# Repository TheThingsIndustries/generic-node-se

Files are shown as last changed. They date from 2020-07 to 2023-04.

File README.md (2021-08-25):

# Generic Node Sensor Edition (GNSE)

## About

LoRaWAN promised you roaming, secure and low-cost sensors that last on a battery for years. _Generic Node_ platform delivers this promise with additional strong end to end encryption and firmware over the air update in a device with multiple sensors that can be configured and programmed to support many use cases.

This repository contains all the necessary hardware and software files for the GNSE LoRaWAN node. The core of the system is based off the STM32WL55xx dual-core LoRaWAN SOC.

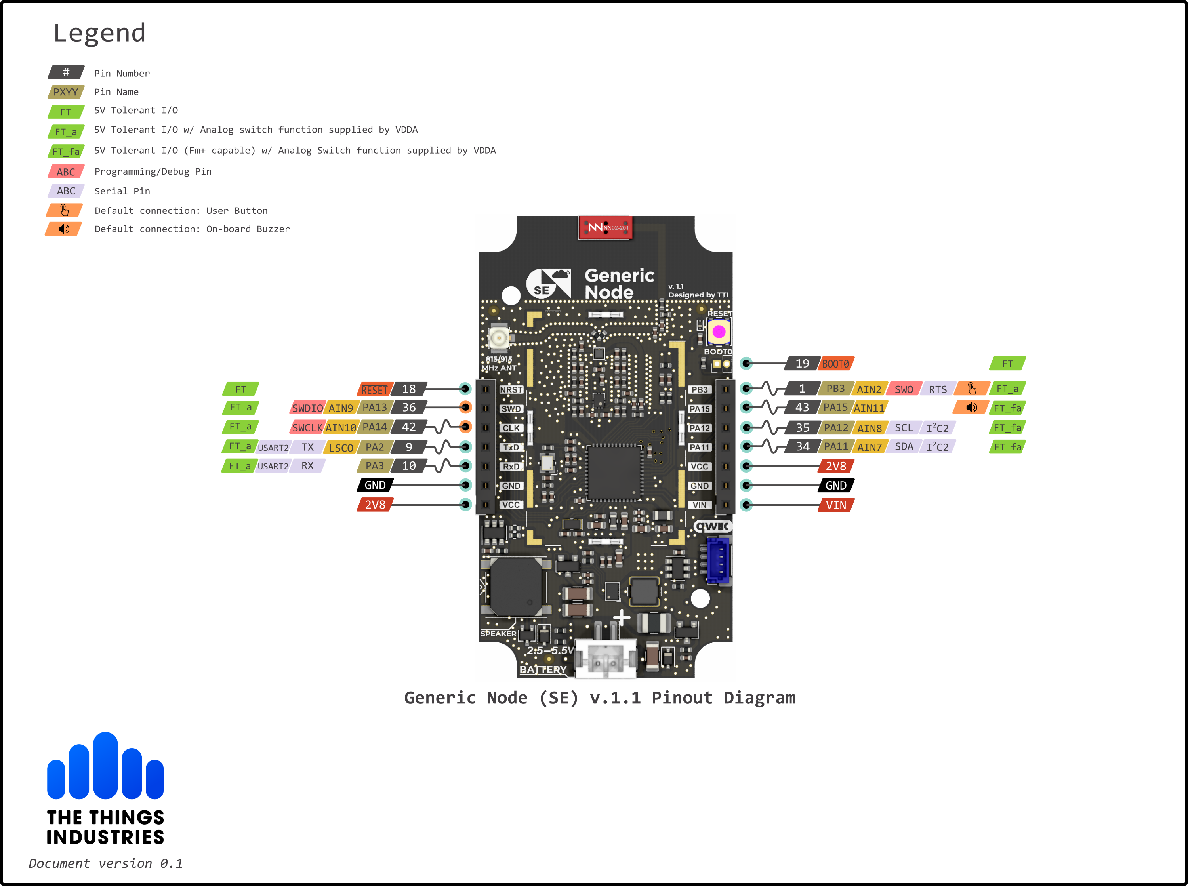
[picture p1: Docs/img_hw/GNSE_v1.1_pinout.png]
Generic Node Main PCB (front)


## Specification
- [STM32WL55CCU6](https://www.st.com/en/microcontrollers-microprocessors/stm32wl-series.html) dual-core Arm Cortex®-M4/M0+ @48 MHz
- 256 Kbytes of Flash & 64 Kbytes of SRAM
- SX126x sub-GHz radio
- Power output up to +22.00 dBm
- LoRa, (G)FSK, (G)MSK, BPSK modulations
- 868 MHz & 915 MHz dual-band operation
- 2xAA battery powered node with wide input voltage range: 2.2V - 5.5V
- [ATECC608A-TNGLORA](https://www.microchip.com/wwwproducts/en/ATECC608A-TNGLORA) pre-provisioned LoRaWAN secure element
- [LIS2DH12](https://www.st.com/en/mems-and-sensors/lis2dh12.html) - ULP 3-axis accelerometer
- [SHTC3](https://www.sensirion.com/en/environmental-sensors/humidity-sensors/digital-humidity-sensor-shtc3-our-new-standard-for-consumer-electronics/) humidity and temperature sensor
- [MX25R1635](https://www.macronix.com/en-us/products/NOR-Flash/Serial-NOR-Flash/Pages/default.aspx) 16Mb SPI NOR Flash for FUOTA and data-logging
- A user button, an RGB LED, a buzzer and a user-friendly expansion and programming options.

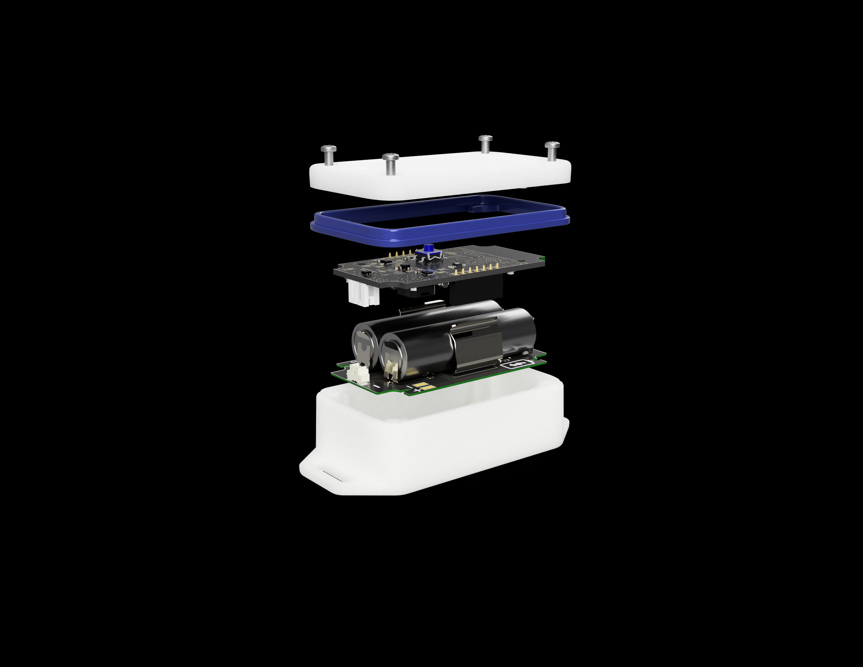
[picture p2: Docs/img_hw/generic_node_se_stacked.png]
Generic Node


## Development

The necessary schematics and the PCB files can be found in [Hardware](./Hardware).

Software libraries and sample applications can be found in [Software](./Software).

## Documentation

The [Generic Node documentation website](https://www.genericnode.com/docs/) provides information about the node hardware and software features.

## Contribution

Our [contribution guideline](./CONTRIBUTING.md) provides more information on how to assist us with the development of GNSE.

## Legal

[Generic Node license terms and conditions](./LICENSE.md) apply.

[Contact The Things Industries](https://thethingsindustries.com/contact/) for licensing.

Copyright © 2021 The Things Industries B.V.

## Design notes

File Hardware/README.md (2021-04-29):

# GNSE Hardware
The reference design hardware provides the needed resources for device production, and the design can be tailored to serve a specific use case.

## Structure

- [sch](./sch/) folder contains the schematics files
- [lib](./lib/) folder contains [KiCad](https://kicad.org/) design libraries
- [pcb-stm32wl](./pcb-stm32wl/) folder contains the layout of the core STM32WL PCB
- [pcb-bolink-batteryHolder](./pcb-bolink-batteryHolder/) folder contains the layout of the bolink enclosure battery holder PCB
- [fab](./fab/) contains fabrication related files such as bill of materials(bom) and gerber files

> Please [contact The Things Industries](https://thethingsindustries.com/contact/) for the latest HW fabrication files

## Documentation

The [Generic Node documentation website](https://www.genericnode.com/docs/) provides information about the hardware features and how to [get started with the hardware development](https://www.genericnode.com/docs/getting-started/se-hw/).

## Legal
Copyright © 2021 The Things Industries B.V.

[Contact The Things Industries](https://thethingsindustries.com/contact/) for licensing.

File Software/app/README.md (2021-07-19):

# Applications

This folder contains various sample applications.

## Applications description

[basic](./basic) contains the simplest application of on-board peripherals activation to ensure responsiveness and basic functionality of the various components.

[basic_lorawan](./basic_lorawan) contains a simple application of LoRaWAN where a class A device joins via OTAA and sends dummy payloads triggered by a time interval or a push button.
The device enters stop mode in between transmissions to reduce power consumption.

[basic_bootloader](./basic_bootloader) contains a bootloader that allows for application/internal bootloader jumps.

[basic_freertos](./basic_freertos) contains a basic FreeRTOS low power application that creates two threads that pass a message via a queue triggering a blinking LED with each passed message.

[freefall_lorawan](./freefall_lorawan) contains a simple application to join via OTAA and waits to send a message until the device is free-falling. A downlink on port 1 will cause the buzzer to beep, which can be turned off with a button press.

[freertos_lorawan](./basic_freertos) contains a multi-thread FreeRTOS LoRaWAN Class A demo app that joins over OTAA and sends uplink data.

[secure_element_lorawan](./secure_element_lorawan) contains a LoRaWAN application where a class A device joins via OTAA (LoRaWAN v1.0.2) using a HW secure element (ATECC608A-TNGLORA) and sends dummy payloads triggered by a time interval.
This app does not require LoRaWAN keys/EUI configurations. Follow this [tutorial](https://www.thethingsindustries.com/docs/devices/claim-atecc608a/) to claim your device, and your device will join via OTAA automatically.

[basic_azurertos](./basic_azurertos) contains a simple AzureRTOS (ThreadX) application. It includes examples of two threads that pass a message via a queue triggering a blinking LED with each passed message.

[sensors_lorawan](./sensors_lorawan) contains an application that sends sensors data such as battery voltage, temperature and humidity over LoRaWAN.

[basic_fuota](./basic_fuota) contains an application that attempts to do an interoperability test of firmware updates over the air.
The app synchronizes the clock with the application server via `AppTimeReq & Ans` commands and then creates a multicast group and a fragmentation session to receive firmware packets over LoRaWAN.

## Applications configuration

Each application contains a configuration folder that facilitates minor adjustments to the application behavior.

LoRaWAN credentials must be configured to ensure successful uplinks/ OTAA joins.
LoRaWAN applications using the onboard secure element require minimum configurations as the keys and EUIs are stored internally within the hardware secure element.

To quickly get started, navigate to your application `app_conf.h`, and adjust the parameters.

[basic app configurations](./basic/conf/app_conf.h)

[basic_lorawan app configurations](./basic_lorawan/conf/app_conf.h)

[basic_bootloader app configurations](./basic_bootloader/conf/app_conf.h)

[basic_freertos app configurations](./basic_freertos/conf/app_conf.h)

[freefall_lorawan app configurations](./freefall_lorawan/conf/app_conf.h)

[freertos_lorawan app configurations](./basic_freertos/conf/app_conf.h)

[secure_element_lorawan app configurations](./secure_element_lorawan/conf/app_conf.h)

[basic_azurertos app configurations](./basic_azurertos/conf/app_conf.h)

[sensors_lorawan app configurations](./sensors_lorawan/conf/app_conf.h)

[basic_fuota app configurations](./basic_fuota/conf/app_conf.h)

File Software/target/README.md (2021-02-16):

# Target
STM32WL low level target files.

[CMSIS](./CMSIS) is arm Cortex Microcontroller Software Interface Standard hardware/vendor abstraction layer.

[stm32wlxx_hal_driver](./stm32wlxx_hal_driver) is maintained as subtree based on [STM32WL HAL](https://github.com/STMicroelectronics/stm32wlxx_hal_driver) and it includes the hardware abstraction layer drivers of the STM32WL SOC.

[FreeRTOS_CMSIS](./FreeRTOS_CMSIS) is FreeRTOS abstraction layer for ST SOC.

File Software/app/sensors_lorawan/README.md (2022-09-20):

# sensosrs_lorawan

## Description

This application samples the on-board device sensors information and transmits the sensor data over LoRaWAN.

## Configuration

The application behavior can be adjusted by modifying [`conf/app_conf.h`](./conf/app_conf.h).

- `GNSE_ADVANCED_TRACER_ENABLE` enables UART (115200/8-N-1) logging of application activity

```c
#define GNSE_ADVANCED_TRACER_ENABLE 1
```

- `DEBUGGER_ON` enables the use of a debugger in low power mode

```c
#define DEBUGGER_ON       1
```

> **Note:** Please keep in mind that it is best to disable the tracer and debugger functionalities to reduce power consumption.

- `APPEUI`, `DEVEUI` and `APPKEY` allow the device to join the LoRaWAN network via OTAA.

```c
#define APPEUI                 0x00, 0x00, 0x00, 0x00, 0x00, 0x00, 0x00, 0x00

#define DEVEUI                 0x00, 0x00, 0x00, 0x00, 0x00, 0x00, 0x00, 0x00

#define APPKEY                 0x00, 0x00, 0x00, 0x00, 0x00, 0x00, 0x00, 0x00, 0x00, 0x00, 0x00, 0x00, 0x00, 0x00, 0x00, 0x00
```

> **Note:** The default `0x00` is a place holder and you are required to change these values in order to achieve a successful activation. For testing purposes, these values can be random.

- `SENSORS_PAYLOAD_APP_PORT` defines LoRaWAN application port where sensors information can be retrieved by the application server.

```c
#define SENSORS_PAYLOAD_APP_PORT        2
```

- `SENSORS_TX_DUTYCYCLE` in millisecond defines the application data transmission interval.

```c
#define SENSORS_TX_DUTYCYCLE                            10000
```

## Setup

The application can be used with the following Javascript payload formatter:

```javascript
function decodeUplink(input) {
  var data = {};
  data.batt_volt = (input.bytes[0]/10);
  data.temperature = (((input.bytes[1] << 8) + input.bytes[2]) - 500)/10;
  data.humidity = ((input.bytes[3] << 8) + input.bytes[4])/10;
  data.button = input.bytes[5];

  return {
    data: data,
  };
}
```
Please see [The Things Stack Javascript payload formatter documentation](https://www.thethingsindustries.com/docs/integrations/payload-formatters/javascript/) for more information.

## Observation

The device joins via OTAA, and transmits the temperature, humidity and battery voltage information every `SENSORS_TX_DUTYCYCLE`.

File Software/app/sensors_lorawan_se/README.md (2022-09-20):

# sensors_lorawan_se

## Description

This application samples the on-board device sensors information and transmits the sensor data over LoRaWAN and showcases a HW secure element (ATECC608A-TNGLORA).
You can learn more about LoRaWAN and HW secure elements from [here](https://www.thethingsindustries.com/secure-elements/) and [here](https://www.thethingsindustries.com/docs/devices/atecc608a/).

## Configuration

The application behavior can be adjusted by modifying [`conf/app_conf.h`](./conf/app_conf.h).

- `GNSE_ADVANCED_TRACER_ENABLE` enables UART (115200/8-N-1) logging of application activity

```c
#define GNSE_ADVANCED_TRACER_ENABLE 1
```

- `DEBUGGER_ON` enables the use of a debugger in low power mode

```c
#define DEBUGGER_ON       1
```

> **Note:** Please keep in mind that it is best to disable the tracer and debugger functionalities to reduce power consumption.

- `APPEUI`, `DEVEUI` and `APPKEY` allow the device to join the LoRaWAN network via OTAA.

```c
#define APPEUI                 0x00, 0x00, 0x00, 0x00, 0x00, 0x00, 0x00, 0x00

#define DEVEUI                 0x00, 0x00, 0x00, 0x00, 0x00, 0x00, 0x00, 0x00

#define APPKEY                 0x00, 0x00, 0x00, 0x00, 0x00, 0x00, 0x00, 0x00, 0x00, 0x00, 0x00, 0x00, 0x00, 0x00, 0x00, 0x00
```

> **Note:** The default `0x00` is a place holder and you are required to change these values in order to achieve a successful activation. For testing purposes, these values can be random.

- `SENSORS_PAYLOAD_APP_PORT` defines LoRaWAN application port where sensors information can be retrieved by the application server.

```c
#define SENSORS_PAYLOAD_APP_PORT        2
```

- `SENSORS_TX_DUTYCYCLE` in minutes defines the application data transmission interval.

```c
#define SENSORS_TX_DUTYCYCLE                            10
```

## Setup

Follow this [tutorial](https://www.thethingsindustries.com/docs/devices/claim-atecc608a/) to claim your device, and your device will join via OTAA automatically.

The application can be used with the following Javascript payload formatter:

```javascript
function decodeUplink(input) {
  var data = {};
  data.batt_volt = (input.bytes[0]/10);
  data.temperature = (((input.bytes[1] << 8) + input.bytes[2]) - 500)/10;
  data.humidity = ((input.bytes[3] << 8) + input.bytes[4])/10;
  data.button = input.bytes[5];

  return {
    data: data,
  };
}
```
Please see [The Things Stack Javascript payload formatter documentation](https://www.thethingsindustries.com/docs/integrations/payload-formatters/javascript/) for more information.

## Observation

The device joins via OTAA using the on-board secure element and transmits the temperature, humidity and battery voltage information every `SENSORS_TX_DUTYCYCLE`.

## Secure element usage

To compile the app with secure element support, use the `-DWITH_SECURE_ELEMENT=ON` flag
when generating cmake configuration.

To compile without the secure element and with hardcoded keys instead, 
use the `-DWITH_SECURE_ELEMENT=OFF` flag and define the keys in `conf/app_conf.h`

For example:
```bash
cmake ../.. -DWITH_SECURE_ELEMENT=OFF -DCMAKE_BUILD_TYPE=Debug -DCMAKE_TOOLCHAIN_FILE=../../cross.cmake -DTARGET_APP=sensors_lorawan
```

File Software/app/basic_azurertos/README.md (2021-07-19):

# basic_azurertos

## Description

This application provides a basic example of [Microsoft Azure RTOS](https://azure.microsoft.com/en-us/services/rtos/) functionality.

The application creates two threads and a message queue. Thread 1 attempts to pass a message to thread 2 via the queue and then sleeps for `TX_DELAY`. Thread 2 blinks the LED when the sent message is successfully received.

## Configuration

The application behavior can be adjusted by modifying [`conf/app_conf.h`](./conf/app_conf.h).

Key configurations are stated below:

### Azure RTOS

- `MEM_BYTE_POOL_SIZE`,`THREAD_STACK_SIZE`,`QUEUE_SIZE` in bytes defines Azure RTOS memory pool, threads and queue sizes

```c
#define MEM_BYTE_POOL_SIZE 9120

#define THREAD_STACK_SIZE 1024

#define QUEUE_SIZE 100
```

### App activity

- `GNSE_TINY_TRACER_ENABLE` enables UART (115200/8-N-1) logging of application activity

```c
#define GNSE_TINY_TRACER_ENABLE 1
```

- `TX_DELAY` in milliseconds defines the message passing rate from thread 1 to thread 2.

```c
#define TX_DELAY                 (5000)
```

## Observation

The device blinks the blue LED every `TX_DELAY` on each successful message passing between thread 1 and thread 2.

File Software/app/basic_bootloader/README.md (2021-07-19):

# basic_bootloader

## Description

The application provides a basic bootloader that can be combined with other applications to perform a specific functionality at boot time.

> If you want to learn more about the purpose of a bootloader, we recommend reading this great [blog post](https://interrupt.memfault.com/blog/how-to-write-a-bootloader-from-scratch).

`basic_bootloader` performs one of two functionalities based on the GNSE button:

1. If the button is not pressed -> boots the user flashed application
2. If the button is pressed long enough -> boots the ST internal bootloader

## Configuration

`basic_bootloader` key configurations:

### Memory Map

The internal flash (ROM) memory map can be configured to accommodate a bootloader and an application by adjusting the parameters defined in [`memory_map.ld`](./../../target/memory_map.ld).

```
BOOTROM  (rx)  : ORIGIN = 0x08000000, LENGTH = 0x00000B000   /* Flash memory dedicated to bootloader */
APPROM   (rx)  : ORIGIN = 0x0800B000, LENGTH = 0x000035000   /* Flash memory dedicated to application */
```

### App activity

The application behavior can be adjusted by modifying [`conf/app_conf.h`](./conf/app_conf.h).

- `GNSE_TINY_TRACER_ENABLE` enables UART (115200/8-N-1) logging of application activity

```c
#define GNSE_TINY_TRACER_ENABLE 1
```

> Please note that it is considered as a best practice to disable logging when building bootloaders to reduce the binary size.

## Setup

To build a `basic_bootloader` that can be combined with another application in the same memory, you need to use a linker script that supports the new memory map.

### Building with CMake

If you are building using CMake, then update [`CMakeLists.txt`](./../../CMakeLists.txt) `LINKER_SCRIPT` flag to `bootloader.ld` when compiling a `basic_bootloader` binary.

```
set(LINKER_SCRIPT ${MCU_DIR}/bootloader.ld)
```

Also, make sure to update `LINKER_SCRIPT` flag to `app.ld` when compiling an application binary that will be combined with the bootloader binary.

```
set(LINKER_SCRIPT ${MCU_DIR}/app.ld)
```

### Building with STM32CubeIDE

If you are building using STM32CubeIDE, then there is no need to change the linker script when building a `basic_bootloader` binary as can be seen below.

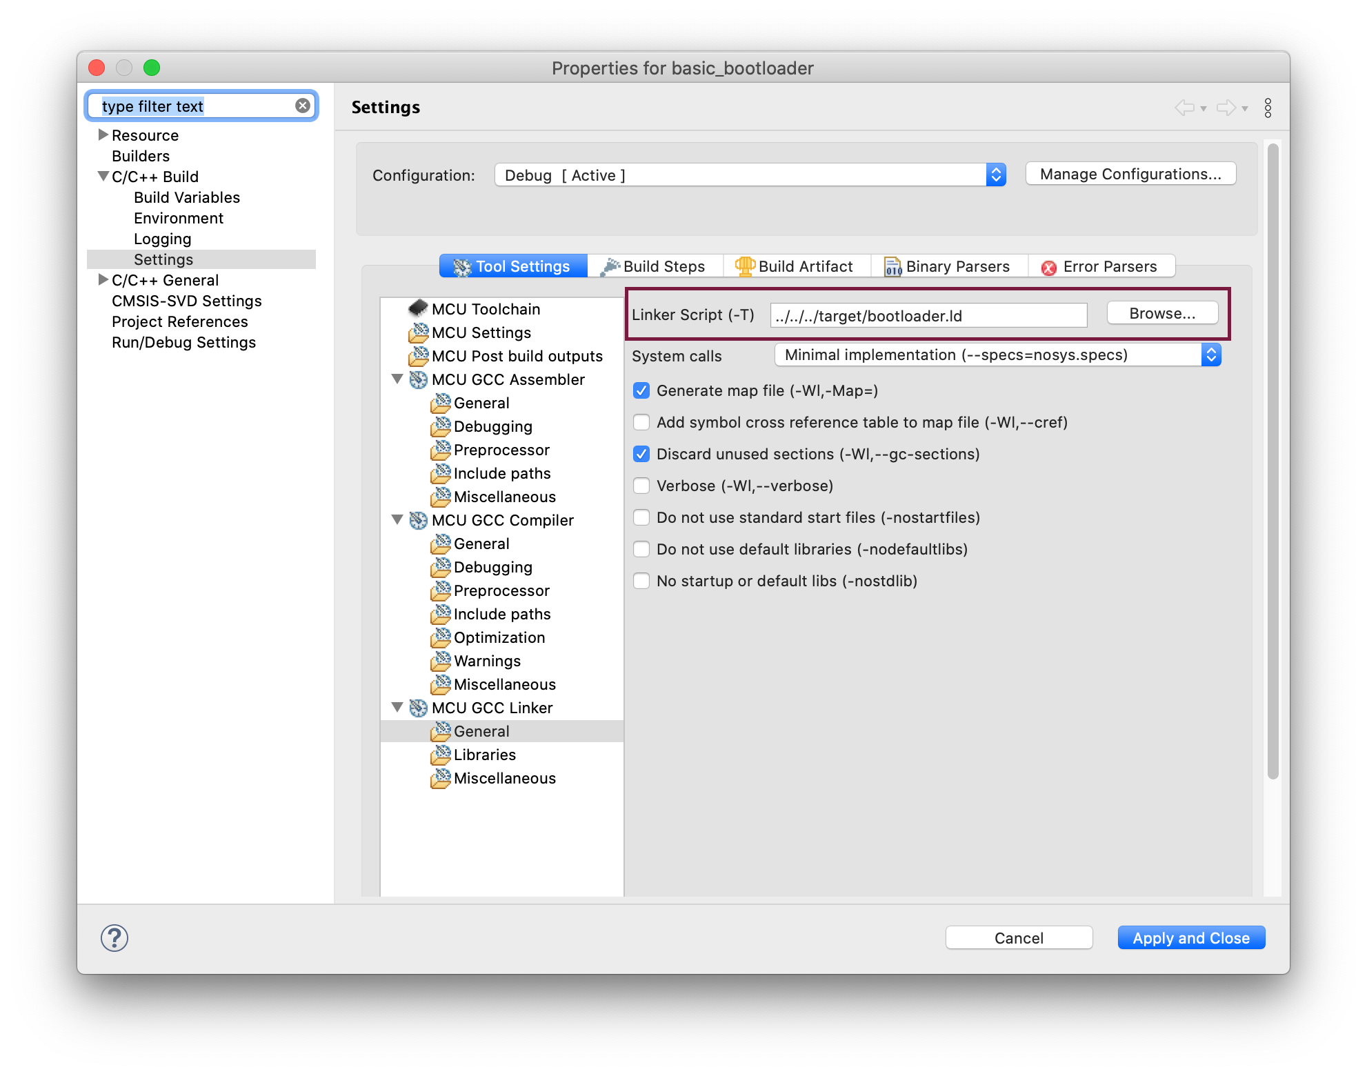
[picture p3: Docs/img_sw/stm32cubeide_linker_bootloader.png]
basic_booloader STM32CubeIDE linker config


But, make sure to change the application linker script from `../../../target/stm32wl55xx_flash.ld` to `../../../target/app.ld`.

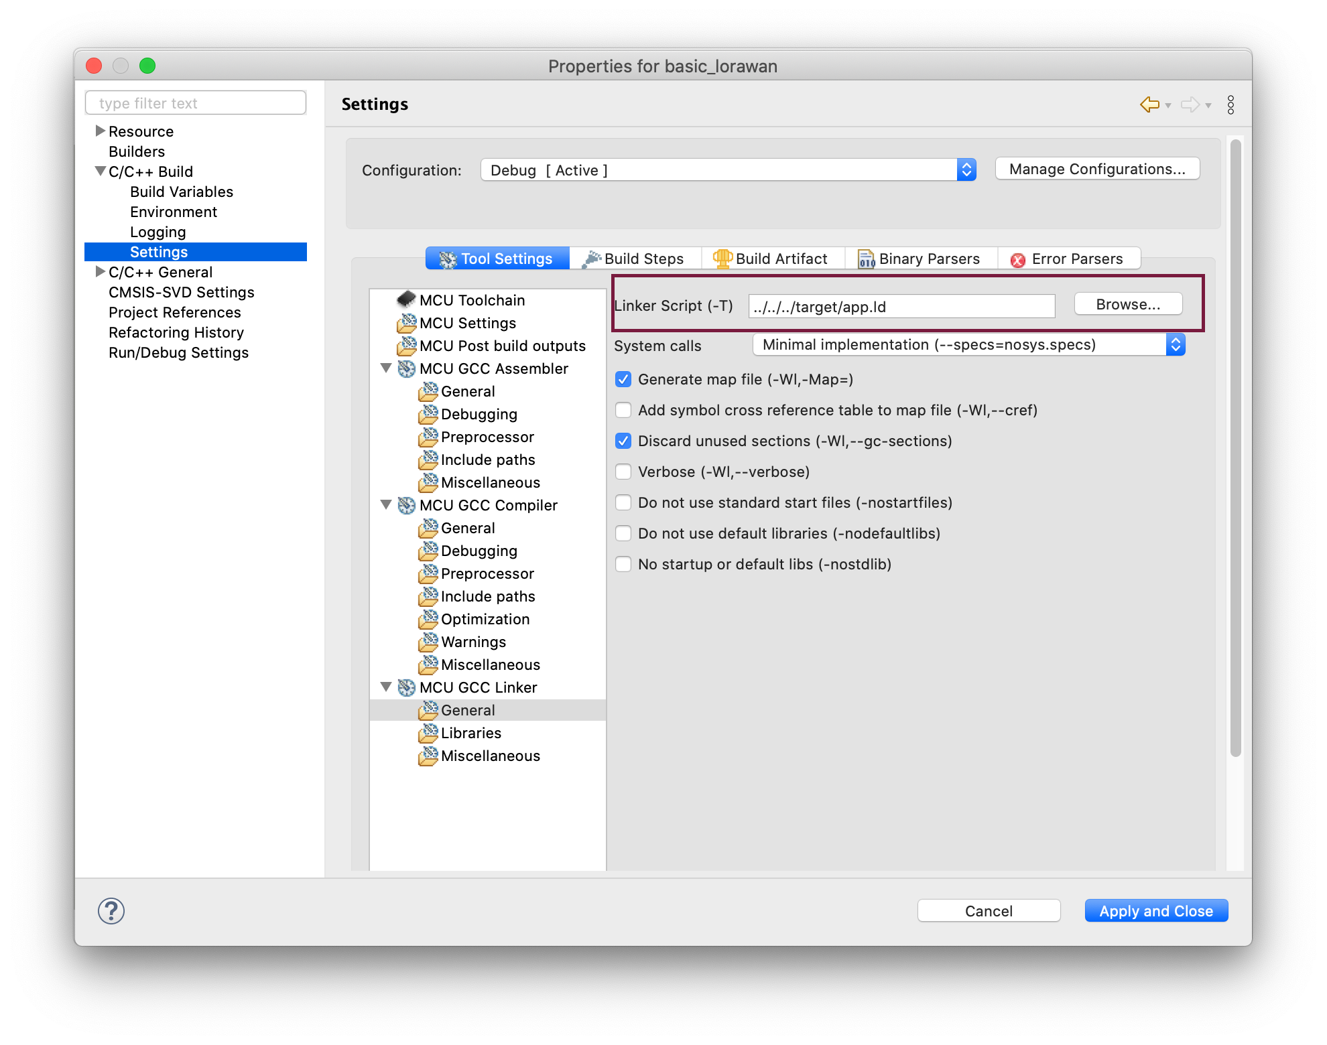
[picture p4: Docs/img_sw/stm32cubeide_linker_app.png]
basic_lorawan STM32CubeIDE linker config


### Combining applications

You can combine two binaries such as the `basic_bootloader` and `basic_lorawan` by using the [`bootloader_app_merge` python script](./../../bootloader_app_merge.py).

For example:

```sh
python bootloader_app_merge.py \
-b ./build/debug/app/basic_bootloader/main.bin \
-a ./build/debug/app/basic_lorawan/main.bin \
-s 1 \
-d 0xB000 \
-c 0xB008 \
-o ./build/debug/app/basic_lorawan/boot_basic_lorawan.bin
```

## Observation

The device boots and turns on the red LED.

If the button is not pressed, the red LED will stay on for a small period and the device will boot the user-flashed application.

If the button is pressed for long enough, it will turn on the blue LED and turn off the red LED, indicating a successful input and it will continue to boot the ST internal bootloader.

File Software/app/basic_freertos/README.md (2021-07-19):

# basic_freertos

## Description

This application provides a basic example of [Amazon FreeRTOS](https://docs.aws.amazon.com/freertos/index.html) functionality.

The application creates two threads and a message queue. Thread 1 attempts to pass a message to thread 2 via the queue and then sleeps for `TX_DELAY`. Thread 2 blinks the LED when the sent message is successfully received.

## Configuration

Key configurations are stated below:

### FreeRTOS

FreeRTOS configurations can be adjusted by modifying [`conf/FreeRTOSConfig.h`](./conf/FreeRTOSConfig.h).

```c
#define configMINIMAL_STACK_SIZE                 ((uint16_t)128)

#define configTOTAL_HEAP_SIZE                    ((size_t)8120)
```

### App activity

The application behavior can be adjusted by modifying [`conf/app_conf.h`](./conf/app_conf.h).

- `GNSE_TINY_TRACER_ENABLE` enables UART (115200/8-N-1) logging of application activity

```c
#define GNSE_TINY_TRACER_ENABLE 1
```

- `TX_DELAY` in milliseconds defines the message passing rate from thread 1 to thread 2.

```c
#define TX_DELAY                 (5000)
```

## Observation

The device blinks the blue LED every `TX_DELAY` on each successful message passing between thread 1 and thread 2.

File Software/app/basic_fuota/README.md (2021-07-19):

# basic_fuota

## Description

This application provides a basic example of LoRaWAN FUOTA (Firmware Update Over The Air) functionality based on:

- [LoRaWAN Remote Multicast Setup Specification v1.0.0.](https://lora-alliance.org/resource_hub/lorawan-remote-multicast-setup-specification-v1-0-0/)
- [LoRaWAN Fragmented Data Block Transport Specification v1.0.0.](https://lora-alliance.org/resource_hub/lorawan-fragmented-data-block-transport-specification-v1-0-0/)
- [LoRaWAN Application Layer Clock Synchronization Specification v1.0.0.](https://lora-alliance.org/resource_hub/lorawan-application-layer-clock-synchronization-specification-v1-0-0/)

`basic_fuota` provides an example on how to:

- Synchronize the device clock via `AppTimeReq & Ans`
- Setup a multicast group via `McGroupSetupReq & Ans`
- Setup a class C session via `McClassCsessionReq & Ans`
- Setup a fragmentation session via `FragSessionSetupReq & Ans`
- Transfer fragmented data and do CRC32 check to confirm data correctness

## Configuration

Below are key configurations:

### Fragmentation

This application performs the FUOTA interoperability test, and the number of fragmented bytes can be modified from the default values of 995 bytes in [`FragDecoder.h`](./../../lib/STM32WLxx_LoRaWAN/LoRaWAN/LmHandler/Packages/FragDecoder.h)

```c
#define FRAG_MAX_NB                                 21

#define FRAG_MAX_SIZE                               50
```

### App activity

The application behavior can be adjusted by modifying [`conf/app_conf.h`](./conf/app_conf.h).

- `GNSE_ADVANCED_TRACER_ENABLE` enables UART (115200/8-N-1) logging of application activity

```c
#define GNSE_ADVANCED_TRACER_ENABLE 1
```

- `DEBUGGER_ON` enables the use of a debugger in low power mode

```c
#define DEBUGGER_ON       1
```

> **Note:** Please keep in mind that it is best to disable the tracer and debugger functionalities to reduce power consumption.

- `APPEUI`, `DEVEUI` and `APPKEY` allow the device to join the LoRaWAN network via OTAA.

```c
#define APPEUI                 0x00, 0x00, 0x00, 0x00, 0x00, 0x00, 0x00, 0x00

#define DEVEUI                 0x00, 0x00, 0x00, 0x00, 0x00, 0x00, 0x00, 0x00

#define APPKEY                 0x00, 0x00, 0x00, 0x00, 0x00, 0x00, 0x00, 0x00, 0x00, 0x00, 0x00, 0x00, 0x00, 0x00, 0x00, 0x00
```

> **Note:** The default `0x00` is a place holder and you are required to change these values in order to achieve a successful activation. For testing purposes, these values can be random.

## Setup

### Device setup

- Follow [this](https://www.thethingsindustries.com/docs/devices/adding-devices/) guide to add your device to The Things Stack.

### Server setup

- You can use this example to [test FUOTA server](https://github.com/elsalahy/test-fuota-server) as starting point and you can follow the [`README.md`](https://github.com/elsalahy/test-fuota-server/blob/master/README.md) in order to set it up with a minimal effort.

## Observation

This [video](https://drive.google.com/file/d/1RnhQjbfYMriDybziEVhzww6uxYF-QaNV/view?usp=sharing) provides a recorded example of the communication between the device and the application server.

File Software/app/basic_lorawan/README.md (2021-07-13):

# basic\_lorawan

## Description

`basic_lorawan` serves as a basic template for LoRaWAN applications.

## Configuration

### Default

1. Follow [this](https://www.thethingsindustries.com/docs/devices/adding-devices/) guide to add your device to The Things Stack.
2. Change the `APPEUI`, `DEVEUI` and `APPKEY` in [`conf/app_conf.h`](./conf/app_conf.h) to the values specific to your device, which are used on The Things Stack.
3. Uncomment the `REGION` parameters in [`conf/lorawan_conf.h`](./conf/lorawan_conf.h) and set `ACTIVE_REGION` in [`lora_app.h`](./lora_app.h). These should correspond to the location that you use these devices at.

### Low power

1. Set `GNSE_ADVANCED_TRACER_ENALBE` to `0` in [`conf/app_conf.h`](./conf/app_conf.h). This will make the device consume less power, but also disables UART.
2. Set `DEBUGGER_ON` to `0` in [`conf/app_conf.h`](./conf/app_conf.h).

Additionally, try to remember that:

- Setting `DEBUGGER_ON` to `1` will consume more power. The debugger is ON by default using the macro `DEBUGGER_ON` in [`conf/app_conf.h`](./conf/app_conf.h).
- Keeping peripherals (such as the sensors) off by controlling the load switches will significantly reduce the power consumption.
- The less transmissions over time, the lower the power consumption will be. This is set by `APP_TX_DUTYCYCLE` in [`lora_app.h`](./lora_app.h).

### LoRa extra's

Some extra setup configurations can be done to change the behaviour of the LoRaWAN features. These include:

1. Setting the activation method (OTAA or ABP) in `LORAWAN_DEFAULT_ACTIVATION_TYPE` in [`lora_app.h`](./lora_app.h). OTAA [is recommended](https://www.thethingsindustries.com/docs/devices/abp-vs-otaa/).
2. The data rate can be set in [`lora_app.h`](./lora_app.h). The default configuration uses the ADR. Should you want to set your preferred data rate, set `LORAWAN_ADR_STATE` to `LORAMAC_HANDLER_ADR_OFF` and set `LORAWAN_DEFAULT_DATA_RATE` to your preference. A list of the options per region are shown in [`Region.h`](../../lib/STM32WLxx_LoRaWAN/LoRaWAN/Mac/region/Region.h) in the [`STM32WLxx_LoRaWAN`](../../lib/STM32WLxx_LoRaWAN) library.
3. `ACC_FF_LORA_PORT` can be changed in [`conf/app_conf.h`](./conf/app_conf.h), which is used to configure the transmission port. The LoRaWAN keys mentioned in the default section can be altered here as well.

### Debugger

For debugging, the firmware has to support it first. The debugger is set in the macro `DEBUGGER_ON` in [`conf/app_conf.h`](./conf/app_conf.h).

## Observation

The standard payload is "**AA BB CC**", which will repeat periodically, with intervals set in `APP_TX_DUTYCYCLE` in [`lora_app.h`](./lora_app.h). The UART output can be read through the TX/RX lines, which can be used for debugging. The default UART configuration is set to 115200/8-N-1. If nothing can be seen on The Things Stack Console, then you could check from this debug output if:

1. The correct keys are used, i.e. they match the ones printed at the start of the application.
2. The device is connecting properly, as it will indicate if connections have failed or not. It should display something like this:

```
###### = JOINED = OTAA =====================
```

3. The device is transmitting anything, since each event is also logged via the UART lines. It should display something similar to:

```
###### ========== MCPS-Confirm =============
###### U/L FRAME:0005 | PORT:2 | DR:5 | PWR:0 | MSG TYPE:UNCONFIRMED
60s069:TX on freq 868500000 Hz at DR 5
60s080:SEND REQUEST
```

4. Downlinks are detected only if used. These only occur after being explicitly set on The Things Stack Console or another application, and will only be transmitted after the transmission of an uplink by the device. The GNSE should, after receiving the downlink, display something similar to:

```
 ###### ========== MCPS-Indication ==========

 ###### D/L FRAME:0002 | SLOT:1 | PORT:1 | DR:5 | RSSI:-44 | SNR:15

 Received 3 bytes on undefined port: 2
```

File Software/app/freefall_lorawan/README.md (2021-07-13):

# freefall\_lorawan

## Description

This application is used to detect free fall events and also serves as a template for acceleration detection handling. Each time a free fall event is detected by the accelerometer, a message containing a counter in the payload is sent. The transmitted value is incremented each time the event occurs. Additionally, if a downlink is received over the correct port, which can be configured by the user, the buzzer will beep periodically to notify locally that the GNSE should be picked up. The buzzer can be turned off by pressing the user button.

## Configuration

### Default
1. Follow [this](https://www.thethingsindustries.com/docs/devices/adding-devices/) guide to add your device to The Things Stack.
2. Change the `APPEUI`, `DEVEUI` and `APPKEY` in [`conf/app_conf.h`](./conf/app_conf.h) to the values specific to your device, which are used on The Things Stack.
3. Uncomment the `REGION` parameters in [`conf/lorawan_conf.h`](./conf/lorawan_conf.h) and set `ACTIVE_REGION` in [`lora_app.h`](./lora_app.h). These should correspond to the location that you use these devices at.

### Free fall detection
1. Change `ACC_FF_THRESHOLD` in [`app/conf.h`](./conf/app_conf.h) to a value you prefer. This will determine the threshold where all axis can be from 0g (which would indicate that it is free falling) to be considered a free fall event.
2. Change `ACC_FF_DURATION` in [`app/conf.h`](./conf/app_conf.h) to a value you prefer. This will determine how many times the axis have to meet the threshold values. Note that `ACC_FF_ODR` in the same file also affects this.
3. `ACC_FF_SCALE` in [`app/conf.h`](./conf/app_conf.h) could also be changed for situations where more than 2g has to be detected. [`LIS2DH12.h`](../../lib/LIS2DH12/LIS2DH12.h) in the [`LIS2DH12`](../../lib/LIS2DH12/) library lists all the options for this in the full scale section.
4. `ACC_FF_ODR` in [`app/conf.h`](./conf/app_conf.h) could be lowered to save power, or increased to improve performance. [`LIS2DH12.h`](../../lib/LIS2DH12/LIS2DH12.h) in the [`LIS2DH12`](../../lib/LIS2DH12/) library lists all the options for this in the `ODR` section.

### Low power

1. Set `GNSE_ADVANCED_TRACER_ENALBE` to `0` in [`conf/app_conf.h`](./conf/app_conf.h). This will make the device consume less power, but also disables UART.
2. Set `DEBUGGER_ON` to `0` in [`conf/app_conf.h`](./conf/app_conf.h).
3. Set `ACC_FF_ODR` in [`app/conf.h`](./conf/app_conf.h) to a lower value if the decreased performance of the free fall detection does not matter for your setup. [`LIS2DH12.h`](../../lib/LIS2DH12/LIS2DH12.h) in the [`LIS2DH12`](../../lib/LIS2DH12/) library lists all the options for this.

Additionally, try to remember that:

- Setting `DEBUGGER_ON` to `1` will consume more power. The debugger is ON by default using the macro `DEBUGGER_ON` in [`conf/app_conf.h`](./conf/app_conf.h).
- Keeping peripherals (such as the sensors) off by controlling the load switches will significantly reduce the power consumption. But, of course, you can not turn the load switch connected to the accelerometer off without disabling the free fall detection as well.

### LoRa extra's

Some extra setup configurations can be done to change the behaviour of the LoRaWAN features. These include:

1. Setting the activation method (OTAA or ABP) in `LORAWAN_DEFAULT_ACTIVATION_TYPE` in [`lora_app.h`](./lora_app.h). OTAA [is recommended](https://www.thethingsindustries.com/docs/devices/abp-vs-otaa/).
2. The data rate can be set in [`lora_app.h`](./lora_app.h). The default configuration uses the ADR. If you want to set your preferred data rate, set `LORAWAN_ADR_STATE` to `LORAMAC_HANDLER_ADR_OFF` and set `LORAWAN_DEFAULT_DATA_RATE` to your preference. A list of the options per region are shown in [`Region.h`](../../lib/STM32WLxx_LoRaWAN/LoRaWAN/Mac/region/Region.h) in the [`STM32WLxx_LoRaWAN`](../../lib/STM32WLxx_LoRaWAN) library.
3. `ACC_FF_LORA_PORT` can be changed in [`conf/app_conf.h`](./conf/app_conf.h), which is used to configure the transmission port. The LoRaWAN keys mentioned in the default section can be altered here as well.
4. Also in [`conf/app_conf.h`](./conf/app_conf.h), the downlink port can be set by altering `ACC_FF_DOWNLINK_PORT`.

### Debugger

For debugging, the firmware has to support it first. The debugger is set in the macro `DEBUGGER_ON` in [`conf/app_conf.h`](./conf/app_conf.h).

## Setup

1. See if your device can detect free fall events. The default values should be enough to trigger on minor drops (try to not break the device) or even sudden movements with your arm whilst holding the GNSE. A message containing the counter should be transmitted, as was mentioned in [`Description`](#description). If none can be seen, try to debug the device as described in the [`Observation`](#observation) section.
2. Test you setup for free fall events and change it to a value you prefer (with the steps in [`Configuration`](#configuration)). Be aware that `ACC_FF_THRESHOLD` would have to be increased to have the accelerometer determine a free fall event has occurred at a lower limit whilst `ACC_FF_DURATION` would have to be decreased for a similar effect.

## Observation

On The Things Stack, the payload should be a single byte starting at one. When a downlink is received on the port set in `ACC_FF_DOWNLINK_PORT` in [`app/conf.h`](./conf/app_conf.h), then the buzzer should start making noises.

The UART on the TX/RX lines can also be used, which are configured to 115200/8-N-1 by default. If you are having troubles with the device, check if the UART output matches these things:

1. The accelerometer is initialized to detect free fall events, which is notified with this message:

```
Accelerometer initialized
```

2. The correct keys are used, i.e. they match the ones printed at the start of the application.
3. The device is connecting properly, as it will indicate if connections have failed or not. It should display something like this:

```
###### = JOINED = OTAA =====================
```

4. The device is transmitting anything, since each event is also logged via the UART lines. It should display something similar to:

```
###### ========== MCPS-Confirm =============
###### U/L FRAME:0005 | PORT:2 | DR:5 | PWR:0 | MSG TYPE:UNCONFIRMED
60s069:TX on freq 868500000 Hz at DR 5
60s080:SEND REQUEST
```

5. Downlinks are detected only if used. These only occur after being explicitly set in The Things Stack Console or another application, and will only be transmitted after the transmission of an uplink by the device. When any data are sent to the port set in `ACC_FF_DOWNLINK_PORT` in [`app/conf.h`](./conf/app_conf.h) then the buzzer can also be heard. Additionally, after receiving the downlink, the GNSE should display something similar to:

```
 ###### ========== MCPS-Indication ==========

 ###### D/L FRAME:0002 | SLOT:1 | PORT:1 | DR:5 | RSSI:-44 | SNR:15

 Received 3 bytes on undefined port: 2
```

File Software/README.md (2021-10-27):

# GNSE Software
The software provides a boilerplate of applications and libraries that can be used as it is or customized to serve a specific use case.

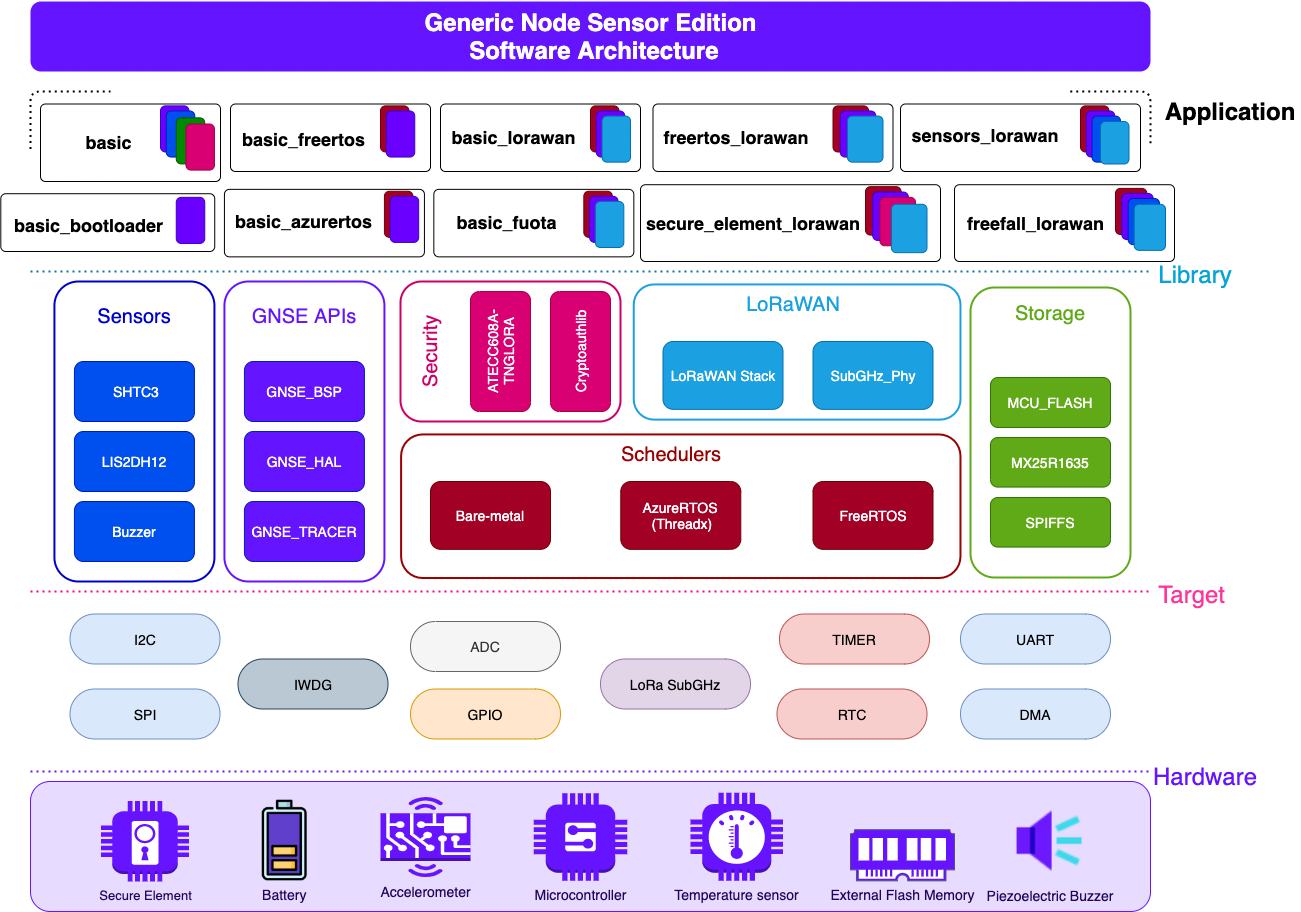
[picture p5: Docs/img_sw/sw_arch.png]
GNSE Software Architecture


## Structure

- [target](./target/README.md) folder contains STM32WL low level target files
- [lib](./lib/README.md) folder contains SW libraries used by the various applications
- [app](./app/README.md) folder contains SW applications

## Documentation

The [Generic Node documentation website](https://www.genericnode.com/docs/) provides information about the software features and how to [get started with the software development](https://www.genericnode.com/docs/getting-started/se-sw/).

Users can also generate a readable [Doxygen](https://www.doxygen.nl/index.html) html file by invoking the following shell command:

```
$ doxygen Docs/doxygen/Doxyfile
```

The generated html file located at `Docs/doxygen/doxygen_out/html/index.html` will contain comprehensive documentation of the source code and the system APIs.

## Legal

Copyright © 2021 The Things Industries B.V.

[Contact The Things Industries](https://thethingsindustries.com/contact/) for licensing.

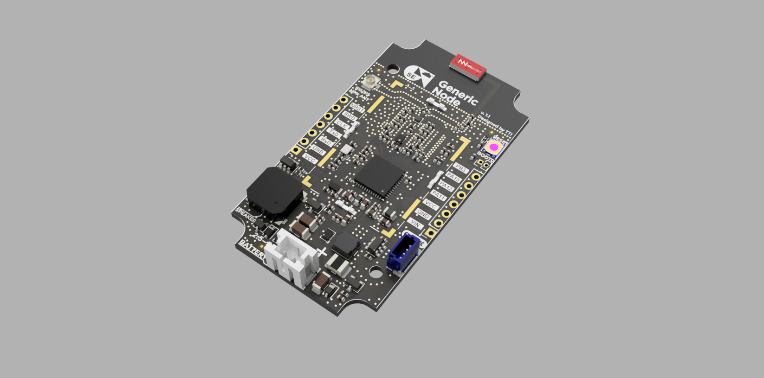
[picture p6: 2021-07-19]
Docs/img_hw/generic_node_se.png

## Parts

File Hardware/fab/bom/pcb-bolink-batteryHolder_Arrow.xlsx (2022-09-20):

Item | Reference | Quantity | Value | MPN | ALT_MPN/Notes | Footprint | URL
 | BT1, BT2 | 4 | PN57 | 36-57-ND |  | node-lib-v1:keystone-PN57 | 57TR by Keystone Electronics | | Arrow.com (https://www.arrow.com/en/products/57tr/keystone-electronics?q=57TR)
 | BTclip1 | 1 | PN69 | 36-69-ND | Requires THT rework | node-lib-v1:Keystone_69_clip | 3096TR by Keystone Electronics | | Arrow.com (https://www.arrow.com/en/products/3096tr/keystone-electronics)
 | J3 | 1 | MOLEX PicoBlade 1.25mm | 533980271 |  | Connector_Molex:Molex_PicoBlade_53398-0271_1x02-1MP_P1.25mm_Vertical | 0533980271 by Molex | Connector Headers and PCB Receptacles | Arrow.com (https://www.arrow.com/en/products/0533980271/molex)
 | J1 |  | DNM | ~ | Solder 60mm JST-PH Cable | TestPoint:TestPoint_Keystone_5019_Minature | ~
 | J2 |  | DNM | ~ | Solder 60mm JST-PH Cable | TestPoint:TestPoint_Keystone_5019_Minature | ~
Part: | Generic Node Battery Holder PCB
Date: | 10/27/2020
Tool: | KiCAD v5.1.8
Total Components: | 6
Unique Components: | 3

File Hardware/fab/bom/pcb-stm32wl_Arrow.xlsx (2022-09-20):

Item | Reference | Quantity | Value | MPN | ALT_MPN/Note | Footprint | URL | Notes
1 | AE1 | 1 | NN02-201 | NN02-201 |  | node-lib-v1:Antenna_Fractus_NN02-201 | https://www.verical.com/pd/ignion-antenna-nn02-201-8417659 | ~ | https://www.richardsonrfpd.com/Products/Product/NN02-201
2 | C12 | 1 | 22uF | CC0603MRX5R5BB226 | JMK107BBJ226MA | Capacitor_SMD:C_0603_1608Metric | CC0603MRX5R5BB226 by Yageo | Capacitor Ceramic Multilayer | Arrow.com (https://www.arrow.com/en/products/cc0603mrx5r5bb226/yageo?q=CC0603MRX5R5BB226) | ~
3 | C13 C15 C27 | 3 | 4.7uF | CL10A475KO8NNNC | C1608X5R1C475K080AC | Capacitor_SMD:C_0603_1608Metric | CL10A475KO8NNNC by Samsung Electro-Mechanics | Capacitor Ceramic Multilayer | Arrow.com (https://www.arrow.com/en/products/cl10a475ko8nnnc/samsung-electro-mechanics?q=CL10A475KO8NNNC) | ~
4 | C34 | 1 | 10nF | CC0402KRX7R7BB103 |  | Capacitor_SMD:C_0402_1005Metric | CC0402KRX7R7BB103 by Yageo | Capacitor Ceramic Multilayer | Arrow.com (https://www.arrow.com/en/products/cc0402krx7r7bb103/yageo?q=CC0402KRX7R7BB103) | ~
5 | C23 | 1 | 47pF | CC0402JRNPO9BN470 |  | Capacitor_SMD:C_0402_1005Metric | CC0402JRNPO9BN470 by Yageo | Capacitor Ceramic Multilayer | Arrow.com (https://www.arrow.com/en/products/cc0402jrnpo9bn470/yageo?q=CC0402JRNPO9BN470) | ~
6 | C25 | 1 | 47nF | CC0402KRX7R8BB473 |  | Capacitor_SMD:C_0402_1005Metric | CC0402KRX7R8BB473 by Yageo | Capacitor Ceramic Multilayer | Arrow.com (https://www.arrow.com/en/products/cc0402krx7r8bb473/yageo?q=CC0402KRX7R8BB473) | ~
7 | C26 | 1 | 68pF | CC0402JRNPO9BN680 |  | Capacitor_SMD:C_0402_1005Metric | CC0402JRNPO9BN680 by Yageo | Capacitor Ceramic Multilayer | Arrow.com (https://www.arrow.com/en/products/cc0402jrnpo9bn680/yageo?q=CC0402JRNPO9BN680) | ~
8 | C28 | 1 | 470nF | CC0603KRX7R7BB474 |  | Capacitor_SMD:C_0603_1608Metric | CC0603KRX7R7BB474 by Yageo | Capacitor Ceramic Multilayer | Arrow.com (https://www.arrow.com/en/products/cc0603krx7r7bb474/yageo?q=CC0603KRX7R7BB474) | ~
9 | C30 C37 C44 | 3 | 2.7pF | CC0402BRNPO9BN2R7 |  | Capacitor_SMD:C_0402_1005Metric | CC0402BRNPO9BN2R7 by Yageo | Capacitor Ceramic Multilayer | Arrow.com (https://www.arrow.com/en/products/cc0402brnpo9bn2r7/yageo?q=CC0402BRNPO9BN2R7) | ~
10 | C31 | 1 | 3.6pF | 0402N3R6B500 | CC0402BRNPO9BN3R6 | Capacitor_SMD:C_0402_1005Metric | 0402N3R6B500CT by Walsin Technology | Capacitor Ceramic Multilayer | Arrow.com (https://www.arrow.com/en/products/0402n3r6b500ct/walsin-technology) | ~
11 | C19 C21 C22 C32 C33 C41 C42 | 7 | 33pF | CC0402GRNPO9BN330 |  | Capacitor_SMD:C_0402_1005Metric | CC0402GRNPO9BN330 by Yageo | Capacitor Ceramic Multilayer | Arrow.com (https://www.arrow.com/en/products/cc0402grnpo9bn330/yageo?q=CC0402GRNPO9BN330) | ~
12 | C35 C46 C49 | 3 | 5.6pF | CC0402BRNPO9BN5R6 |  | Capacitor_SMD:C_0402_1005Metric | CC0402BRNPO9BN5R6 by Yageo | Capacitor Ceramic Multilayer | Arrow.com (https://www.arrow.com/en/products/cc0402brnpo9bn5r6/yageo?q=CC0402BRNPO9BN5R6) | ~
13 | C36 | 1 | 6.8pF | CC0402BRNPO9BN6R8 |  | Capacitor_SMD:C_0402_1005Metric | CC0402BRNPO9BN6R8 by Yageo | Capacitor Ceramic Multilayer | Arrow.com (https://www.arrow.com/en/products/cc0402brnpo9bn6r8/yageo?q=CC0402BRNPO9BN6R8) | ~
14 | C38 | 1 | 2.4pF | CC0402BRNPO9BN2R4 |  | Capacitor_SMD:C_0402_1005Metric | CC0402BRNPO9BN2R4 by Yageo | Capacitor Ceramic Multilayer | Arrow.com (https://www.arrow.com/en/products/cc0402brnpo9bn2r4/yageo?q=CC0402BRNPO9BN2R4) | ~
15 | C39 | 1 | 3.3pF | CC0402BRNPO9BN3R3 | GJM1555C1H3R3WB01 | Capacitor_SMD:C_0402_1005Metric | CC0402BRNPO9BN3R3 by Yageo | Capacitor Ceramic Multilayer | Arrow.com (https://www.arrow.com/en/products/cc0402brnpo9bn3r3/yageo?q=CC0402BRNPO9BN3R3) | ~
16 | C1 C4 C5 | 3 | 100uF | JMK316ABJ107ML-T |  | Capacitor_SMD:C_1206_3216Metric | JMK316ABJ107ML-T by Taiyo Yuden | Capacitor Ceramic Multilayer | Arrow.com (https://www.arrow.com/en/products/jmk316abj107ml-t/taiyo-yuden?q=JMK316ABJ107ML-T) | ~
17 | C40 | 1 | 3.9pF | CC0402BRNPO9BN3R9 |  | Capacitor_SMD:C_0402_1005Metric | CC0402BRNPO9BN3R9 by Yageo | Capacitor Ceramic Multilayer | Arrow.com (https://www.arrow.com/en/products/cc0402brnpo9bn3r9/yageo?q=CC0402BRNPO9BN3R9) | ~
18 | C45 | 1 | 1.3pF | CC0402BRNPO9BN1R3 |  | Capacitor_SMD:C_0402_1005Metric | CC0402BRNPO9BN1R3 by Yageo | Capacitor Ceramic Multilayer | Arrow.com (https://www.arrow.com/en/products/cc0402brnpo9bn1r3/yageo?q=CC0402BRNPO9BN1R3) | ~
19 | C43 C47 C48 C50 | 4 | 1nF | CC0402KRX7R7BB102 |  | Capacitor_SMD:C_0402_1005Metric | CC0402KRX7R7BB102 by Yageo | Capacitor Ceramic Multilayer | Arrow.com (https://www.arrow.com/en/products/cc0402krx7r7bb102/yageo?q=CC0402KRX7R7BB102) | ~
20 | C2 C55 |  | DNM | DNM | CC0402BRNPO9BN3R3 | Capacitor_SMD:C_0402_1005Metric | CC0402BRNPO9BN3R3 by Yageo | Capacitor Ceramic Multilayer | Arrow.com (https://www.arrow.com/en/products/cc0402brnpo9bn3r3/yageo?q=CC0402BRNPO9BN3R3) | ~
21 | C58 | 1 | 10uF | JMK107ABJ106KA-T | C1608X5R0J106K080AB | Capacitor_SMD:C_0603_1608Metric | JMK107ABJ106KA-T by Taiyo Yuden | Capacitor Ceramic Multilayer | Arrow.com (https://www.arrow.com/en/products/jmk107abj106ka-t/taiyo-yuden?q=JMK107ABJ106KA-T) | ~
22 | C3 C6 C8 C11 | 4 | 1uF | CL05A105KQ5NNNC |  | Capacitor_SMD:C_0402_1005Metric | CL05A105KQ5NNNC by Samsung Electro-Mechanics | Capacitor Ceramic Multilayer | Arrow.com (https://www.arrow.com/en/products/cl05a105kq5nnnc/samsung-electro-mechanics?q=CL05A105KQ5NNNC) | ~
23 | C7 C9 C10 C14 C16 C17 C18 C20 C24 C29 C57 C59 C60 C61 C62 C63 C64 C65 | 18 | 100nF | CC0402KRX7R7BB104 |  | Capacitor_SMD:C_0402_1005Metric | CC0402KRX7R7BB104 by Yageo | Capacitor Ceramic Multilayer | Arrow.com (https://www.arrow.com/en/products/cc0402krx7r7bb104/yageo?q=CC0402KRX7R7BB104) | ~
24 | D1 | 1 | PESD5V0S1BA | PESD5V0S1BA,115 | PESD5V0S1BA-N | Diode_SMD:D_SOD-323 | PESD5V0S1BA,115 by Nexperia | ESD Suppressors | Arrow.com (https://www.arrow.com/en/products/pesd5v0s1ba115/nexperia?q=PESD5V0S1BA,115) | ~
25 | D2 | 1 | 1N4148WSF-7 | 1N4148WSF-7 |  | Diode_SMD:D_SOD-323F | 1N4148WSF-7 by Diodes Incorporated | Rectifiers | Arrow.com (https://www.arrow.com/en/products/1n4148wsf-7/diodes-incorporated?q=1N4148WSF-7) | ~
26 | D3 | 1 | FM-B2020RGBA | FM-B2020RGBA-HG |  | LED_SMD:LED_Cree-PLCC4_2x2mm_CW | https://lcsc.com/product-detail/Light-Emitting-Diodes-LED_Foshan-NationStar-Optoelectronics-FM-B2020RGBA-HG_C108793.html | ~
27 | D4 D5 | 2 | ESD9D5V | ESD9D5V |  | Diode_SMD:D_SOD-923 | https://lcsc.com/product-detail/TVS_Leiditech-ESD9D5V_C384848.html | ~
28 | F1 | 1 | 16V 3A 110mΩ PTC | 1210L150/16WR |  | Fuse:Fuse_1210_3225Metric_Castellated | 1210L150/16WR by Littelfuse | PTC Resettable Fuses | Arrow.com (https://www.arrow.com/en/products/1210l15016wr/littelfuse?q=1210L150%2F16WR) | ~
29 | FB1 | 1 | 600R @100MHz | BLM18AG601SN1D |  | Inductor_SMD:L_0603_1608Metric | BLM18AG601SN1D by Murata Manufacturing | Ferrite Beads | Arrow.com (https://www.arrow.com/en/products/blm18ag601sn1d/murata-manufacturing?q=BLM18AG601SN1D) | ~
30 | J1 J3 J5 J6 | 4 | S1001-46R | S1001-46R |  | node-lib-v1:RF_Shield_Clip_S1001-46R | S1001-46R | Arrow.com (https://www.arrow.com/en/products/search?datasheets=true&selectedType=product&q=S1001-46R) | ~
31 | J10 | 1 | Qwiic | BM04B-SRSS-TB(LF)(SN) |  | Connector_JST:JST_SH_BM04B-SRSS-TB_1x04-1MP_P1.00mm_Vertical | BM04B-SRSS-TB(LFSN) by J.S.T.MFG.CO.,LTD | Connector Headers and PCB Receptacles | Arrow.com (https://www.arrow.com/en/products/bm04b-srss-tb-lf-sn/jst-manufacturing) | ~
32 | J2 | 1 | JST-PH | B2B-PH-SM4-TB(LF)(SN) |  | Connector_JST:JST_PH_B2B-PH-SM4-TB_1x02-1MP_P2.00mm_Vertical | B2B-PH-SM4-TB (LF)(SN) by J.S.T.MFG.CO.,LTD | Connector Headers and PCB Receptacles | Arrow.com (https://www.arrow.com/en/products/b2b-ph-sm4-tb-lf-sn/jst-manufacturing) | ~
33 | J4 | 1 | RF_Shield_One_Piece | DMN – Custom | S02-30200250 | node-lib-v1:Harwin_S02-30200250_30x20mm_GND_Pads | S02-30200250 | Arrow.com (https://www.arrow.com/en/products/search?datasheets=true&selectedType=product&q=S02-30200250) | ~
34 | J7 | 1 | U.FL/iPEX | U.FL-R-SMT-1(10) |  | Connector_Coaxial:U.FL_Hirose_U.FL-R-SMT-1_Vertical | U.FL-R-SMT-1(10) HIROSE ELECTRIC - RF Connector | Verical (https://www.verical.com/pd/hirose-electric-rf-connector-u.fl-r-smt-1%2810%29-457314) | ~
35 | J8 J9 | 2 | DEBUG / UART/I2C | 2.54mm PH3.5 7P header | THT | Connector_PinSocket_2.54mm:PinSocket_1x07_P2.54mm_Vertical | https://www.aliexpress.com/item/622209657.html?spm=a2g0o.cart.0.0.5c1d3c00KRaXyV&mp=1 | ~
36 | JP5 | 1 | BOOT0 | C703015 | THT | Connector_PinHeader_1.27mm:PinHeader_1x02_P1.27mm_Vertical | https://lcsc.com/product-detail/Pin-Header-Female-Header_BOOMELE-Boom-Precision-Elec-1-27mm-1-2P_C703015.html | ~
37 | L1 | 1 | 2.2uH | HPC4012TF-2R2M |  | node-lib-v1:L_HPC4012TF-2R2M | https://lcsc.com/product-detail/Power-Inductors_TAI-TECH-HPC4012TF-2R2M_C357047.html | ~
38 | L10 | 1 | 1400R @1GHz | BLM15HG102SN1D |  | Inductor_SMD:L_0402_1005Metric | BLM15HG102SN1D by Murata Manufacturing | Ferrite Beads | Arrow.com (https://www.arrow.com/en/products/blm15hg102sn1d/murata-manufacturing?q=BLM15HG102SN1D) | ~
39 | L11 | 1 | 6.8nH | LQW15AN6N8H00D |  | Inductor_SMD:L_0402_1005Metric | LQW15AN6N8H00D by Murata Manufacturing | Inductor Surface Mount | Arrow.com (https://www.arrow.com/en/products/lqw15an6n8h00d/murata-manufacturing?q=LQW15AN6N8H00D) | ~
40 | L12 | 1 | 8.7nH | LQW15AN8N7H00D |  | Inductor_SMD:L_0402_1005Metric | LQW15AN8N7H00D by Murata Manufacturing | Inductor Surface Mount | Arrow.com (https://www.arrow.com/en/products/lqw15an8n7h00d/murata-manufacturing?q=LQW15AN8N7H00D) | ~
41 | L13 | 1 | 27nH | LQW15AN27NG00 |  | Inductor_SMD:L_0402_1005Metric | LQW15AN27NG00D by Murata Manufacturing | Inductor Surface Mount | Arrow.com (https://www.arrow.com/en/products/lqw15an27ng00d/murata-manufacturing) | ~
42 | L14 | 1 | 6.5nH | LQW15AN6N5G80 |  | Inductor_SMD:L_0402_1005Metric | LQW15AN6N5G80D by Murata Manufacturing | Inductor Surface Mount | Arrow.com (https://www.arrow.com/en/products/lqw15an6n5g80d/murata-manufacturing) | ~
43 | L15 | 1 | 8nH | LQW15AN8N0G80 |  | Inductor_SMD:L_0402_1005Metric | LQW15AN8N0G80D by Murata Manufacturing | Inductor Surface Mount | Arrow.com (https://www.arrow.com/en/products/lqw15an8n0g80d/murata-manufacturing)
44 | L3 | 1 | 3.6nH | LQW15AN3N6C10D |  | Inductor_SMD:L_0402_1005Metric | LQW15AN3N6C10D by Murata Manufacturing | Inductor Surface Mount | Arrow.com (https://www.arrow.com/en/products/lqw15an3n6c10d/murata-manufacturing?q=LQW15AN3N6C10D) | ~
45 | L4 | 1 | 15uH | MLZ2012M150WT000 |  | Inductor_SMD:L_0805_2012Metric | MLZ2012M150WT000 by TDK | Inductor Surface Mount | Arrow.com (https://www.arrow.com/en/products/mlz2012m150wt000/tdk?q=MLZ2012M150WT000) | ~
46 | L5 | 1 | 11nH | LQW15AN11NG00D |  | Inductor_SMD:L_0402_1005Metric | LQW15AN11NG00D by Murata Manufacturing | Inductor Surface Mount | Arrow.com (https://www.arrow.com/en/products/lqw15an11ng00d/murata-manufacturing?q=LQW15AN11NG00D) | ~
47 | L6 L7 | 2 | 47nH | LQW15AN47NJ00D |  | Inductor_SMD:L_0402_1005Metric | LQW15AN47NJ00D by Murata Manufacturing | Inductor Surface Mount | Arrow.com (https://www.arrow.com/en/products/lqw15an47nj00d/murata-manufacturing?q=LQW15AN47NJ00D) | ~
48 | L8 | 1 | 3nH | LQW15AN3N0B00 |  | Inductor_SMD:L_0402_1005Metric | LQW15AN3N0B00D by Murata Manufacturing | Inductor Surface Mount | Arrow.com (https://www.arrow.com/en/products/lqw15an3n0b00d/murata-manufacturing) | ~
49 | L2 L9 | 2 | 3.3nH | LQW15AN3N3C80D |  | Inductor_SMD:L_0402_1005Metric | LQW15AN3N3C80D by Murata Manufacturing | Inductor Surface Mount | Arrow.com (https://www.arrow.com/en/products/lqw15an3n3c80d/murata-manufacturing?q=LQW15AN3N3C80D) | ~
50 | PZ1 | 1 | MLT-7525 | MLT-7525 |  | node-lib-v1:Buzzer_MLT-7525 | https://lcsc.com/product-detail/Buzzers_Jiangsu-Huaneng-Elec-MLT-7525_C95299.html | ~
51 | Q1 | 1 | PMV32UP,215 | PMV32UP,215 |  | Package_TO_SOT_SMD:SOT-23 | PMV32UP,215 by Nexperia | MOSFETs | Arrow.com (https://www.arrow.com/en/products/pmv32up215/nexperia?q=PMV32UP,215) | ~
52 | Q2 | 1 | PMST4401,115 | PMST4401,115 |  | Package_TO_SOT_SMD:SOT-323_SC-70 | PMST4401,115 by Nexperia | GP BJT | Arrow.com (https://www.arrow.com/en/products/pmst4401115/nexperia?q=PMST4401,115) | ~
53 | R13 R20 | 2 | 10K | AC0402JR-0710KL |  | Resistor_SMD:R_0402_1005Metric | AC0402JR-0710KL by Yageo | Resistor Fixed Single-Surface Mount | Arrow.com (https://www.arrow.com/en/products/ac0402jr-0710kl/yageo?q=AC0402JR-0710KL) | ~
54 | R10 R11 R12 |  | DNM | DNM |  | Resistor_SMD:R_0402_1005Metric |  | ~
55 | R16 R21 | 2 | 1K | RC0402FR-071KL |  | Resistor_SMD:R_0402_1005Metric | RC0402FR-071KL by Yageo | Resistor Fixed Single-Surface Mount | Arrow.com (https://www.arrow.com/en/products/rc0402fr-071kl/yageo) | ~
56 | R14 R15 R17 R18 | 4 | 4K7 | AC0402FR-074K7L |  | Resistor_SMD:R_0402_1005Metric | AC0402FR-074K7L Yageo | Resistor Fixed Single-Surface Mount | Arrow.com (https://www.arrow.com/en/products/ac0402fr-074k7l/yageo?q=AC0402FR-074K7L) | ~
57 | R19 | 1 | 33R | AC0402JR-0733RL |  | Resistor_SMD:R_0402_1005Metric | AC0402JR-0733RL by Yageo | Resistor Fixed Single-Surface Mount | Arrow.com (https://www.arrow.com/en/products/ac0402jr-0733rl/yageo?q=AC0402JR-0733RL) | ~
58 | R2 R3 R4 | 3 | 100K | RC0402FR-07100KL |  | Resistor_SMD:R_0402_1005Metric | RC0402FR-07 100KL Yageo | Resistor Fixed Single-Surface Mount | Arrow.com (https://www.arrow.com/en/products/rc0402fr-07100kl/yageo) | ~
59 | R22 R23 | 2 | 330R | AC0402FR-07330RL |  | Resistor_SMD:R_0402_1005Metric | AC0402FR-07330RL by Yageo | Resistor Fixed Single-Surface Mount | Arrow.com (https://www.arrow.com/en/products/ac0402fr-07330rl/yageo?q=AC0402FR-07330RL) | ~
60 | R5 | 1 | 220R | RC0402FR-07220RL |  | Inductor_SMD:L_0402_1005Metric | RC0402FR-07220RL Yageo | Resistor Fixed Single-Surface Mount | Arrow.com (https://www.arrow.com/en/products/rc0402fr-07220rl/yageo) | ~
61 | R6 R7 R8 R24 | 4 | 100R | RC0402FR-07100RL |  | Resistor_SMD:R_0402_1005Metric | RC0402FR-07100RL by Yageo | Resistor Fixed Single-Surface Mount | Arrow.com (https://www.arrow.com/en/products/rc0402fr-07100rl/yageo) | ~
62 | R1 R9 | 2 | 0R | RC0402FR-070RL |  | Resistor_SMD:R_0402_1005Metric | RC0402FR-070RL by Yageo | Resistor Fixed Single-Surface Mount | Arrow.com (https://www.arrow.com/en/products/rc0402fr-070rl/yageo?q=RC0402FR-070RL) | ~
63 | SW1 | 1 | USR_BTN | KSC721GLFS |  | node-lib-v1:PushButton_KSC721GLFS | KSC721GLFSB by C&K | Switch Tactile | Arrow.com (https://www.arrow.com/en/products/ksc721glfsb/ck) | ~
64 | SW2 | 1 | RESET | SKSHABE010 |  | node-lib-v1:SW_SPST_SKSHABE010 | SKSHABE010 by ALPS ALPINE CO., LTD | Switch Tactile | Arrow.com (https://www.arrow.com/en/products/skshabe010/alps-electric?q=SKSHABE010) | ~
65 | U1 U3 | 2 | TPS22917DBV | TPS22917DBVR |  | Package_TO_SOT_SMD:SOT-23-6 | TPS22917DBVR by Texas Instruments | Power Switches | Arrow.com (https://www.arrow.com/en/products/tps22917dbvr/texas-instruments?q=TPS22917DBVR) | ~
66 | U10 | 1 | SHTC3 | SHTC3 |  | node-lib-v1:Sensirion_DFN-4-1EP_2x2mm_P1mm_EP0.7x1.6mm | SHTC3-TR-10KS by Sensirion AG | Unclassified | Arrow.com (https://www.arrow.com/en/products/shtc3-tr-10ks/sensirion-ag) | ~
67 | U11 | 1 | ATECC608B-TNGLORAU | ATECC608B-TNGLORAU-C |  | Package_DFN_QFN:DFN-8-1EP_3x2mm_P0.5mm_EP1.3x1.5mm | ATECC608B-TNGLORAU-G by Microchip Technology | Unclassified | Arrow.com (https://www.arrow.com/en/products/atecc608b-tnglorau-g/microchip-technology) | ~
68 | U2 | 1 | TPS3839G18DBZT‎ | TPS3839G18DBZT‎ |  | Package_TO_SOT_SMD:SOT-23 | TPS3839G18DBZT by Texas Instruments | Supervisory Circuits | Arrow.com (https://www.arrow.com/en/products/tps3839g18dbzt/texas-instruments) | ~
69 | U4 | 1 | RP605Z283B | RP605Z283B-E2-F |  | node-lib-v1:WLCSP-20-P3_1.994x1.609mm_Layout5x4_P0.4mm | RP605Z283B-E2-F by Nisshinbo Micro Devices Inc | Unclassified | Arrow.com (https://www.arrow.com/en/products/rp605z283b-e2-f/nisshinbo-micro-devices-inc) | ~
70 | U5 | 1 | STM32WL55CCU6 | STM32WL55CCU6 |  | Package_DFN_QFN:QFN-48-1EP_7x7mm_P0.5mm_EP5.45x5.45mm | STM32WL55CCU6 by STMicroelectronics | | Arrow.com (https://www.arrow.com/en/products/stm32wl55ccu6/stmicroelectronics?q=STM32WL55CCU6) | ~
71 | U6 | 1 | TS3A5223RSWR | TS3A5223RSWR | Backordered – not arrived yet | Package_DFN_QFN:UQFN-10_1.4x1.8mm_P0.4mm | TS3A5223RSWR by Texas Instruments | Analog Switch Multiplexers | Arrow.com (https://www.arrow.com/en/products/ts3a5223rswr/texas-instruments?q=TS3A5223RSWR) | ~
72 | U7 | 1 | BGS13S4N9 | BGS13S4N9E6327XTSA1 |  | node-lib-v1:RFSW_BGS13S4N9E6327XTSA1 | BGS13S4N9E6327XTSA1 by Infineon Technologies AG | RF Switches | Arrow.com (https://www.arrow.com/en/products/bgs13s4n9e6327xtsa1/infineon-technologies-ag?q=BGS13S4N9E6327XTSA1) | ~
73 | U8 | 1 | MX25R1635 | MX25R1635FZUIL0 |  | node-lib-v1:FLASH_UFDFN-8-MX25R1635F | MX25R1635FZUIL0 TR by Macronix International | Flash | Arrow.com (https://www.arrow.com/en/products/mx25r1635fzuil0tr/macronix-international) | ~
74 | U9 | 1 | LIS2DH12 | LIS2DH12TR |  | Package_LGA:LGA-12_2x2mm_P0.5mm | LIS2DH12TR | Accelerometer by STMicroelectronics | Accelerometers | Arrow.com (https://www.arrow.com/en/products/lis2dh12tr/stmicroelectronics) | ~
75 | X1 | 1 | 32MHz | ‎TG2520SMN 32.0000M-MCGNNM3‎ |  | Crystal:Crystal_SMD_Abracon_ABM10-4Pin_2.5x2.0mm | TG2520SMN 32.0000M-MCGNNM3 by Epson America, Inc | Controlled Oscillators | Arrow.com (https://www.arrow.com/en/products/tg2520smn-32.0000m-mcgnnm3/epson-electronics-america) | ~
76 | Y1 | 1 | 32.768KHz | X1A000061002100 |  | node-lib-v1:Crystal_SMD_NX2012SA_32.768KHz | https://www.arrow.com/en/products/fc-12m32.7680ka-a5/epson-electronics-america | ~
Design version: | 1.1b
Date: | 24/05/2021
Tool: | KiCAD v5.1.10
Total Component Count: | 131
Unique Component Count | 74
Legend

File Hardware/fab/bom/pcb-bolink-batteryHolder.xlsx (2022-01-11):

Item | Reference | Quantity | Value | MPN | ALT_MPN/Notes | Footprint | URL
 | BT1, BT2 | 4 | PN57 | 36-57-ND |  | node-lib-v1:keystone-PN57 | https://www.digikey.nl/short/zn47d8
 | BTclip1 | 1 | PN69 | 36-69-ND | Requires THT rework | node-lib-v1:Keystone_69_clip | https://www.digikey.nl/short/zn47d7
 | J3 | 1 | MOLEX PicoBlade 1.25mm | 533980271 |  | Connector_Molex:Molex_PicoBlade_53398-0271_1x02-1MP_P1.25mm_Vertical | https://lcsc.com/product-detail/Wire-To-Board-Wire-To-Wire-Connector_MOLEX_0533980271_MOLEX-0533980271_C122410.html
 | J1 |  | DNM | ~ | Solder 60mm JST-PH Cable | TestPoint:TestPoint_Keystone_5019_Minature | ~
 | J2 |  | DNM | ~ | Solder 60mm JST-PH Cable | TestPoint:TestPoint_Keystone_5019_Minature | ~
Part: | Generic Node Battery Holder PCB
Date: | 10/27/2020
Tool: | KiCAD v5.1.8
Total Components: | 6
Unique Components: | 3

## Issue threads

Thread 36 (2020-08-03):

Advanced v1.1 HW testing

elsalahy, 2020-08-03:
**Summary:**
<!-- Summarize the feature in a few sentences: -->

With the testing of the initial prototypes taking place in #28

We need to move forward and do more advanced testing.
This issue is an umbrella for the planned activities and also separate issues can be opened and linked here.
We can close this issue after the activities are done and we attach a conclusion report.

**Why do we need this?**
<!-- Please explain the motivation, how it will be used, etc -->

To ensure a stable product before moving forward with the production prototypes.

**What is already there? What do you see now?**
<!-- Please attach (or link to) screenshots and logs if applicable -->

Acceptance testing of the prototypes.

**What is missing? What do you want to see?**
<!-- Please add some examples or mock-ups if applicable -->

- Plan advanced testing activities.
- FW libraries that support the advanced tests.
- Conclusion Report.

**How do you propose to implement this?**
<!--
If unsure, add the discussion label and (temporarily) assign the expert
If you cannot assign people, please @mention the experts
-->

- Plan
- Test
- Write-up conclusion

**Environment:**
<!-- Your environment: OS/Browser/Gateway/Device/...? Versions? IDs/EUIs? -->

Bare-metal

**Acceptance Criteria:**
<!--
Please explain the necessary conditions to be satisfied for this feature to be considered implemented.
These may include important test cases that need to pass, expected resource consumption improvements etc.
-->
Cover all essential product requirements.

**What can you do yourself and what do you need help with?**

Workload will be split between me and @azerimaker.

azerimaker, 2021-02-18:
**Problem:** Currently testing the rest of the **v1.1** PCBs. There seem to be quite high number of boards (so far 8/60) with poor solder quality on Buck-Boost converter IC. Since it's a BGA package, pin connections are not visible.

**Solution:** Reflowing (heating with hot air gun) and resoldering them seems to solve the problem. I'll also investigate the gerber and stencil files for potential improvements.

FYI: @wienke @elsalahy

wienke, 2021-02-18:
So this is due to poor manufacturing by Seeed?

azerimaker, 2021-02-18:
> So this is due to poor manufacturing by Seeed?

I don't want to blatantly blame them, without doing any X-ray on every faulty boards, or properly analyzing the solder-paste stencils, but if I see that reflowing solves the problem in every faulty board, it's highly probable.

azerimaker, 2021-03-13:
I've thoroughly investigated two faulty boards (№ 97, 98 on the list), which were not starting up at all. I could hear the buzzer clicking, which indicated that the buck-boost converter is trying to start-up then goes into protection mode. I've first desoldered the IC on board97 and observed that one solder ball was missing. After reballing the pad and resoldering it back the board worked flawlessly.

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

Board98 was also showing the same behavior, so I followed the same procedure and as suspected this board also had missing or smaller than usual solder balls.

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

This IC (RP605) is extremely small (ball-pen for reference) and integrates lots of function in it, but it seems to be the main reason for the lower yield figure in our first beta run (#95).

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

**Possible solution:**
To address this issue in the future we might consider using the bigger QFN package of this IC, but unfortunately it's only available with 3.3V and 2.0V outputs, but we're using 2.8V as our operating voltage.
I'll contact RICOH with regards to this. Maybe we can get a special manufacturing run of 2.8V version. Otherwise we can also consider increasing the operating voltage to 3.3V.

azerimaker, 2021-07-01:
For now with the version v.1.1b we're going to be using WLCSP package of the buck-boost converter, but we'll be getting custom run of DFN package in 2.8V output voltage for our next large-volume run.

Closed 2021-07-01.

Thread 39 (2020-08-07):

[Future_Improvment] Increase I2C and SPI communication frequency

elsalahy, 2020-08-07:
**Summary:**
<!-- Summarize the feature in a few sentences: -->

In the upcoming changes, we should consider increasing the serial bsuses communication frequency to ensure the node goes to sleep for longer periods and the sensor/flash commands are done faster.

**Why do we need this?**
<!-- Please explain the motivation, how it will be used, etc -->

To have a faster system and increase sleep time.

**What is already there? What do you see now?**
<!-- Please attach (or link to) screenshots and logs if applicable -->

Slow frequency configurations.

**What is missing? What do you want to see?**
<!-- Please add some examples or mock-ups if applicable -->

- Increase the frequency to an acceptable rate.
- Test the change effect on the system to ensure it doesn't break functionality.

**How do you propose to implement this?**
<!--
If unsure, add the discussion label and (temporarily) assign the expert
If you cannot assign people, please @mention the experts
-->

- Adjust `FLASH_SPI_BAUDRATE`
- Adjust `SENSOR_I2C1_TIMING`
- Configure the clocks

**Environment:**
<!-- Your environment: OS/Browser/Gateway/Device/...? Versions? IDs/EUIs? -->

Baremetal.

**Acceptance Criteria:**
<!--
Please explain the necessary conditions to be satisfied for this feature to be considered implemented.
These may include important test cases that need to pass, expected resource consumption improvements etc.
-->
- All apps and tests run with no failure on all boards.

**What can you do yourself and what do you need help with?**

All

elsalahy, 2021-02-15:
Please also allow for the following:
1- Configurable Frequency in the BSP Conf
2- Provide multiple frequency options as a comment (all options must be tested).

marnixcrouzen, 2021-02-24:
@elsalahy I had a question about the I2C speed? How was SENESOR_I2C1_TIMING calculated exactly?
https://github.com/TheThingsIndustries/generic-node-se/blob/e73e632008af8deb37c5635224992ba672222532/Software/lib/GNSE_BSP/GNSE_bsp_serial.h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
My logic analyser reads that the SCL pin has a frequency of 147kHz (7us from rise to rise).

elsalahy, 2021-03-01:
@marnixcrouzen This was part of the STM32WL package, and there is a chance it can be incorrect/inaccurate.

Please analyze the value as part of the issue and explain your finding if you consider this to be incorrect.

marnixcro, 2021-03-12:
Previous version had the following comment, but was deemed too confusing since the I2C speeds are altered by both the I2C setting and the clockspeed.

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

Closed 2021-03-12.

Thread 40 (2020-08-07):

[FLASH_SPI] Add support for HW CS

elsalahy, 2020-08-07:
**Summary:**
<!-- Summarize the feature in a few sentences: -->

Currently, we use SW CS as a normal GPIO to intiate the SPI transfers to the external flash.

**Why do we need this?**
<!-- Please explain the motivation, how it will be used, etc -->

To have faster SPI transfers and fully utilize the SOC features.

**What is already there? What do you see now?**
<!-- Please attach (or link to) screenshots and logs if applicable -->

SW GPIO control of the CS pin.

**What is missing? What do you want to see?**
<!-- Please add some examples or mock-ups if applicable -->

HW control of the SPI core.

**How do you propose to implement this?**
<!--
If unsure, add the discussion label and (temporarily) assign the expert
If you cannot assign people, please @mention the experts
-->

- Configure the SPI core to use a HW CS pin
- Adjust any driver (like the external flash) to use the HW version instead of the SW (just remove the manual SW GPIO control).

**Environment:**
<!-- Your environment: OS/Browser/Gateway/Device/...? Versions? IDs/EUIs? -->

Baremetal.

**Acceptance Criteria:**
<!--
Please explain the necessary conditions to be satisfied for this feature to be considered implemented.
These may include important test cases that need to pass, expected resource consumption improvements etc.
-->

- SPI functionality behaves the same as the SW one.
- Adapt the change if there is an improvement in the speed.

**What can you do yourself and what do you need help with?**

ALL

marnixcrouzen, 2021-03-02:
**Update on findings, should this issue be delayed**
HW CS works a little different than anticipated, but might still work.
This is the diagram for the first command of the basic app (getting the ID), note that the CS pin has to be released, it will otherwise send the ID continuously.
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

I've gathered some images of the CS pin and the SCL pin during this command (MOSI is always correct, no need to display).

SW of course works:
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

HW CS has two modes on the STM32, pulsed enabled or disabled mode.
Pulse disables seems to be just letting CS be low forever to gets this:
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
This gets the proper ID, but fails when doing anything else as the flash IC will from then on respond to anything with the ID number since the CS pin was never released.

Pulse enables doesn't get as far as receiving the ID. It sets CS pin high whenever SPI is free:
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
Since the CS pin is released every time the SPI interface seems to be free, the message gets interrupted and the flash IC thinks its nothing.

How to fix:

- **Pulse enabled**, make sure SPI is not freed in between, see if that's possible when sending multiple bytes. This would be the best solution as it would work similarly to the current SW NSS whilst being faster.
- **Pulse disabled**, find out when the CS pin is released. From this [link](https://stackoverflow.com/questions/35780290/how-to-use-hardware-nss-spi-on-stm32f4) the answer is turning off the whole SPI interface (doesn't really make HW SPI that nice tbh).
- **Dirty fix**, Do not receive the ID and work with pulse disabled mode, other commands (reading/writing) do not care if the CS pin is set high at the end

elsalahy, 2021-03-02:
@marnixcrouzen Thanks for the detailed/great analysis.

I think we should not proceed forward with this issue, and we should close it, as with the current external flash (MX25R1635F) and supported STM32 SPI modes, it is clear that this will not be a viable solution.

This can be re-opened in the future if we change the MCU or the external flash.

To make sure we maximize the gain from your investigation, please document the following in this issue.
1. How to enable pulse enabled (provide source code)
2. How to enable pulse disabled (provide source code)
3. SPI transmission example using HW CS (provide source code).

And afterwords please close the issue.

marnixcrouzen, 2021-03-02:
Diff file shows for enabling pulse, NSSPMode should be kept SPI_NSS_PULSE_DISABLE for disabled pulse. Setting the frequency of the pin high is not required, but seemed useful when trying to optimise speed.
```diff
diff --git a/Software/lib/GNSE_BSP/GNSE_bsp_serial.c b/Software/lib/GNSE_BSP/GNSE_bsp_serial.c
index 1a87a20..4911631 100644
--- a/Software/lib/GNSE_BSP/GNSE_bsp_serial.c
+++ b/Software/lib/GNSE_BSP/GNSE_bsp_serial.c
@@ -175,14 +175,14 @@ int32_t GNSE_BSP_Flash_SPI_Init(void)
   GNSE_BSP_flash_spi.Init.DataSize = SPI_DATASIZE_8BIT;
   GNSE_BSP_flash_spi.Init.CLKPolarity = SPI_POLARITY_LOW;
   GNSE_BSP_flash_spi.Init.CLKPhase = SPI_PHASE_1EDGE;
-  GNSE_BSP_flash_spi.Init.NSS = SPI_NSS_SOFT; //TODO: USE HW NSS, see https://github.com/TheThingsIndustries/generic-node-se/issues/40
+  GNSE_BSP_flash_spi.Init.NSS = SPI_NSS_HARD_OUTPUT;
   GNSE_BSP_flash_spi.Init.BaudRatePrescaler = FLASH_SPI_BAUDRATE;
   GNSE_BSP_flash_spi.Init.FirstBit = SPI_FIRSTBIT_MSB;
   GNSE_BSP_flash_spi.Init.TIMode = SPI_TIMODE_DISABLE;
   GNSE_BSP_flash_spi.Init.CRCCalculation = SPI_CRCCALCULATION_DISABLE;
   GNSE_BSP_flash_spi.Init.CRCPolynomial = 7;
   GNSE_BSP_flash_spi.Init.CRCLength = SPI_CRC_LENGTH_DATASIZE;
-  GNSE_BSP_flash_spi.Init.NSSPMode = SPI_NSS_PULSE_DISABLE;
+  GNSE_BSP_flash_spi.Init.NSSPMode = SPI_NSS_PULSE_ENABLE;
   if (HAL_SPI_Init(&GNSE_BSP_flash_spi) != HAL_OK)
   {
     return GNSE_BSP_ERROR_NO_INIT;
diff --git a/Software/lib/GNSE_BSP/GNSE_msp.c b/Software/lib/GNSE_BSP/GNSE_msp.c
index 81abcb7..a4b96e3 100644
--- a/Software/lib/GNSE_BSP/GNSE_msp.c
+++ b/Software/lib/GNSE_BSP/GNSE_msp.c
@@ -187,14 +187,13 @@ void HAL_SPI_MspInit(SPI_HandleTypeDef *spiHandle)
         FLASH_SPI_GPIO_CLK_ENABLE();

         /*Configure GPIO pin Output Level */
-        HAL_GPIO_WritePin(FLASH_SPI_GPIO_PORT, FLASH_SPI_CS_PIN, GPIO_PIN_RESET);

         gpio_init_structure.Pin = FLASH_SPI_CS_PIN;
-        gpio_init_structure.Mode = GPIO_MODE_OUTPUT_PP;
+        gpio_init_structure.Mode = GPIO_MODE_AF_PP;
         gpio_init_structure.Pull = GPIO_NOPULL;
-        gpio_init_structure.Speed = GPIO_SPEED_FREQ_LOW;
+        gpio_init_structure.Speed = GPIO_SPEED_FREQ_VERY_HIGH;
+        gpio_init_structure.Alternate = GPIO_AF5_SPI1;
         HAL_GPIO_Init(FLASH_SPI_GPIO_PORT, &gpio_init_structure);
-        HAL_GPIO_WritePin(FLASH_SPI_GPIO_PORT, FLASH_SPI_CS_PIN, GPIO_PIN_SET);

         gpio_init_structure.Pin = FLASH_SPI_MISO_PIN | FLASH_SPI_SCK_PIN;
         gpio_init_structure.Mode = GPIO_MODE_AF_PP;
diff --git a/Software/lib/MX25R1635/mxic_hc.c b/Software/lib/MX25R1635/mxic_hc.c
index 70fb103..a252565 100644
--- a/Software/lib/MX25R1635/mxic_hc.c
+++ b/Software/lib/MX25R1635/mxic_hc.c
@@ -53,15 +53,11 @@ int MxPolledTransfer(MxSpi *Spi, u8 *WrBuf, u8 *RdBuf, u32 ByteCount)
     HAL_StatusTypeDef status = HAL_OK;
     if (RdBuf == NULL)
     {
-        HAL_GPIO_WritePin(FLASH_SPI_GPIO_PORT, FLASH_SPI_CS_PIN, GPIO_PIN_RESET);
         status = HAL_SPI_Transmit(&GNSE_BSP_flash_spi, (uint8_t *)WrBuf, ByteCount, Flash_SPI_TIMOUT);
-        HAL_GPIO_WritePin(FLASH_SPI_GPIO_PORT, FLASH_SPI_CS_PIN, GPIO_PIN_SET);
     }
     else
     {
-        HAL_GPIO_WritePin(FLASH_SPI_GPIO_PORT, FLASH_SPI_CS_PIN, GPIO_PIN_RESET);
         status = HAL_SPI_TransmitReceive(&GNSE_BSP_flash_spi, (uint8_t *)WrBuf, (uint8_t *)RdBuf, ByteCount, Flash_SPI_TIMOUT);
-        HAL_GPIO_WritePin(FLASH_SPI_GPIO_PORT, FLASH_SPI_CS_PIN, GPIO_PIN_SET);
     }

     if (status != HAL_OK)

```

Closed 2021-03-02.

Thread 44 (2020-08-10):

[HW] Version 0.2 updates

azerimaker, 2020-08-10:
**Summary:**
<!-- Summarize the feature in a few sentences: -->

In this issue I'd like to discuss what type of changes we should implement on the next revision (0.2) of GN. I'll include some of the feedback from our inner-circle reviews.

**Cont. updated list of improvements:**

**_1. HW improvements to be implemented:_**

- [x] Industrial operating temperature range (−40 ° to 85 °C): verify for each component
- [x] Easy flashing options: over serial bootloader,  SWD, have separate pads for each
- [x] Layout changes for better EMC compliance and power decoupling
- [x] Removing I2C lines from the MIPI14 connector
- [x] Swapping UART lines on MIPI14 connector
- [x] add more expansion interfaces: QWIC port
- [x] BOM optimization, reducing number of Load Switches, cheaper component alternatives
- [x] Fix some of the footprints for PCBA

_**2. RF improvements:**_

- [x] Add RF shield
- [x] Better via stitching
- [ ] RF input reflection coefficient analysis of TX lines by ST. PCB-stackup info is required.
- [x] Use Capacitive coupling ANT.

_**3. Mechanical improvements:**_

- [x] 0.4mm larger screw holes
- [x] Shallower batter connector clips
- [x] Increase spacing between connector clips
- [x] DFM analysis before fabrication

**Why do we need this?**
<!-- Please explain the motivation, how it will be used, etc -->

Based on many discussions with the inner circle.

**What is already there? What do you see now?**
<!-- Please attach (or link to) screenshots and logs if applicable -->

We already have a fully functional prototype although not cost optimized.

**What is missing? What do you want to see?**
<!-- Please add some examples or mock-ups if applicable -->

Some of the improvements are listed above. Implementing many of them would crucial for the success of this design.

**How do you propose to implement this?**
<!--
If unsure, add the discussion label and (temporarily) assign the expert
If you cannot assign people, please @mention the experts
-->

With this revision the plan is to fabricate high-quality PCBs and get assembled around 50-100x boards

**Acceptance Criteria:**
<!--
Please explain the necessary conditions to be satisfied for this feature to be considered implemented.
These may include important test cases that need to pass, expected resource consumption improvements etc.
-->

- Better user experience (plug&play)
- Better RF performance
- Stable system
- Lower cost

**What can you do yourself and what do you need help with?**

Most of the listed steps, some of the RF analysis and modeling need to be done by the ANT supplier/partner.

azerimaker, 2021-02-18:
Closing this to reduce the clutter, since most of the above mentioned improvements are implemented.

Closed 2021-02-18.

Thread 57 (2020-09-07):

System Wide control APIs

elsalahy, 2020-09-07:
**Summary:**
<!-- Summarize the feature in a few sentences: -->

We need to have a system wide control APIs that allow us to
- Initialize the system clock
- Initialize the system debug interfaces
- Initialize relevant sensors
- Handle multiple error levels based on the severity of the error.

**Why do we need this?**
<!-- Please explain the motivation, how it will be used, etc -->

To avoid code replication and follow the DRY principle in the application development.

**What is already there? What do you see now?**
<!-- Please attach (or link to) screenshots and logs if applicable -->

BSP & HAL control of the device components.

**What is missing? What do you want to see?**
<!-- Please add some examples or mock-ups if applicable -->

High level APIs that initialize the system based on a set of configurations passed from application layer.

**How do you propose to implement this?**
<!--
If unsure, add the discussion label and (temporarily) assign the expert
If you cannot assign people, please @mention the experts
-->

Handle each component separately and define and implement the affiliate functions:

- System Initialization
- System Erros
- System Debugging

**Environment:**
<!-- Your environment: OS/Browser/Gateway/Device/...? Versions? IDs/EUIs? -->

Baremetal

**Acceptance Criteria:**
<!--
Please explain the necessary conditions to be satisfied for this feature to be considered implemented.
These may include important test cases that need to pass, expected resource consumption improvements etc.
-->
- All Applications compile and function as intended before the new system wide changes.

**What can you do yourself and what do you need help with?**
ALL

elsalahy, 2021-03-17:
Sensor on board components HAL is covered as part of #73

marnixcro, 2021-07-07:
For the current status of the APIs and new names:

- Clock Function would be something like GNSE_BSP_CLK_Init, with the content being the configuration present currently in all applications.
- Debug interface name would be GNSE_BSP_DBG_Init. Like with the clocks, all applications currently redefine DBG_Init without any changes between them.
- Sensors are already done in #73, as was mentioned previously
- Error levels were sort of updated with #159 with the verbosity being configurable with simple function calls. Low verbosity could still be added to this.

elsalahy, 2021-07-07:
Ok some notes:
- For the clock it should be `GNSE_HAL` and not `GNSE_BSP`
-`DBG_Init()` will be handled by the LPM since it relates to using the debugger in low power.

elsalahy, 2021-08-20:
This issue is implemented in #73, #171 and #207
For further improvements we should open new smaller issues.

Closed 2021-08-20.

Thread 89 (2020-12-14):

Potential ANT performance issue

azerimaker, 2020-12-14:
**Summary:**
<!-- Summarize the feature in a few sentences: -->

In their first layout review Fractus has mentioned to place the antenna on the back side of the mainboard.
As can be seen from the review, we followed all their design recommendations, but one. To simplify the manufacturing and bring more prominence for the component I've placed it on the front side of the board.  Now that the component is slightly closer to battery contacts, which might result in slightly degraded RF performance and Fractus is a bit concerned about this.
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

**Next step:**

Once we have the first prototypes, I'll do in-depth testing to compare the performance penalty.
If the performance is severely degraded, I'll place the antenna on the back side (as shown below).
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

azerimaker, 2021-05-05:
I did a crude antenna return loss (efficiency) and VSWR measurements with my NanoVNA.
Without any matching network tuning antenna works best for **938MHz** with VSWR value of **~1.73** inside the fully assembled enclosure. Without the enclosure frequency shifts to **~960MHz** with VSWR value of **~1.04**. The antenna clearly performs better without the enclosure, but once it goes through matching network retuning with the enclosure we can get good performance out of it.

**Test with the enclosure:**
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

**Test without the enclosure:**
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

elsalahy, 2021-06-29:
This issue is part of Q2,  do we have any progress on this?

azerimaker, 2021-07-01:
As suspected overlapping battery terminals on the ANT clearance area does slightly reduce the efficiency, but after we've gone through the matching network retuning on the actual device it became evident that the real device performs better than the simulated results. Please see #128 for more info.

Closed 2021-07-01.

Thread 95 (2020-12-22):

basic verification and validation of v1.1 HW and FW

elsalahy, 2020-12-22:
**Summary:**
<!-- Summarize the feature in a few sentences: -->
Umbrella issue for testing, verifying and validating the new v0.2 HW and relevant FW.
Tasks:
- [x] Improve basic apps to reflect and test the new HW changes
- [x] Ensure any HW/FW design change is reflected in the documentation
- [x] Flash and run all basic apps and verify functionality
- [x] Validate power consumption of each app
- [x] Ensure MCU RTC and timers are precise
- [ ] Test antenna performance and ensure usable performance (compare to v0.1)
- [ ] Add more relevant issues/tasks here

**Why do we need this?**
<!-- Please explain the motivation, how it will be used, etc -->

To ensure the new board HW and FW is usable.

**What is already there? What do you see now?**
<!-- Please attach (or link to) screenshots and logs if applicable -->

Working and tested FW on the v0.1 HW.

**What is missing? What do you want to see?**
<!-- Please add some examples or mock-ups if applicable -->

Basic testing of the HW/FW functionality.

**How do you propose to implement this?**
<!--
If unsure, add the discussion label and (temporarily) assign the expert
If you cannot assign people, please @mention the experts
-->

Umbrella issue, can open more issues with relevant details

**Environment:**
<!-- Your environment: OS/Browser/Gateway/Device/...? Versions? IDs/EUIs? -->

Bare-metal and FreeRTOS

**Acceptance Criteria:**
<!--
Please explain the necessary conditions to be satisfied for this feature to be considered implemented.
These may include important test cases that need to pass, expected resource consumption improvements etc.
-->
Report on the new HW performance.

**What can you do yourself and what do you need help with?**

All

elsalahy, 2021-02-01:
We received the 2nd iteration of the HW on 18th of Jan.
We validated the device functionality using basic apps and the results are below:
- `basic`  ✅  (some nodes failed to pass, need to investigate the production issue)
- `basic_lorawan` ✅  (The RSSI and the antenna performance need to be validated)

azerimaker, 2021-03-13:
Basic verification of **v1.1** HW is now complete.
Out of 99 beta boards (1x was incomplete from the PCBA) 84 passed the basic test, and only 80 of them have passed the LoRaWAN test at first pass. 4 of them gets stuck at LoRaWAN app.
This results in 81% of overall yield.
Rest of the 15 boards won't start at all (Buck-Boost goes into protection mode). I've investigated the issue and in most of them it comes down to the poor soldering of the buck-boost converter's WLCSP-20 package (BGA). Please see the related issue #36 for more details.

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

elsalahy, 2021-03-17:
Yeah indeed basic verification is done.
Relevant advanced issues  #128 #36

Closed 2021-03-17.

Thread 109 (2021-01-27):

Reduce enclosure size by using AAA and/or flat li-poly batt.

ehogeweg, 2021-01-27:
**Summary:**
The node is spectacular but seems a tad bulky. Changing the batteries would allow for a smaller enclosure. Additional... it would be nice (...) if the battery can be charged with a little solar panel on the cover.

**How do you propose to implement this?**
It seems easy enough to define a different bottom, maybe even include both bottoms in the package. Keeping two different models on stock seems overkill.
...

**Environment:**
<!-- Your environment: OS/Browser/Gateway/Device/...? Versions? IDs/EUIs? -->

...

**Acceptance Criteria:**
<!--
Please explain the necessary conditions to be satisfied for this feature to be considered implemented.
These may include important test cases that need to pass, expected resource consumption improvements etc.
-->
...

Unable to help with the enclose but more than happy to help implementing the solar charging part.

azerimaker, 2021-01-27:
Thanks for your comment, @ehogeweg . That's certainly doable. In fact, that was the reason why we went with JST-PH connector, so you can use flat LiPo batteries.
The reason why we went with 2xAA instead of 2xAAA was mainly due to the provided extra capacity for 2xAA ~9Wh which was almost 60%  more than the 2xAAA based solution.
Energy harvesting can be implemented on a small add-on board which sits between a rechargeable battery and the main PCB.

azerimaker, 2021-01-27:
@ehogeweg please see this discussion for more info: https://github.com/TheThingsIndustries/generic-node-se/issues/8#issuecomment-624648301

ehogeweg, 2021-01-27:
That is an excellent thread, thanks for sharing. Too bad it is close ;-)

Keep up the good work guys. The generic node appears to be an awesome product. Can’t wait to get my hands on it.

Didn’t hear about it until today so I have a bit of catching up to do.

Cheers,

Erwin

On Jan 27, 2021, at 12:05, Orkhan AmirAslan <notifications@github.com<mailto:notifications@github.com>> wrote:

@ehogeweg<https://github.com/ehogeweg> please see this discussion for more info: #8 (comment)<https://github.com/TheThingsIndustries/generic-node-se/issues/8#issuecomment-624648301>

—
You are receiving this because you were mentioned.
Reply to this email directly, view it on GitHub<https://github.com/TheThingsIndustries/generic-node-se/issues/109#issuecomment-768429876>, or unsubscribe<https://github.com/notifications/unsubscribe-auth/ADLFF5GUYSHXRWAS6X4A7CTS4BBT7ANCNFSM4WVRRFKA>.

Erwin Hogeweg
CTO
3690 Airport Road
Boca Raton, FL 33431
P. +1 (954) 556-6565
M. +1 (561) 306-7395
F. +1 (561) 948-2730
[Seecago]<http://www.seecago.com>

ehogeweg, 2021-01-27:
Thanks Orkhan,

BTW… I seems like most of your team is in EUR. We are located in the US (South Florida) so if you need some beta testers here, we are more than happy to help.

Cheers,

Erwin

On Jan 27, 2021, at 12:03, Orkhan AmirAslan <notifications@github.com<mailto:notifications@github.com>> wrote:

Thanks for your comment, @ehogeweg<https://github.com/ehogeweg> . That's certainly doable. In fact, that was the reason why we went with JST-PH connector, so you can use flat LiPo batteries.
The reason why we went with 2xAA instead of 2xAAA was mainly due to the provided extra capacity for 2xAA ~9Wh which was almost 60% more than the 2xAAA based solution.
Energy harvesting can be implemented on a small add-on board which sits between a rechargeable battery and the main PCB.

—
You are receiving this because you were mentioned.
Reply to this email directly, view it on GitHub<https://github.com/TheThingsIndustries/generic-node-se/issues/109#issuecomment-768428759>, or unsubscribe<https://github.com/notifications/unsubscribe-auth/ADLFF5ARFB44HXJAS3DU2W3S4BBNVANCNFSM4WVRRFKA>.

Erwin Hogeweg
CTO
3690 Airport Road
Boca Raton, FL 33431
P. +1 (954) 556-6565
M. +1 (561) 306-7395
F. +1 (561) 948-2730
[Seecago]<http://www.seecago.com>

azerimaker, 2021-01-27:
Thanks Erwin (@ehogeweg ).

Thanks, in that and other threads (mostly closed) you can have a general overview as we progressed in our design decisions.

We'd love to have beta testers in USA. We have designed the device in such a way what it would support dual band **(868/915 MHz, +14 dBm/ +22dBm )** while sticking to one BOM and antenna matching network. This of course results in overall reduced efficiency, but that's a compromise for now. Later we might have EU and US only versions.

Please join our [early access program](https://www.genericnode.com/) and we will send you more details.

Closed 2021-02-10.

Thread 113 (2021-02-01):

lorawan freefall app

elsalahy, 2021-02-01:
**Summary:**
<!-- Summarize the feature in a few sentences: -->

We need an application that configures the accelerometer interrupt pin to report free-fall over LoRaWAN

**Why do we need this?**
<!-- Please explain the motivation, how it will be used, etc -->

To have a sample application demonstrating the GNSE capability of detecting free-fall

**What is already there? What do you see now?**
<!-- Please attach (or link to) screenshots and logs if applicable -->

basic_lorawan application.

**What is missing? What do you want to see?**
<!-- Please add some examples or mock-ups if applicable -->

A freefall demonstration app.

**How do you propose to implement this?**
<!--
If unsure, add the discussion label and (temporarily) assign the expert
If you cannot assign people, please @mention the experts
-->
- The applications connects OTAA over LoRaWAN
- The application sends an uplink when the device detects a freefall.
- If the device can't send a message it accumulates the freefall events and send them in the next transmission.
- Any parameters that can be configured, should be in app_conf

**Environment:**
<!-- Your environment: OS/Browser/Gateway/Device/...? Versions? IDs/EUIs? -->

Baremetal

**Acceptance Criteria:**
<!--
Please explain the necessary conditions to be satisfied for this feature to be considered implemented.
These may include important test cases that need to pass, expected resource consumption improvements etc.
-->
- App compiles with no warnings
- App functions as expected

**What can you do yourself and what do you need help with?**

Marnix will handle this application and ask for direction when needed.

elsalahy, 2021-02-02:
Here is a similar [application](https://lora-developers.semtech.com/resources/lorawan-academy/) we developed using another platform.

elsalahy, 2021-02-02:
@marnixcrouzen please feel free to discuss the requirements before jumping into implementation.

marnixcrouzen, 2021-02-11:
I have a couple of questions about this feature

1. Wat message should appear in the payload?
2. Has there already been an implementation like the third item on the proposal list? I first thought that the button events from basic_lorawan would have this feature but it only notifies the user and never sends the message. It should be doable by setting a timer on failed attempts, but maybe I'm missing a more elegant build-in solution.

elsalahy, 2021-02-12:
@marnixcrouzen

1. You have flexibility with the message structure but it keep in mind it should be as configurable as possible.
2.  Yeah you can use a configurable transmission timer using the sequencer.

Closed 2021-03-04.

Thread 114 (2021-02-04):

Boot mode pins capacitance too high

marnixcro, 2021-02-04:
**Summary:**
<!-- Summarize the problem in a few sentences: -->
The boot pin connection seems to have a capacitance that's too high. My node jumped into boot mode without connecting the boot pins together. The device was power cycled and reset multiple times in between. Discharging power supply by shorting it was also not successful. The issue was fixed after turning the device off, shorting the pins temporarily, and turning it on again.

**Steps to Reproduce:**
<!-- How can we reproduce the problem? -->

1. Shorting the boot pins with a header
2. Turning on the device for some time
3. Disconnecting the header
4. Resetting
4. Try to connect to the device via UART (if connected, the boot mode is running)

<!-- Please attach (or link to) configuration files if applicable -->

**What do you see now?**
<!-- Please attach (or link to) screenshots and logs if applicable -->

...

**What do you want to see instead?**
<!-- Please add some examples or mock-ups if applicable -->

...

**How do you propose to implement this?**
<!--
If unsure, add the discussion label and (temporarily) assign the expert
If you cannot assign people, please @mention the experts
-->

...

**Environment:**
<!-- Your environment: OS/Browser/Gateway/Device/...? Versions? IDs/EUIs? -->

Bare metal

**What can you do yourself and what do you need help with?**

...

elsalahy, 2021-02-05:
This is a good first issue, from the title to the Summary, will done @marnixcrouzen 👏 !

azerimaker, 2021-02-11:
@marnixcrouzen thank you for the issue. Could you please verify if there is a short on BOOT0 pins under the PCB?
I typically measure >50KOhm resistance between the BOOOT0 and VDDRF, and couldn't reproduce it.
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
OT0 pins.

marnixcrouzen, 2021-02-11:
@azerimaker the node is not shorted on the boot0 pins. When I resolved the issue I was actually trying to find short there but that didn't seem to be the case then. After testing it and knowing there was no short, it unexpectedly worked after turning it on. I thought that shorting it during the process of testing with my probes might have discharged it.

I tried reproducing it myself today. I wasn't able to get it into boot mode without shorting the pins. It is either harder to reproduce than I thought or something else caused the issue.

An alternative theory that I have is that the short was caused by some smudge between the pads. Maybe trying to touch the pads with my probes made me accidentally wipe the smudge off, clearing the short before determining that there was any. The pads are extremely close together, but I wouldn't know how it suddenly could be shorted after a full day of it working and even working the morning of the incident.

azerimaker, 2021-03-13:
Since this issue is not present in other nodes I'm closing it for now. We can reopen it we observe anything again.

Closed 2021-03-13.

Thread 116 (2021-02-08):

[HW] Sudden high power consumption (~0.500 A @3V)

marnixcrouzen, 2021-02-08:
**Summary:**
<!-- Summarize the problem in a few sentences: -->

A generic node suddenly increased in power consumption to ~0.500A @3V. The device is fully operational, the basic app tests all pass. Boot mode shows a similar power consumption, as well as erasing the whole chip. The temperature sensor is much higher than usual (40 'C), a component is probably heating up from consuming all this power.

**Steps to Reproduce:**
<!-- How can we reproduce the problem? -->

1. ...
2. ...
3. ...

<!-- Please attach (or link to) configuration files if applicable -->

**What do you see now?**
<!-- Please attach (or link to) screenshots and logs if applicable -->

Here the output from the basic app:
-------------- Starting GNSE basic app --------------

 Testing battery monitoring functionality

 MCU internal reference voltage 2849 mv

 Battery voltage 2679 mv

 Testing LED functionality

 Toggling LED lights

 Testing secure element functionality

 1) Enabling LOAD_SWITCH_SENSORS

 2) Attempting to read secure element serial number

 SE Serial Number:          01 23 bf de 54 c1 b2 75 27

 SE Device EUI:             00 04 a3 10 00 1a ae b7

 SE Application/Join EUI:   70 b3 d5 7e d0 00 00 00

 Testing on board sensors functionality

 Attempting to read sensors data

 Measured Temperature: 41'C & Relative Humidity: 22

 Measured Temperature: 41'C & Relative Humidity: 22

 Measured Temperature: 41'C & Relative Humidity: 22

 Measured Temperature: 41'C & Relative Humidity: 22

 Measured Temperature: 41'C & Relative Humidity: 22

 Accelerometer acceleration [mg]: X: 150.00      Y: -90.00       Z: -1010.00

 Accelerometer Temperature sensor [degC]:  36.75

 Accelerometer acceleration [mg]: X: 75.00       Y: -50.00       Z: -504.00

 Accelerometer Temperature sensor [degC]:  38.75

 Accelerometer acceleration [mg]: X: 150.00      Y: -90.00       Z: -1012.00

 Accelerometer Temperature sensor [degC]:  39.00

 Accelerometer acceleration [mg]: X: 154.00      Y: -88.00       Z: -1014.00

 Accelerometer Temperature sensor [degC]:  39.00

 Accelerometer acceleration [mg]: X: 153.00      Y: -89.00       Z: -1012.00

 Accelerometer Temperature sensor [degC]:  39.50

 Testing on board external flash functionality

 1) Enabling LOAD_SWITCH_FLASH

 2) Attempting to read & write to external flash

        Start initializing the device and controller
        Start matching the device ID
                 SPI, ID: C22815
                Change Mode To [Standard SPI Read]
                Change Mode To [Standard SPI Write]
  ------MxSimpleTest Start!------
  ID: C22815
  Sr: 00
        ERASE START
        ERASE DONE
                 **Start Dump data=> address        0
                            Length=> 20
                 READ address=> 00000000
                         data=> FF
                     expected=> FF
                 READ address=> 00000001
                         data=> FF
                     expected=> FF
                 READ address=> 00000002
                         data=> FF
                     expected=> FF
                 READ address=> 00000003
                         data=> FF
                     expected=> FF
                 READ address=> 00000004
                         data=> FF
                     expected=> FF
                 READ address=> 00000005
                         data=> FF
                     expected=> FF
                 READ address=> 00000006
                         data=> FF
                     expected=> FF
                 READ address=> 00000007
                         data=> FF
                     expected=> FF
                 READ address=> 00000008
                         data=> FF
                     expected=> FF
                 READ address=> 00000009
                         data=> FF
                     expected=> FF
                 READ address=> 0000000a
                         data=> FF
                     expected=> FF
                 READ address=> 0000000b
                         data=> FF
                     expected=> FF
                 READ address=> 0000000c
                         data=> FF
                     expected=> FF
                 READ address=> 0000000d
                         data=> FF
                     expected=> FF
                 READ address=> 0000000e
                         data=> FF
                     expected=> FF
                 READ address=> 0000000f
                         data=> FF
                     expected=> FF
                 READ address=> 00000010
                         data=> FF
                     expected=> FF
                 READ address=> 00000011
                         data=> FF
                     expected=> FF
                 READ address=> 00000012
                         data=> FF
                     expected=> FF
                 READ address=> 00000013
                         data=> FF
                     expected=> FF
                 READ address=> 00000014
                         data=> FF
                     expected=> FF
                 READ address=> 00000015
                         data=> FF
                     expected=> FF
                 READ address=> 00000016
                         data=> FF
                     expected=> FF
                 READ address=> 00000017
                         data=> FF
                     expected=> FF
                 READ address=> 00000018
                         data=> FF
                     expected=> FF
                 READ address=> 00000019
                         data=> FF
                     expected=> FF
                 READ address=> 0000001a
                         data=> FF
                     expected=> FF
                 READ address=> 0000001b
                         data=> FF
                     expected=> FF
                 READ address=> 0000001c
                         data=> FF
                     expected=> FF
                 READ address=> 0000001d
                         data=> FF
                     expected=> FF
                 READ address=> 0000001e
                         data=> FF
                     expected=> FF
                 READ address=> 0000001f
                         data=> FF
                     expected=> FF
        ERASE PASS
        PROGRAM DONE
                 **Start Dump data=> address        0
                            Length=> 20
                 READ address=> 00000000
                         data=> 00
                     expected=> 00
                 READ address=> 00000001
                         data=> 01
                     expected=> 01
                 READ address=> 00000002
                         data=> 02
                     expected=> 02
                 READ address=> 00000003
                         data=> 03
                     expected=> 03
                 READ address=> 00000004
                         data=> 04
                     expected=> 04
                 READ address=> 00000005
                         data=> 05
                     expected=> 05
                 READ address=> 00000006
                         data=> 06
                     expected=> 06
                 READ address=> 00000007
                         data=> 07
                     expected=> 07
                 READ address=> 00000008
                         data=> 08
                     expected=> 08
                 READ address=> 00000009
                         data=> 09
                     expected=> 09
                 READ address=> 0000000A
                         data=> 0A
                     expected=> 0A
                 READ address=> 0000000B
                         data=> 0B
                     expected=> 0B
                 READ address=> 0000000C
                         data=> 0C
                     expected=> 0C
                 READ address=> 0000000D
                         data=> 0D
                     expected=> 0D
                 READ address=> 0000000E
                         data=> 0E
                     expected=> 0E
                 READ address=> 0000000F
                         data=> 0F
                     expected=> 0F
                 READ address=> 00000010
                         data=> 10
                     expected=> 10
                 READ address=> 00000011
                         data=> 11
                     expected=> 11
                 READ address=> 00000012
                         data=> 12
                     expected=> 12
                 READ address=> 00000013
                         data=> 13
                     expected=> 13
                 READ address=> 00000014
                         data=> 14
                     expected=> 14
                 READ address=> 00000015
                         data=> 15
                     expected=> 15
                 READ address=> 00000016
                         data=> 16
                     expected=> 16
                 READ address=> 00000017
                         data=> 17
                     expected=> 17
                 READ address=> 00000018
                         data=> 18
                     expected=> 18
                 READ address=> 00000019
                 READ address=> 0000001B
                         data=> 1B
                     expected=> 1B
                 READ address=> 0000001C
                         data=> 1C
                     expected=> 1C
                 READ address=> 0000001D
                         data=> 1D
                     expected=> 1D
                 READ address=> 0000001E
                         data=> 1E
                     expected=> 1E
                 READ address=> 0000001F
                         data=> 1F
                     expected=> 1F
        MxSelfTest End!

 Simple external SPI flash (MX25R1635F) test passed!

 Testing Buzzer functionality

 Playing Buzzer tones

 -------------- Finished GNSE basic app --------------

**What do you want to see instead?**
<!-- Please add some examples or mock-ups if applicable -->

...

**How do you propose to implement this?**
<!--
If unsure, add the discussion label and (temporarily) assign the expert
If you cannot assign people, please @mention the experts
-->

...

**Environment:**
<!-- Your environment: OS/Browser/Gateway/Device/...? Versions? IDs/EUIs? -->

Bare metal

**What can you do yourself and what do you need help with?**

...

elsalahy, 2021-03-17:
Node left in the office for @azerimaker to inspect the behavior, no other nodes had similar issues after the basic testing done in #95, this can be a minor issue related to #145

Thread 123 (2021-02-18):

Voltage supervisor behavior at low Vin

azerimaker, 2021-02-18:
**Summary:**
<!-- Summarize the feature in a few sentences: -->

After testing with different battery types and the bench supply the voltage supervisor IC sometimes behaves erratically, resulting in disabling the buck-boost converter and going into oscillation mode. This maybe due to the location of its sense (Vin) line, which is right after the decoupling caps.

**Current problem:**
<!-- Please explain the motivation, how it will be used, etc -->

It sometimes causes unwanted latching and oscillations around 2.4V input levels.

**How do you propose to implement this?**
<!--
If unsure, add the discussion label and (temporarily) assign the expert
If you cannot assign people, please @mention the experts
-->

First method I tried was to remove the sense line and tap it directly from the output pin of the fuse. This improved the stability little bit, but the result still was not satisfactory. In the next revision we might consider replacing it with the 1.67V variant ([TPS3839G18](https://www.ti.com/lit/ds/symlink/tps3839.pdf?ts=1613571711240&ref_url=https%253A%252F%252Fwww.google.com%252F)).

**Proposition**
Considering the added cost, introduced instability in certain Vin ranges of a voltage supervisor IC we might offer this functionality as optional with a jumper resistor added across it.
Moreover the main[ buck-boost converter ](https://www.n-redc.co.jp/en/pdf/datasheet/rp605-ea.pdf)already has a built-in Undervoltage Lockout (UVLO) Circuit which disables the device at around 1.5V input.

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

azerimaker, 2021-07-05:
In the next revision (v1.1b) we have replaced the voltage supervisor with the 1.67V variant (TPS3839G18). I'll reopen this issue if this behavior persists.

Closed 2021-07-05.

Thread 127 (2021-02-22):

Incorrect PCB Pin description

elsalahy, 2021-02-22:
**Summary:**
<!-- Summarize the problem in a few sentences: -->

The VCC pin on the front is wrongly described on the back as GND
and The GND pin on the front is wrongly described in the back as VCC

**Steps to Reproduce:**
<!-- How can we reproduce the problem? -->
Check any PCB front and back.
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

<!-- Please attach (or link to) configuration files if applicable -->

**What do you see now?**
<!-- Please attach (or link to) screenshots and logs if applicable -->

Incorrect pin description.

**What do you want to see instead?**
<!-- Please add some examples or mock-ups if applicable -->

Correct pin description.

**How do you propose to implement this?**
<!--
If unsure, add the discussion label and (temporarily) assign the expert
If you cannot assign people, please @mention the experts
-->

Fix in next production phase.

**Environment:**
<!-- Your environment: OS/Browser/Gateway/Device/...? Versions? IDs/EUIs? -->

Hardware

**What can you do yourself and what do you need help with?**

@azerimaker can easily fix this.

azerimaker, 2021-02-24:
Good catch, @elsalahy. Noted down and will fix it in the final rev.

azerimaker, 2021-03-13:
This has to be addressed in documentation. I'll look into that.
Closing the issue for now.

elsalahy, 2021-09-24:
I see from the new HW design that this issue is solved.

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

lnlp, 2021-11-10:
@elsalahy

> I see from the new HW design that this issue is solved.

On above pictures with new HW design the silkscreen on PCB top side still lists "v1.1".

New hardware designs should have new versions of course but above picture does not confirm that.

It appears that either the new PCB has a bug in the silk screen or above picture is not the new HW design.
Which of these assumptions is correct?

elsalahy, 2021-11-24:
@lnlp I think @azerimaker increased the version to v1.1 b?

lnlp, 2021-11-24:
Maybe, but that is not what the version on the PCB silkscreen says.

azerimaker, 2021-12-13:
Hi @lnlp.
Indeed the PCB silkscreen has not been updated to indicate b version, as we did not see a reason to do so, because there was basically no hardware or layout changes. It was simply a logo and silkscreen update.

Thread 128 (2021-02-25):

Improve antenna performance

elsalahy, 2021-02-25:
**Summary:**
<!-- Summarize the problem in a few sentences: -->

The node RSSI is in the range of -80 to -90

**Steps to Reproduce:**
<!-- How can we reproduce the problem? -->

1. Flash the node with `basic_lorawan` app
2. Record gateway, application logs

<!-- Please attach (or link to) configuration files if applicable -->

**What do you see now?**
<!-- Please attach (or link to) screenshots and logs if applicable -->

Bad RSSI

Attached traced of SF12 and SF08.
The node is used without enclosure

[RSSI_SF08.txt](https://github.com/TheThingsIndustries/generic-node-se/files/6044682/RSSI_SF08.txt)
[RSSI_SF12.txt](https://github.com/TheThingsIndustries/generic-node-se/files/6044683/RSSI_SF12.txt)

**What do you want to see instead?**
<!-- Please add some examples or mock-ups if applicable -->

Good RSSI in the range of -40 to -60

**How do you propose to implement this?**
<!--
If unsure, add the discussion label and (temporarily) assign the expert
If you cannot assign people, please @mention the experts
-->

Fix Antenna placement and tune accordingly.

**Environment:**
<!-- Your environment: OS/Browser/Gateway/Device/...? Versions? IDs/EUIs? -->

V1.1 PCB (second iteration, 100 patch)

**What can you do yourself and what do you need help with?**

I can provide assistance with Firmware configurations and testing.
@azerimaker needs to analyze other nodes and confirm if the issue is present and decide on a plan to fix this.

elsalahy, 2021-02-26:
@marnixcrouzen can you please report the RSSI values of your node?

marnixcrouzen, 2021-02-26:
> @marnixcrouzen can you please report the RSSI values of your node?

Did two readings, no casing, indoors
Reading 1:
  "time": "2021-02-26T12:32:45.181342063Z",
  "data_rate": "SF12BW125",
  "gateway 1":
      "rssi": -118,
  "gateway 2":
      "rssi": -109,
      "snr": 4.2,
Reading 2:
  "time": "2021-02-26T12:34:22.413363371Z",
  "data_rate": "SF10BW125",
  "gateway 1":
      "rssi": -114,
      "snr": -0.8,
   "gateway 2":
      "rssi": -113,
      "snr": -0.2,

elsalahy, 2021-02-26:
@marnixcrouzen thanks for confirming the issue.

elsalahy, 2021-04-06:
@azerimaker please comment and update this issue, there seems to be a concern from the community as well observed in #163

We need to update this in order to respond to community questions.

elsalahy, 2021-06-29:
@azerimaker can you please update this issue with latest performance gains communicated by Ignion?

azerimaker, 2021-07-01:
The design went through "Antenna Matching Network Tuning" process and we're happy to announce that it's efficiency have been improved quite significantly. Antenna has been tuned for various use cases and frequency ranges. Respective efficiency gains are shown below.
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

azerimaker, 2021-07-01:
Closing this issue for now, but will repoen it once we have the second batch of nodes.

Closed 2021-07-01.

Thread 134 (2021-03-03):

Device Certification

azerimaker, 2021-03-03:
**Summary:**
<!-- Summarize the feature in a few sentences: -->

Umbrella issue for device certification related issues and discussions.

**Why do we need this?**
<!-- Please explain the motivation, how it will be used, etc -->

Certification is on the critical path before the mass-market release of our product.

**What is already there? What do you see now?**
<!-- Please attach (or link to) screenshots and logs if applicable -->

Currently we've started shipping the first [beta] units to our stealth-community members as a sample units w/o certification, but in upcoming months.

**What is missing? What do you want to see?**
<!-- Please add some examples or mock-ups if applicable -->

FCC, CE and LoRaWAN certifications. We already have an RF shield in place and we followed many of the design guidelines from the chip manufacturers, so passing the certification shouldn't be too much trouble.

**How do you propose to implement this?**
<!--
If unsure, add the discussion label and (temporarily) assign the expert
If you cannot assign people, please @mention the experts
-->

1. Firstly, we need to decide whether we want to proceed to the certification with the current layout (v1.1) or wait for the next rev (v1.2).
2. In any case we can to go through pre-certification to **verify** the current design (v1.1).
3. Once we have some experience about the performance of the v1.1 and after collecting some feedback from the beta testers we should implement the final layout improvements and go through the certification. Depending on our decision on the list item **1** we can either inherit the certification from the (v1.1) to (v1.2) and do an iterative certification based on similarity or just go directly with (v1.2) as a first-time certification.
4. We have to decide which RF consulting company to work with.

**Environment:**
<!-- Your environment: OS/Browser/Gateway/Device/...? Versions? IDs/EUIs? -->

Typically an anechoic chamber is used to carry out the certification so if we can find a contract manufacturer with that capability we can save some cost there.

**Acceptance Criteria:**
<!--
Please explain the necessary conditions to be satisfied for this feature to be considered implemented.
These may include important test cases that need to pass, expected resource consumption improvements etc.
-->
Since the current version it's a multi-band device, we have to make sure it complies with all the regional regulations. Plus CE certification will be updated in summer, so we have to account for that too.

**What can you do yourself and what do you need help with?**

I'll do basic EMI tests with my limited HW setup (scope), especially to verify the DC-DC converter's behavior.

johanstokking, 2021-03-03:
I think it's good to go with LoRaWAN pre-certification with the current revision already. Is the LCTT useful for this? See https://lora-alliance.org/lorawan-certification/

azerimaker, 2021-03-09:
@johanstokking it's a good idea. We'll start with CE (RED) certification route and alongside I will look into the LoRaWAN pre-certification. LCTT will definitely come in handy.

elsalahy, 2021-03-16:
# CE certification Todo:
1. #150
2. #151
and doing V1.2 updates if the pre-certification run requires major HW changes, see V1.2 hardware label

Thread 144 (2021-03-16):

GORE® Waterproof seal testing

azerimaker, 2021-03-16:
**Summary:**
<!-- Summarize the feature in a few sentences: -->

As part of the #36 testing I'll carry out testing different waterproof seals.
Current version (v1.1) of the nodes have openings (⌀ _2mm_) on the front panel to allow pressure compensation and reduce the thermal delay for each measurement. Temperature & Humidity sensor (**SHTC3**) sits right under the opening.
Normally this opening compromise the IP65 rating of the enclosure, however, we've decided to use an air-permeable mesh stickers from GORE® and they were kind enough to supply two circular variants. Part numbers are as follows:

- VE7 (VE70510 - 290 ml/min/cm² - black)
- VE9 (VE90510- 1150 ml/min/cm² - white)

**Why do we need this?**
<!-- Please explain the motivation, how it will be used, etc -->

In order not to compromise the IP rating of the enclosure.

**What is already there? What do you see now?**
<!-- Please attach (or link to) screenshots and logs if applicable -->

BOPLA offers rubber seals for pressure compensation.

**What is missing? What do you want to see?**
<!-- Please add some examples or mock-ups if applicable -->

However, they're not air-permeable and therefore not suitable for temperature & humidity readings.

**How do you propose to implement this?**
<!--
If unsure, add the discussion label and (temporarily) assign the expert
If you cannot assign people, please @mention the experts
-->

I've prepared 2 nodes, one without a seal, other with VE7/VE9 seals. I'll carry out several tests at an ambient temperature and inside a fridge, to observe the delay between nodes.

**Environment:**
<!-- Your environment: OS/Browser/Gateway/Device/...? Versions? IDs/EUIs? -->

`basic_lorawan_th `app and TTNV3 with Datacake integration.

**Acceptance Criteria:**
<!--
Please explain the necessary conditions to be satisfied for this feature to be considered implemented.
These may include important test cases that need to pass, expected resource consumption improvements etc.
-->

Low delay  and low (will be quantified later) offset between inside and outside of the enclosure, with respect to a reference thermometer.

**What can you do yourself and what do you need help with?**

All

azerimaker, 2021-03-16:
First test is conducted with two nodes (_Serial no. 79 (no seal) & 80 (VE7)_).
**Step 1**: Programmed the nodes and placed them side by side for 30 minutes to allow their temperature to balance.

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

**Step 2**: After running them at an ambient temperature the sensor readings were in their acceptable error margin (typ. ±0.2 C, ±2.0%).

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

azerimaker, 2021-03-16:
**Step 3:**  At T+15 minutes, placed the nodes inside the a fridge.

After T+ 30 minutes the readings are pretty close. There's about ~3 minutes delay between each node's temperature difference.
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

azerimaker, 2021-03-16:
After T+55 minutes. Both temperature and humidity readings are relatively close.

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

Reference thermometer shows ~1 °C difference, this is most probably due to the internal heating of the PCB inside the enclosure.
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

azerimaker, 2021-03-17:
**Small correction:** There was a bit of confusion between the membranes. Actually, **VE7** is the **black** one with lover airflow value (290 ml/min/cm²), **VE9** is the **white** one with much larger air-flow of value (1150 ml/min/cm²). Will update the above labels accordingly.

azerimaker, 2021-03-17:
Starting the second round of test with the same nodes.
This time the node no. 80 has VE7 (black) membrane seal, which has lower airflow value.

T+15: Sensor readings are bang-on.
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

Temperature readings can be confirmed with the reference thermometer.
Its humidity values are way off and not reliable, so only using T values.

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

azerimaker, 2021-03-17:
At T+45 minutes we can observe that the sealed sensor follows the unsealed one pretty well. Observed (but not precise) delay between the nodes was around ~3 mins with unsealed one leading ahead.

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

T+55 minutes: blue trace (sealed node) clearly shows the approx. delay.

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

azerimaker, 2021-03-17:
**Verdict:** After extensive tests we can confirm that both seals are working well and depending on the use case and region we can chose either one of them.
For rather harsh environments with a lot of rain, VE7 would be a better option.
For milder climates and faster reaction times VE9 could be preferred.

(more findings will follow)

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

Closed 2021-03-24.

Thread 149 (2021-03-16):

Create Enclosure visuals (front/back labels)

elsalahy, 2021-03-16:
**Summary:**
<!-- Summarize the feature in a few sentences: -->

Generic Node (SE) needs a professional front and back labels. On the front side we have a 2mm opening for the RGB LED and 8mm opening for the user button. Those will be covered with a outdoor resistant embossed sticker.
On the back side we can add some certification, serial number and QR claiming information.

**Why do we need this?**
We need more polished version of the front and back labels.

**What is already there? What do you see now?**
Created a rough version of the front panel (10x scaled) for the early prototypes, but we need more professional version.
[GNSEv1.1_front_panel_scale_10x_label.pdf](https://github.com/TheThingsIndustries/generic-node-se/files/6207186/GNSEv1.1_front_panel_scale_10x_label.pdf)

**What is missing? What do you want to see?**
I've added the dimensions below, having a unique front panel design and more generic back panel would be really beneficial.

wienke, 2021-03-19:
@pierrephz for the Generic Node we need a design for the top and bottom of the device:

* Top - clean visual and there is a button position somewhat at the center.
* Bottom - this should have our company info, CE mark, place for a QR code. And an instruction where people can scan it. Use tti.fyi/qr for now.

azerimaker, 2021-03-25:
@pierrephz I've added dimensions for the front/back panel visuals. Please use this as a reference.

[GNSEv1.1_label_dimensions.pdf](https://github.com/TheThingsIndustries/generic-node-se/files/6207153/GNSEv1.1_label_dimensions.pdf)

pierrephz, 2021-03-30:
@azerimaker please can you send me the final content/info, CE mark, QR code, etc. when you have it?

azerimaker, 2021-04-12:
@pierrephz hopefully next month we'll have a right to use the CE marking, in the meantime you can already start the design using this resources:
https://ec.europa.eu/growth/single-market/ce-marking_en

Please note that the CE marking must be **no smaller than** **5mm.**

azerimaker, 2021-07-05:
We've picked [this ](https://drive.google.com/file/d/1XM6PYIHjcL4YFFjKD1V_C2ZlUPKB8d2l/view?usp=sharing)design and it will be screen printed with UV resistant color and glue.
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

Closed 2021-07-05.

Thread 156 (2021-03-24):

Freefall Downlink LoRaWAN example

marnixcro, 2021-03-24:
**Summary:**
<!-- Summarize the feature in a few sentences: -->

There should be a application utilising downlinks as a feature. The freefall app is a good example for this, as it has a use case for finding the dropped GNSE with small beeps.

**Why do we need this?**
<!-- Please explain the motivation, how it will be used, etc -->

No such app exist yet, but user might still have need of this in their applications (using as remote warnings after data was processed on the server). Providing an example that can already separate the messages based on port and the content could help these users to quickly start their own implementations.

**What is already there? What do you see now?**
<!-- Please attach (or link to) screenshots and logs if applicable -->

No apps with implemented downlinks.

**What is missing? What do you want to see?**
<!-- Please add some examples or mock-ups if applicable -->

Freefall app with downlink.

**How do you propose to implement this?**
<!--
If unsure, add the discussion label and (temporarily) assign the expert
If you cannot assign people, please @mention the experts
-->

Add a basic downlink handler in freefall app for user defined actions.

**Environment:**
<!-- Your environment: OS/Browser/Gateway/Device/...? Versions? IDs/EUIs? -->

Baremetal

**Acceptance Criteria:**
<!--
Please explain the necessary conditions to be satisfied for this feature to be considered implemented.
These may include important test cases that need to pass, expected resource consumption improvements etc.
-->
Downlinks can be utilised in an application, no errors/warnings.

**What can you do yourself and what do you need help with?**

All

elsalahy, 2021-03-24:
@marnixcro
basic LoRaWAN already provides sufficient downlink functionality by switching to call B and C, so please avoid changing this app.

Your suggested feature can be done as part of the example application like the freefall app, for example activating the buzzer and LED via a downlink to identify the object that has free-fallen

Closed 2021-04-20.

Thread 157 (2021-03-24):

Option to bypass buck/boost stage

hallard, 2021-03-24:
**Summary:**
It could be interesting to have the ability to totally bypass the buck/boost stage.

**Why do we need this?**
To be able to power the node with classic Li Socl2 battery and avoid any related quiescent current

**What is already there? What do you see now?**
I don't see any option to bypass Buck/boost stage

**What is missing? What do you want to see?**
An option to bypass Buck/boost stage

**How do you propose to implement this?**
Build this feature with solder pad/jumper switch or switch

**Acceptance Criteria:**
If implemented with jumper pad (disabled by default), should not have any price incidence

elsalahy, 2021-03-25:
@azerimaker care to provide some input here and is this something we should consider for v1.2 hw version?

azerimaker, 2021-03-25:
@hallard thank you for your suggestion.
You're right, unfortunately there's no easy way to bypass the buck-boost converter in this version.
We're planning to remove the voltage supervisor IC and solely rely on the internal UVLO circuitry of the RP605x, therefore in the next rev, we will add a NC-NO jumper pad to be able to disable the IC ([~10nA standby current](https://www.n-redc.co.jp/en/pdf/datasheet/rp605-ea.pdf)) and supply the system directly from the VCC pin, or just add another jumper accross the buck-boost and supply it from the +BATT pin.

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

hallard, 2021-03-25:
Nice shot the CE1 with solder pad of the buck/bust, great idea and 10nA does not hurt me.
Take care powering from VCC may have current draw going to VOUT1 of the buck boost, depending on technology I already had bad surprise with some regulators, so this need to be tested to be sure no current goes to VOUT1, to be sure I would add a solderpad on the output of the regulator (or jumper pin)
On user view (because I can use iron solder without any problem) may be a little 2 position / 2 way switch could be easier to use to select "Use Buck/Bust" or "Straight battery".
I apologize not have been into this project sooner, I can understand it may be late for changes.

azerimaker, 2021-03-25:
We're using a variant of the RP605 with Auto-discharge circuitry (only option available with 2.8V output), so indeed, disabling the IC and feeding power directly from the VCC line might introduce some unwanted leakage paths. I'll verify how much is the leakage with this version and follow up later.
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

But in the next version, we're going to get a variant without this circuitry and looking at the simplified output circuitry we might be able supply the device from VCC without any surprise, since SW1 and SW4 will both be in OFF states. This of course also will need to be verified.
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

hallard, 2021-03-25:
@azerimaker thanks for this awesome and precise answer. That's perfect.

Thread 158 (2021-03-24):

Is Load Switch 2 for Macronix Flash really necessary?

hallard, 2021-03-24:
Load Switch 2 fir powering SPI Flash (when off) quiescent current can be 10 (typical) to 250nA (max)  and the Macronix flash in power down goes from 7nA (typical) to 350 (max). May be an option to gain some component and remove this one.
The con is to be sure to place the flash in power down when finished job, but it's also an interesting option, never used load switch with flash on my boards.

The Load Switch 1 is mandatory, not all I2C components may have descent power down mode.

elsalahy, 2021-03-25:
@hallard We asked ourselves the same question in the design process and it all comes down to the vision of having GNSE as a boilerplate.

From a FW perspective the external flash can be any external SPI flash (any external flash supporting SFDB will do the trick), so Macronix is a good option when it comes to low power consumption.
The load switch provide assurance that any component that is connected on the SPI bus can be power gated, no matter if it is a component that sleeps well or not.

The cost can be reduced according to customer needs and modifications/optimizations are welcomed.

elsalahy, 2021-03-25:
I think that would be a great topic to discuss in the [Forum](https://www.thethingsnetwork.org/forum/c/nodes/generic-node/88)

hallard, 2021-03-25:
Makes sense also, in all case would provide assurance device is disconnected :-)

By the way, may be you could add this VCC_flash (output of the switch) going to expansion port, this mean that we would be able to shutdown external sensors (or other such as GPS) populated on the expansion board without need to reproduce all power off circuit on our expansion board (and use another GPIO)

azerimaker, 2021-03-25:
Dear @hallard, these are really valuable comments. Thanks a lot.

> By the way, may be you could add this VCC_flash (output of the switch) going to expansion port, this mean that we would be able to shutdown external sensors (or other such as GPS) populated on the expansion board without need to reproduce all power off circuit on our expansion board (and use another GPIO)

We also thought about this, in fact on the very first prototype, the I2C expansion was fed by the second load switch (VCC_Flash), but we were afraid that this might cause some confusion if a user wants to add an external sensor and everytime they have to call power-down routine of the flash IC.

Load switches don't add much to the BOM and in the next rev. we will certainly consider adding one only for external use.

hallard, 2021-03-25:
Awesome, thanks, yes that's correct, always need to think on users side :-)

elsalahy, 2021-04-06:
@hallard is it ok to close this issue?

elsalahy, 2021-06-09:
Closing this issue, please re-open if necessary.

Closed 2021-06-09.

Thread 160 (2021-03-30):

Temperature certification

marnixcro, 2021-03-30:
**Summary:**
<!-- Summarize the feature in a few sentences: -->

The GNSE might have a use case for the food industry, as a temperature sensor for storage of food in transport, storage and distribution of food. To make it applicable for such a use case, certain reguluations, the [NEN norm](https://drive.google.com/file/d/1AvDF1tmegurT-abZgaKhWCY7nkcNtUON/view?usp=sharing), has to be passed for it to apply.

**Why do we need this?**
<!-- Please explain the motivation, how it will be used, etc -->

For use cases of the GNSE in the food storage industry.

**What is already there? What do you see now?**
<!-- Please attach (or link to) screenshots and logs if applicable -->

GNSE already has temperature sensors, OTA communication (with future FUOTA support), feedback with LEDs and buzzer, etc.. This can already be a start to test certain certifications.

**What is missing? What do you want to see?**
<!-- Please add some examples or mock-ups if applicable -->

A clear understanding if the GNSE could be used in these use cases, or if it could pass with minor changes to the design.

**How do you propose to implement this?**
<!--
If unsure, add the discussion label and (temporarily) assign the expert
If you cannot assign people, please @mention the experts
-->

Use the NEN-certification and see if the GNSE could pass these, or if it could pass with only minor design changes.

**Environment:**
<!-- Your environment: OS/Browser/Gateway/Device/...? Versions? IDs/EUIs? -->

GNSE

**Acceptance Criteria:**
<!--
Please explain the necessary conditions to be satisfied for this feature to be considered implemented.
These may include important test cases that need to pass, expected resource consumption improvements etc.
-->
The GNSE could pass certification (maybe with minor design changes) or it could certainly not pass the certification.

**What can you do yourself and what do you need help with?**

All

marnixcro, 2021-04-01:
# Checklist for temperature sensor application

This are a brief summary of the things that we need to do before the GNSE is ready to be a capable temperature sensor for industry use. Note that all tests are listed in chapter 6. I'll continue updating this list, and will include a separate checklist for all specific tests as these are a bit more specific (and way longer).

## Cloud (TTN and possible extensions)
- [x] All data is traceable (audit trail), timestamps and origin device should be attached to all data.
- [ ] The traceable data is kept for at least a year (if we want to do frozen food).
- [x] Data easily accessible by (authorized) users.
- [ ] Give indication that the battery is low (could also be locally with buzzer, but this seems easier)

## Hardware (enclosure and PCB)
- [ ] IP rating should be tested. The higher the IP, the more applications we could use the GNSE for (chapter 5.7).
- [ ] Temperature range should be tested (see chapter 5.10). SHTC3 should be within the best class, but you never know how the enclosure will influence this.
- [ ] The response time for the sensors in casing should be less than 20 minutes.
- [ ] Vibration testing (chapter 5.10.3), but only if we think that transportation is a good use case (might not be with LoRa, but who knows).

## Software
- [ ] Adjustable interval/limit settings (optionally, but preferably, with a downlink)
- [ ] Transmit the battery data as well
- [ ] Read Annex D for the periods the sensors have to gather data at least (these all well within reachable limits, but still good to note when designing the software).
- [ ] Software has to apply to a certain compliance based on the system (chapter 5.12)

## Misc
- [ ] Look into a few electrical power certifications: EN 61010-1 EN 61010-2, and EN 61010-3  These are only vaguely mentioned a few times (chapter 5.8 and 5.9). I don't think it is really for us (as we use low DC voltages) but maybe there is another important thing we did not note.
- [ ] Look if timing errors (chapter 5.10.2) are an issue for us (can't image it to be an issue, but still).
- [ ] If we comply, the marketing should note this as well (chapter 8).

marnixcro, 2021-06-29:
@wienke how should we move forward with this? Update the missing parts and continue, wait it out, etc.?

wienke, 2021-07-12:
Let's focus on the basic app right now and put this to the backlog.

elsalahy, 2021-08-20:
@marnixcro could you please provide a small report on the progress done on this issue from your side.

The report should be:
1. In PDF format, and uploaded [here](https://drive.google.com/drive/folders/17DJXbyA3pLFlHnEMJizYBwRDDytM6GVK?usp=sharing).
2. Should be concise detailing the requirements, your analysis and achieved results.

elsalahy, 2021-10-12:
This issue was moved to our discuss.

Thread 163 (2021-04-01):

Antenna Performance w/ and w/o enclosure.

ehogeweg, 2021-04-01:
Hi,

I noticed that the enclosure screws are close to the antenna clearance area. I expect this has some impact on the tuning frequency. Is there any data, that you can share, on how the antenna performs on a bare board vs. enclosed? Does the matching network require different component?

Cheers,

Erwin

azerimaker, 2021-04-12:
Thank you for you interest, @ehogeweg.
I understand your concern. In fact, we've discussed this even before we had the PCBs at hand in issues #89, #128.
The enclosure and the close proximity of the screws has certainly some impact on the ANT performance, however we don't have any comparison data or quantitative info on that at this moment.
We're working on it and once we have it, I'll share our findings here.

azerimaker, 2021-05-05:
@ehogeweg , @lnlp I did a basic efficiency test using my NanoVNA. Please see the results here ➡️  https://github.com/TheThingsIndustries/generic-node-se/issues/89#issuecomment-833003749
You're right, the enclosure and the batteries do affect the antenna performance and removing it results in shifting the tuning frequency upwards. In the coming weeks the device will go through proper matching network retuning. Hopefully, this will provide good performance with the enclosure on.

elsalahy, 2021-07-05:
@azerimaker did Ignion provide any feedback on the effect of the enclosure on the antenna performance?

azerimaker, 2021-07-05:
> @azerimaker did Ignion provide any feedback on the effect of the enclosure on the antenna performance?

unfortunately their "Matching Network Optimization" service doesn't include that, but I will ask them to perform those tests, hopefully they agree to that.

azerimaker, 2021-07-07:
@lnlp Ignion has conducted the above mentioned tests and it's clear that frequency shift is major. One should use the device as a fully assembled unit if they want to achieve good coverage.  I hope this answers your question. If there are no further discussion, please consider closing this issue.

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

azerimaker, 2021-07-07:
> For positioning of the device it will be interesting to know the radiation pattern and how the device can be best positioned for optimal RF coverage/range. _(The battery holder and batteries will block, reflect and deflect RF signals.)_

Unlike anticipated the batteries and the contacts didn't have major impact on the antenna performance and its radiation pattern. Please see the results below for your reference.

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

elsalahy, 2021-07-07:
@ehogeweg  Does the above answer provide sufficient information for GNSE use with an enclosure.
If yes, could you please the issue

ehogeweg, 2021-07-09:
Sorry, I completely missed your comments. Yes, this answers the question. Thanks for providing the graphs.

Cheers,

Erwin

Closed 2021-07-09.

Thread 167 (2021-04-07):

Buzzer only works during HAL_Delay function

marnixcro, 2021-04-07:
**Summary:**
<!-- Summarize the problem in a few sentences: -->

The buzzer seems to only work in certain circumstances. The basic app seems to work fine, with the buzzer playing at the end. However, when integrating it into another application, it seems to be more difficult. It will not produce sounds at all if HAL_Delay is not initiated. The sounds seem to start when HAL_Delay is running and will stop after HAL_Delay is fixed.

**Steps to Reproduce:**
<!-- How can we reproduce the problem? -->

Add this to stm32wlxx_it.c
`void TIM2_IRQHandler(void)`
`{`
  `HAL_TIM_IRQHandler(&GNSE_BSP_buzzer_timer);`
`}`

Then to reproduce the issue:
1. Call BUZZER_Init and BUZZER_SetState at the start of the program
2. Do not call HAL_Delay afterwards
3. See if the buzzer can be heard

To ring the buzzer:
1. Call BUZZER_Init and BUZZER_SetState at the start of the program
2. Call HAL_Delay, can be anywhere in the program and on multiple occasions
3. The buzzer will beep for the duration of the delay, but stops (without calling BUZZER_SetState with BUZZER_STATE_OFF)

<!-- Please attach (or link to) configuration files if applicable -->

**What do you see now?**
<!-- Please attach (or link to) screenshots and logs if applicable -->

This snippet
  `BUZZER_Init();`
  `BUZZER_SetState(BUZZER_STATE_RING);`
  `HAL_Delay(1000);`

Produces this power graph
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
It seems to only work whilst HAL_Delay is initiated, it should still ring but it just stops after HAL_Delay. Also, the power consumption afterwards is noticeably higher while the buzzer is off (15 mA). Without this delay, the buzzer will not do anything at all.

Not handling the interrupt by not setting TIM2_IRQHandler also makes the buzzer work (but this disables most other functionalities). So it seems that not handling the interrupts will make the buzzer work as expected

**What do you want to see instead?**
<!-- Please add some examples or mock-ups if applicable -->

A buzzer that can make sounds whilst the program is running normally.

**How do you propose to implement this?**
<!--
If unsure, add the discussion label and (temporarily) assign the expert
If you cannot assign people, please @mention the experts
-->

Improve the interrupt handling of the buzzer.

**Environment:**
<!-- Your environment: OS/Browser/Gateway/Device/...? Versions? IDs/EUIs? -->

Bare metal

**What can you do yourself and what do you need help with?**

All

elsalahy, 2021-04-07:
I think this can be fixed by doing a minor adjustment of the interrupt priority as it seems the system is starved by the RTC

elsalahy, 2021-04-07:
Adjusting this [config flag ](https://github.com/TheThingsIndustries/generic-node-se/blob/64d5f1dde90e6234c5c346f538453cfb24fce062/Software/lib/GNSE_BSP/GNSE_bsp_conf.h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)might fix this issue

marnixcro, 2021-04-08:
Small update: The interrupt priority does not fix the issue. This bug seems to be related to the LoRa library, the delay only halted LoRa code to be initiated for some time. There was only one instance where I got it working after LoRa was activated, but it required for the interrupt handler for timer 2 to not be defined (causing the code to break and loop in the interrupt handler). Basic app seems to work fine if the buzzer is kept on during its while loop.

marnixcro, 2021-04-09:
Extra update: I did get the buzzer to work when simply toggling the pin with the sequencer, so the issue seems to be related to the PWM timer during a LoRa message.

azerimaker, 2021-04-12:
@marnixcro with the PWM timer, please make sure the GPIO line stays LOW before and after each PWM burst, otherwise the driver transistor (Q2) will stay ON and there will be quite significant leakage through the buzzer.

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

marnixcro, 2021-04-14:
Update: Can't believe I didn't think of this sooner, but the problem lies with the low power mode. This peripheral turns of the timer used in the PWM mode, HAL_Delay only delayed this timer. Apparently the low power mode kicks in just before the transmission but almost immediately wakes up to connect to the LoRAWAN, so that's why it turns off before the sending. It also explains why I could toggle it manually as the mode does allow for the pin state to be kept. I hoped setting LOW_POWER_DISABLE would be enough but sadly it doesn't.

Here an image for reference of the stop mode capabilities (default used is stop mode)
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

TIM2 can't be remapped to LSI, only LSE, which I believe doesn't work for us since we did not connect any external oscillator.
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

Maybe a discussion point is needed as there are quite a few ways to handle this. I could to one of these things:

1. Try different sleep modes and see if the PWM does work in another one.
2. Use a simple manual configuration for the buzzer (setting tasks to turn it on and off), without using the buzzer library.
3. Don't use the buzzer at all.
4. Temporarily turn off sleep mode during the buzzer beeping (it was consuming a lot of power anyways) and turning it on afterwards.
5. Try to create buzzer options where LSI is used (would require an interrupt handler as the PWM generation only specific timers).

elsalahy, 2021-04-14:
@marnixcro what do you mean by
> I hoped setting LOW_POWER_DISABLE would be enough but sadly it doesn't.

Please explain it clearly, does `LOW_POWER_DISABLE` config flag not function as expected?

marnixcro, 2021-04-14:
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

It probably went into another mode, but the PWM didn't work in sleep mode either I believe. It was one test, I'll try again and see if I can make it work.

elsalahy, 2021-04-14:
@marnixcro Please trace what the flag does before coming to a conclusion and raising a discussion.
I assumed you are aware of the fact that freefall app (developed by you) doesn't support low power mode yet.

elsalahy, 2021-04-14:
You can invoke `UTIL_LPM_GetMode` and you will observe active mode.
Check `LOW_POWER_DISABLE` and you will see that the node defaults to a sleep mode if stop and off mode are disabled.

marnixcro, 2021-04-14:
Tested free fall app again with the flag set to one and the buzzer seemed to work (accidentally changed the wrong app_config before). Here is an overview of the different power consumptions.
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

About UTIL_LPM_GetMode, i tested with the normal configurations and got this:
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
Placed it at the very end of SystemApp_Init
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
1 is UTIL_LPM_STOPMODE.
When setting LOW_POWER_DISABLE=1 then this happened:
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
0 is UTIL_LPM_SLEEPMODE

elsalahy, 2021-04-16:
@marnixcro what is the current state on this?

elsalahy, 2021-04-16:
If this issue doesn't describe the main problem, it should be closed to avoid confusing GN users.
We have multiple sleep related issues that are WIP.

elsalahy, 2021-04-16:
@marnixcro this [code](https://github.com/TheThingsIndustries/generic-node-se/blob/80b9796253f6563bcabe5c59ef3e65d8e35fc403/Software/app/basic_lorawan/sys_app.c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) shows how we disable stop mode when wanting to perform a specific functionalit

Closed 2021-04-16.

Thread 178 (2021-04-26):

GNSE sensors sampling app (vanilla version)

elsalahy, 2021-04-26:
**Summary:**
<!-- Summarize the feature in a few sentences: -->

We need to build an application showing sampling board sensors and sending the data over LoRaWAN.

**Why do we need this?**
<!-- Please explain the motivation, how it will be used, etc -->

To show board usage and have foundation firmware for production and certification.

**What is already there? What do you see now?**
<!-- Please attach (or link to) screenshots and logs if applicable -->

Basic apps.

**What is missing? What do you want to see?**
<!-- Please add some examples or mock-ups if applicable -->

An advanced low power application that samples the data and sends information over LoRaWAN.

**How do you propose to implement this?**
<!--
If unsure, add the discussion label and (temporarily) assign the expert
If you cannot assign people, please @mention the experts
-->

Using basic apps, doing power analysis and using HAL APIs

**Environment:**
<!-- Your environment: OS/Browser/Gateway/Device/...? Versions? IDs/EUIs? -->

Baremetal

**Acceptance Criteria:**
<!--
Please explain the necessary conditions to be satisfied for this feature to be considered implemented.
These may include important test cases that need to pass, expected resource consumption improvements etc.
-->
- Low power
- Compiles with no warnings
- Extremely configurable
- Used GNSE HAL

**What can you do yourself and what do you need help with?**

All

descartes, 2021-05-14:
Having just answered a question on the forum about the existence of the payload formatter for what we are assuming to be the pre-loaded firmware, I have to express some considerable surprise that there isn't a simple example reading one of the sensors and sending it - this to me would be the most blindingly obvious hello-world app for a LoRaWAN device and it's whole raison d'être!

elsalahy, 2021-05-18:
@descartes Yes agreed.
We should prioritize this issue.

descartes, 2021-05-20:
Looking at your original text again, I'd recommend having three versions - one that just reads a sensor & sends the data, then an incremental version that adds in low power / sleep, then what ever meets the criteria for 'advanced'.

I'd shy away from "extremely configurable" as that usually infers either lots of #defines or lots of OOP or both and then people have trouble tracing the code and get confused.

elsalahy, 2021-06-29:
This issue is partially addressed in #194
The completion of this issue depends on #171

elsalahy, 2021-08-25:
This is closed by #205

Closed 2021-08-25.

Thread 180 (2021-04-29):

Improve freefall_lorawan power settings

marnixcro, 2021-04-29:
**Summary:**
<!-- Summarize the feature in a few sentences: -->

Currently the free fall app consumes ~100 uA in its sleep mode. This can be lowered by utilising the power modes correctly with the free fall detection. The lowest power consumption should also be tested and documented.

**Why do we need this?**
<!-- Please explain the motivation, how it will be used, etc -->

To lower power consumption and give an for the free fall app's power consumption.

**What is already there? What do you see now?**
<!-- Please attach (or link to) screenshots and logs if applicable -->

Working free fall application with ~100 uA current consumption. Turning off the load switch reduces this to ~2 uA (similar to basic_lorawan). No power optimisations where implemented yet with the design.

**What is missing? What do you want to see?**
<!-- Please add some examples or mock-ups if applicable -->

Improved settings for the LIS2DH12 free fall initialisation and an indication of the possible power consumption of the free fall application.

**How do you propose to implement this?**
<!--
If unsure, add the discussion label and (temporarily) assign the expert
If you cannot assign people, please @mention the experts
-->

- Lower the ODR and test if free fall detection still works.
- Activate the lowest power mode that still support free fall detection.
- Set the other peripherals (SHTC3 and ATECC608A) in the most optimal low power mode if possible (for testing purposes)

**Environment:**
<!-- Your environment: OS/Browser/Gateway/Device/...? Versions? IDs/EUIs? -->

Bare metal

**Acceptance Criteria:**
<!--
Please explain the necessary conditions to be satisfied for this feature to be considered implemented.
These may include important test cases that need to pass, expected resource consumption improvements etc.
-->
Lowered power consumption on the GNSE.

**What can you do yourself and what do you need help with?**

This issue is only for the free fall application power settings and testing how far it can go into low power mode. Issue #171 relates to the actual low power manager for the peripherals (including the LIS2DH12).

elsalahy, 2021-05-31:
Blocked on #171

Closed 2021-07-28.

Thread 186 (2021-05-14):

Out-the-box firmware source code does not appear to be available

descartes, 2021-05-14:
**Summary:**
We don't know what the default firmware is doing or sending

See https://www.thethingsnetwork.org/forum/t/box-opening-no-video/45548/13

**Steps to Reproduce:**

1. Obtain node
2. Register it
3. Turn it on
4. Look at blinkenlights
5. Admire uplink in console
6. Not have clue what uplink means

**What do you see now?**
A payload with no meaning

**What do you want to see instead?**
Preferably the source code, from which I can create a payload formatter

Or documentation on the payload so I can create a payload formatter

Or a payload formatter

**How do you propose to implement this?**
Using my Ninja Payload Formatting skillz - or more likely, my Payload Formatter spreadsheet that I use to create Payload Formatters semi-automatically

**What can you do yourself and what do you need help with?**
Depends on what resources you provide!

I can also add this to the device repository as well.

elsalahy, 2021-05-18:
@descartes
The 100 batch was shipped with basic app as a default FW, and it prints serial information using UART at 115200 8N1.

I will prioritize #178 sensors vanilla app as this will be the application that will be used in the next batch.
And I can provide a simple payload formatter or provide some support to you in case you want to take this on.

For now, this is pending on #178

descartes, 2021-05-20:
> And I can provide a simple payload formatter or provide some support to you in case you want to take this on.

I'm happy to create a simple starter app and payload formatter if that's what you are suggesting. If it's just the payload formatter, I have an app for that.

descartes, 2021-05-20:
PS, I need a simple something running for the mini-conference at the end of next week for my talk on WebHooks, so I will be creating a sensor read & send example anyway.

azerimaker, 2021-05-20:
I've already replied on the [forum](https://www.thethingsnetwork.org/forum/t/box-opening-no-video/45548/26?u=cndrxn), just adding here for redundancy.
@descartes if you want something quick and dirty you can check out this [branch](https://github.com/TheThingsIndustries/generic-node-se/blob/feature/basic_lorawan_TH/Software/app/basic_lorawan_th/lora_app.c), which sends temperature and humidity values.

Simple payload decoder I used:
```
function decodeUplink(input) {
  var data = {};
  data.temperature = ((input.bytes[0] << 8) + input.bytes[1]-400)/10;
  data.humidity = ((input.bytes[2] << 8) + input.bytes[3])/10;
  return {
    data: data,
  };
}
```

elsalahy, 2021-05-20:
@descartes check @azerimaker [comment](https://www.thethingsnetwork.org/forum/t/box-opening-no-video/45548/26?u=elsalahy), maybe this is a good simple example for you.

descartes, 2021-05-20:
All good, rest assured as a moderator I read every single post, all of them - mostly skimming them for guidelines, but still, redundancy for the win!

descartes, 2021-05-20:
The payload formatter you have is a v2 style which still works, but I'll update it / create something to run on v3. I cut my teeth on LiveScript back in Sept 1995 so my biggest problem now a days is typing the right programming language in to the right IDE.

elsalahy, 2021-06-29:
This issue is partially addressed in #194
The new patch of devices will have the `sensors_lorawan` application  communicated in #178.

@descartes is your issue addressed in the new application `sensors_lorawan`?
If yes, is it possible to close this issue?

descartes, 2021-07-01:
Yes, gives something sensible as a starter and pretty much the same as the code I used for my TTS conference demo on WebHooks.

Sleep will need to be added very soon - the most basic of nodes usually reads & sends sensor data & then sleeps for a chunk of time.

Closed 2021-07-01.

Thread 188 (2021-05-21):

Road to circular IoT device

wienke, 2021-05-21:
**Summary:**
Inspired by this great new initiative (https://cep2030.org) this thread is focussed on discussion around how to include circularity by design.

**Why do we need this?**
We need to work towards a more circular product. The big IoT promise can not come at the cost of a huge amount of environmental waste. We are smart and resourceful enough to make products that are both more sustainable and durable.

**What is already there? What do you see now?**
Looking at the current design we already implemented some features that should make the product more sustainable.

- We focussed on a power management design that is able to optimize the use of alkaline batteries. Assuming that most places in the world already have a circular economy for this type of batteries. Also it is the most common battery. The chance of somebody getting rid of the product once batteries need to be replace because it uses some kind of exotic industrial battery is lowered. Also through a hardware switch the device can be switched to using 3v batteries (violates the certification)
- The design is modular. You are able to upgrade or repurpose the device later on by extending it with sensors, changing the casing, upgrading the firmware and changing the radio technology used through firmware.
- We added a piezo speaker. LPWAN devices are typically installed out of sight. To re-purpose the device you first have to find it. By sending it a commend to play a tune you will be able to find it.

**What is missing? What do you want to see?**

So there are many more design patters we should be able to implement.
- Implementing accountability. The device is equipped with a Secure Enclave. So the device will have a uniquely traceable identity. This also allows for the transfer of ownership. And also allows for administrating accountability to that owner for re-cycling and re-purposing. Adding a deposit model to this might bring the right incentives as well.
- Creating a second hand market that is generating demand for re-purposed IoT sensors.
- Creating a license model that discounts usage in proper circular ways.

elsalahy, 2021-07-01:
@azerimaker care to comment on this proposal.

@wienke what should be the outcome of this issue, and should we move this discussion to our Discuss forum?

wienke, 2021-07-07:
This is indeed a place holder for now. We can move it to the backlog.

azerimaker, 2021-07-07:
@wienke (https://cep2030.org) is indeed a great initiative. IMO our GN doesn't really fit into their initial product categories (temperature exchange equipment, screens and monitors, lamps, large equipment, and small IT) we can still consider planning ahead for reducing e-waste. Some big players like Apple have full control over the production and they can control the whole supply chain, push component manufacturers to produce components only from recycled materials.

Using recycled materials in the design, making it more repairable are good design choices, but heavily emphasizing it for marketing gain is not so much.

TheThingsBot, 2021-09-24:
This issue has been mentioned on **Discuss The Things Industries**. There might be relevant details there:

https://discuss.thethingsindustries.com/t/road-to-circular-iot-device/658/1

elsalahy, 2021-09-24:
Any discussion on this topic should take place [here](https://discuss.thethingsindustries.com/t/road-to-circular-iot-device/658)

Closed 2021-09-24.

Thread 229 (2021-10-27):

Better enclosure screws

elsalahy, 2021-10-27:
**Summary:**
<!-- Summarize the feature in a few sentences: -->

Can we investigate if the enclosure screws material can be changed to something that is more durable.
The current enclosure screws can't handle the screw driver pressure and tend to have edge deformity if screwed and unscrewed multiple times.

CC: @wienke and @azerimaker

NicolasMrad, 2022-03-29:
@azerimaker did you test out the durability of the screws?

azerimaker, 2022-04-19:
@NicolasMrad current screws are the default ones supplied by the manufacturer and after various mechanical torture testing they seem to hold OK. I don't see a reason to upgrade them right now.

Closed 2022-04-19.

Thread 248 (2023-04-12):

High current consumption in "stop mode"

ThomasBaumgartner, 2023-04-12:
**Summary:**
<!-- Summarize the problem in a few sentences: -->
I configured the application with lowpower options. I connected power analyser to the device (Generci Noce V1.1)and measured current consumption during stop mode. The power analyser was indicating a minimum current consumption of 33uA, which is rather high.

**Steps to Reproduce:**
<!-- How can we reproduce the problem? -->

1. In app_conf.h set:
GNSE_ADVANCED_TRACER_ENABLE 0
DEBUGGER_ON       0

2. build and flash sensors_lorawan application
3. Measure the current consumption

<!-- Please attach (or link to) configuration files if applicable -->

**What do you see now?**
<!-- Please attach (or link to) screenshots and logs if applicable -->
Minimum current consumption of 33uA, normal current consumption during join / send procedure.

**What do you want to see instead?**
<!-- Please add some examples or mock-ups if applicable -->
A minimum current consumption of <5uA.

Has anybody experienced similar behaviour? Anybody able to have lower current consumption in low power mode?
 @azerimaker

azerimaker, 2023-04-12:
Hi, @ThomasBaumgartner

thank you for raising this issue. The extra ~31uA is usually the result of the battery monitor circuit being left ON. This was a minor bug which was addressed in the `sensors_lorawan_se` app. Please refer to [Software/app/sensors_lorawan_se/sensors.c](https://github.com/TheThingsIndustries/generic-node-se/commit/532066aa9d1b59a6e9d9434ae63ec6c2640ed7a8) to make sure your code follows the same sequence and let us know the results.
I hope it helps.

azerimaker, 2023-04-13:
Happy to help, @ThomasBaumgartner .

Closed 2023-04-12.

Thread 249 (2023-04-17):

Generic Node SE Edition on AU915 band

ingmanuelalfonso, 2023-04-17:
**Summary:**
I am testing for the first time the Generic Node SE and found that using the provided libraries something is wrong when tryed the AU915 band. The device came with EU868 but its possible to enable US915 but not AU915. Someone else had this problem?.

...

**Steps to Reproduce:**

1. ... Using STM32CUBE IDE and using basic_lorawan example
2. ... On lora_app.h edited ACTIVE_REGION to LORAMAC_REGION_AU915
3. ... In lora_info.c the REGION_AU915 is in gray color as other bands.

I noted that is possible to disolder hardware components that goes to Ceramic Antena and solder ones to go to the external antenna connector but sure this is not the problem

ingmanuelalfonso, 2024-05-20:
I came back to the same topic to inform I am able to communicate using AU915.

- I am using sensors_lorawan App example
- I am using Chirpstack 3.0 as a network and application server
- I am using OTAA.
- I am using RAk7271 8 channel gateway connected to a raspberry pi 3b+

azerimaker, 2024-05-21:
Thank you for the update, @ingmanuelalfonso.

Closed 2024-05-20.

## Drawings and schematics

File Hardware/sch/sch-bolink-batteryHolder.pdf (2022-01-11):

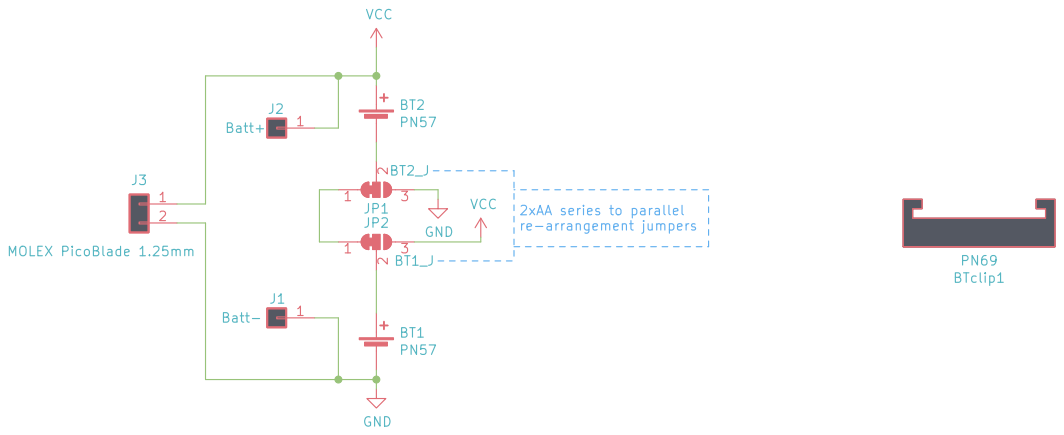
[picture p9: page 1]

drawn by: Orkhan AmirAslan (azerimaker)
File: pcb-bolink-batteryHolder.kicad_sch Sheet: / The Things Industries

Id: 1/1 Title: Generic Node Battery Holder

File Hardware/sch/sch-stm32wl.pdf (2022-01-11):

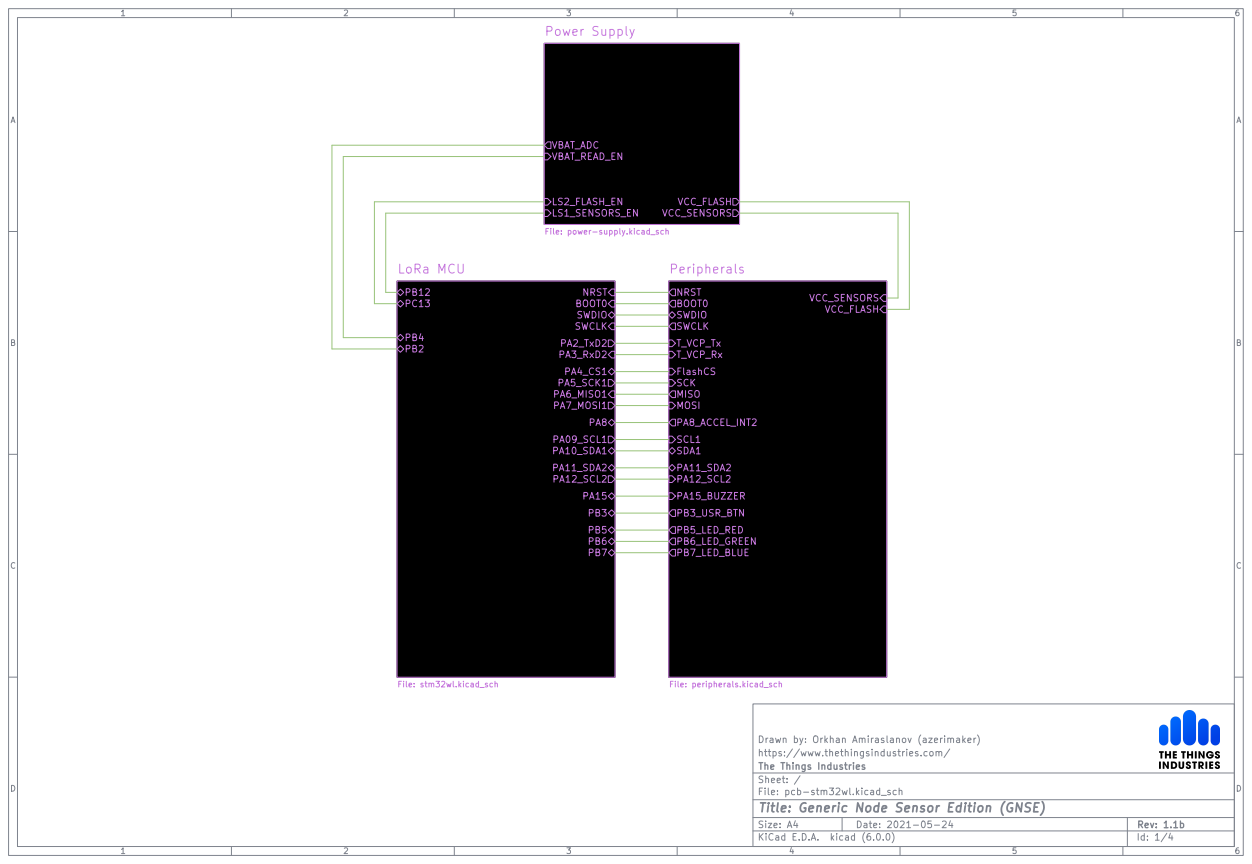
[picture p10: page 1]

File: power-supply.kicad_sch SWDIO

Drawn by: Orkhan Amiraslanov (azerimaker)
https://www.thethingsindustries.com/
File: pcb-stm32wl.kicad_sch Sheet: / The Things Industries

Id: 1/4 Title: Generic Node Sensor Edition (GNSE)

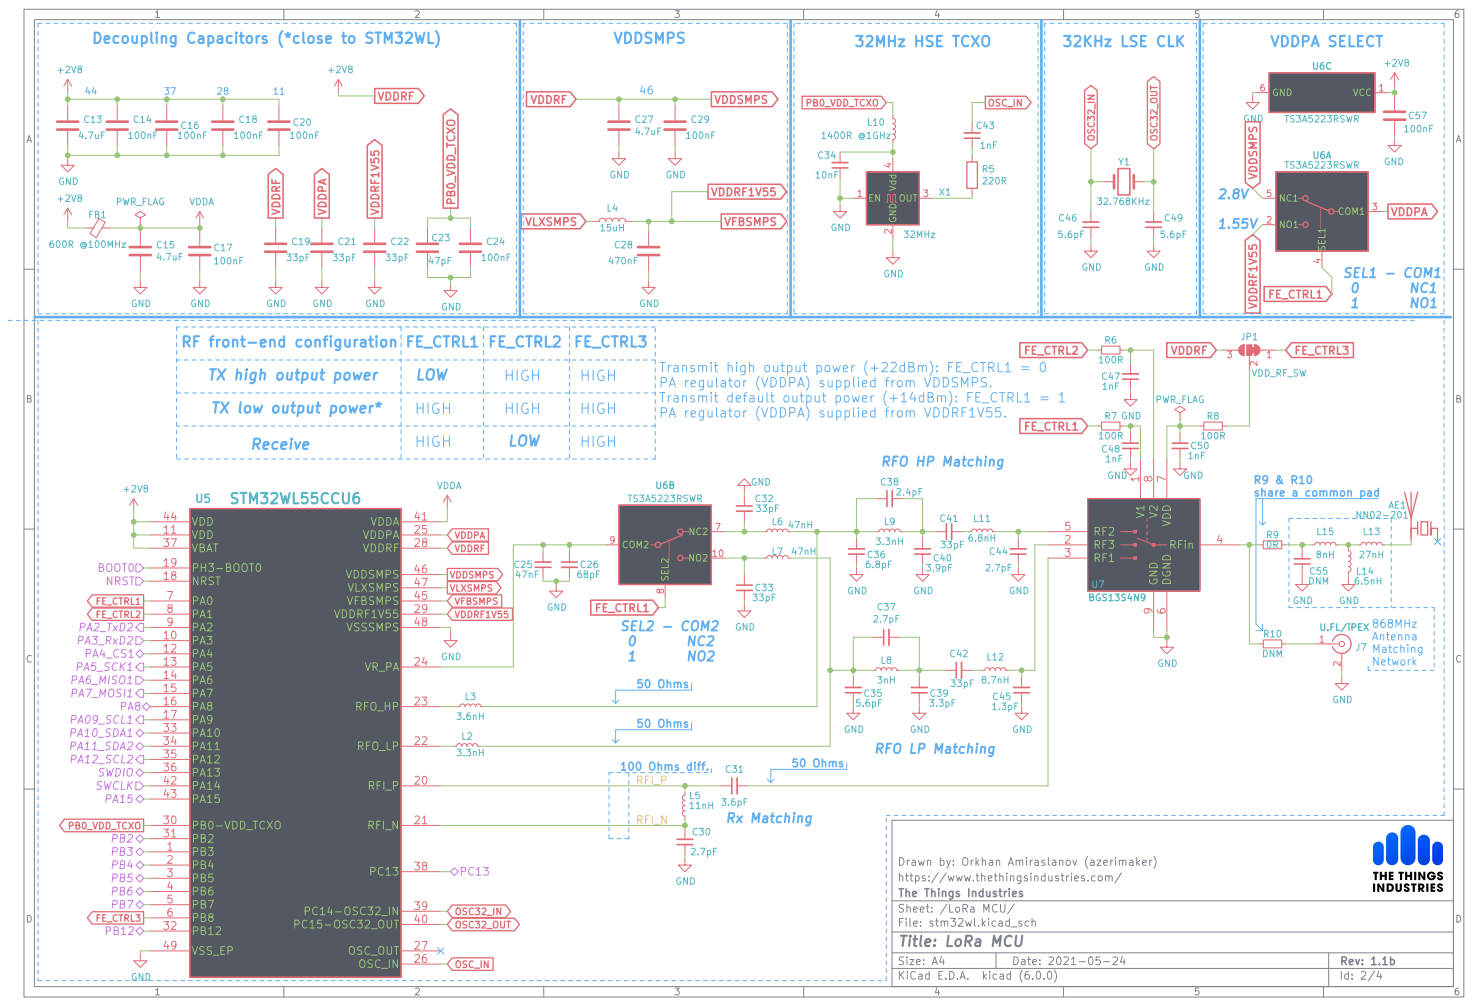
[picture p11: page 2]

Decoupling Capacitors (*close to STM32WL)

RF front-end configuration | | FE_CTRL1 | FE_CTRL2
TX high output power | LOW
TX low output power*

PA regulator (VDDPA) supplied from VDDSMPS.
Transmit default output power (+14dBm): FE_CTRL1 = 1
PA regulator (VDDPA) supplied from VDDRF1V55.

868MHz Antenna Matching Network HIGH
LOW

Drawn by: Orkhan Amiraslanov (azerimaker) GND

https://www.thethingsindustries.com/
File: stm32wl.kicad_sch Sheet: /LoRa MCU/ The Things Industries

Id: 2/4 Title: LoRa MCU

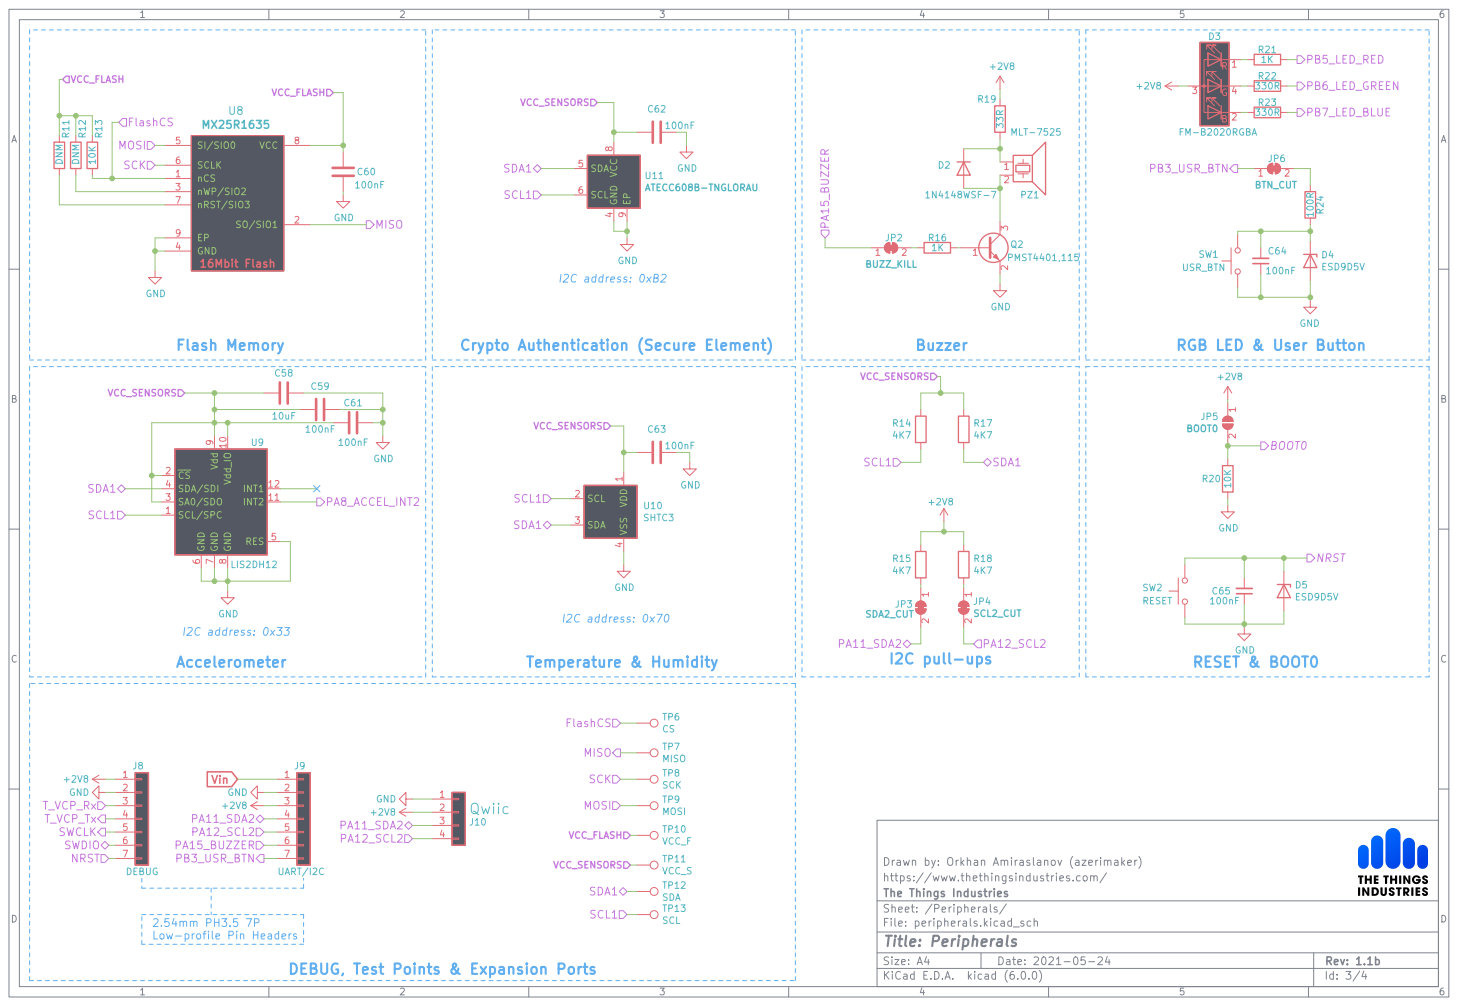
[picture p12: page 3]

Drawn by: Orkhan Amiraslanov (azerimaker) R15

https://www.thethingsindustries.com/
The Things Industries
Sheet: /Peripherals/
File: peripherals.kicad_sch
Id: 3/4 Title: Peripherals

2.54mm PH3.5 7P Low-profile Pin Headers

DEBUG, Test Points & Expansion Ports

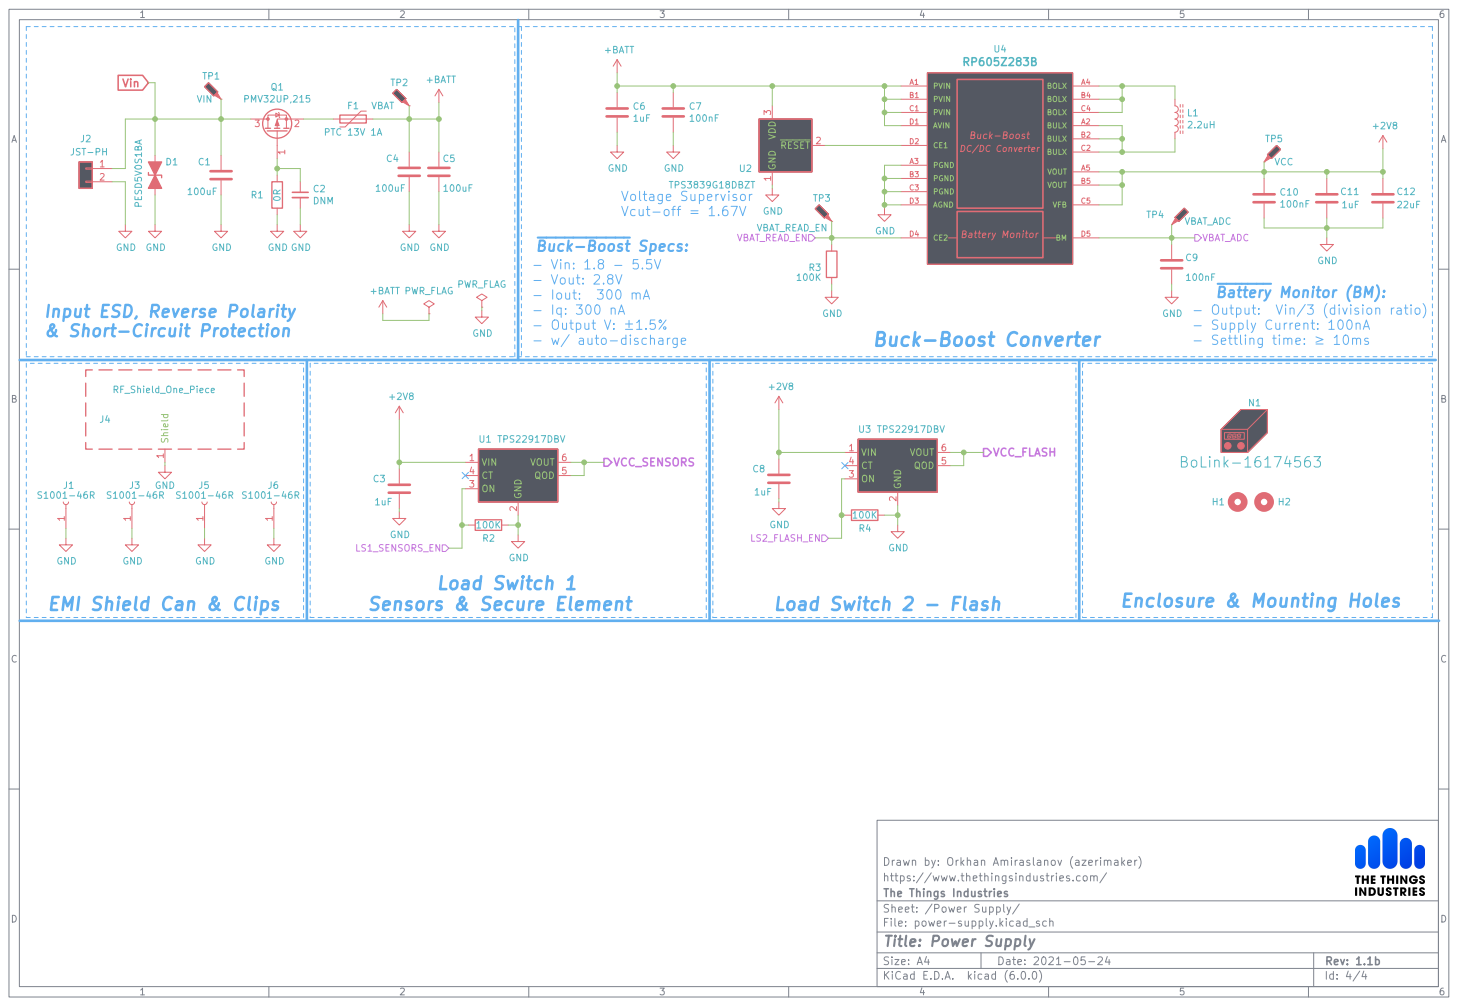
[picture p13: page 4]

~{Battery} Monitor (BM):
- Output: Vin/3 (division ratio)
- Supply Current: 100nA

Input ESD, Reverse Polarity
& Short-Circuit Protection

2 ON 3 CT 4 QOD 5 VOUT 6 U3 TPS22917DBV

2 ON 3 CT 4 QOD 5 VOUT 6 U1 TPS22917DBV R2

Drawn by: Orkhan Amiraslanov (azerimaker) 1 J3 S1001-46R

https://www.thethingsindustries.com/
The Things Industries
Sheet: /Power Supply/
File: power-supply.kicad_sch
Id: 4/4 Title: Power Supply

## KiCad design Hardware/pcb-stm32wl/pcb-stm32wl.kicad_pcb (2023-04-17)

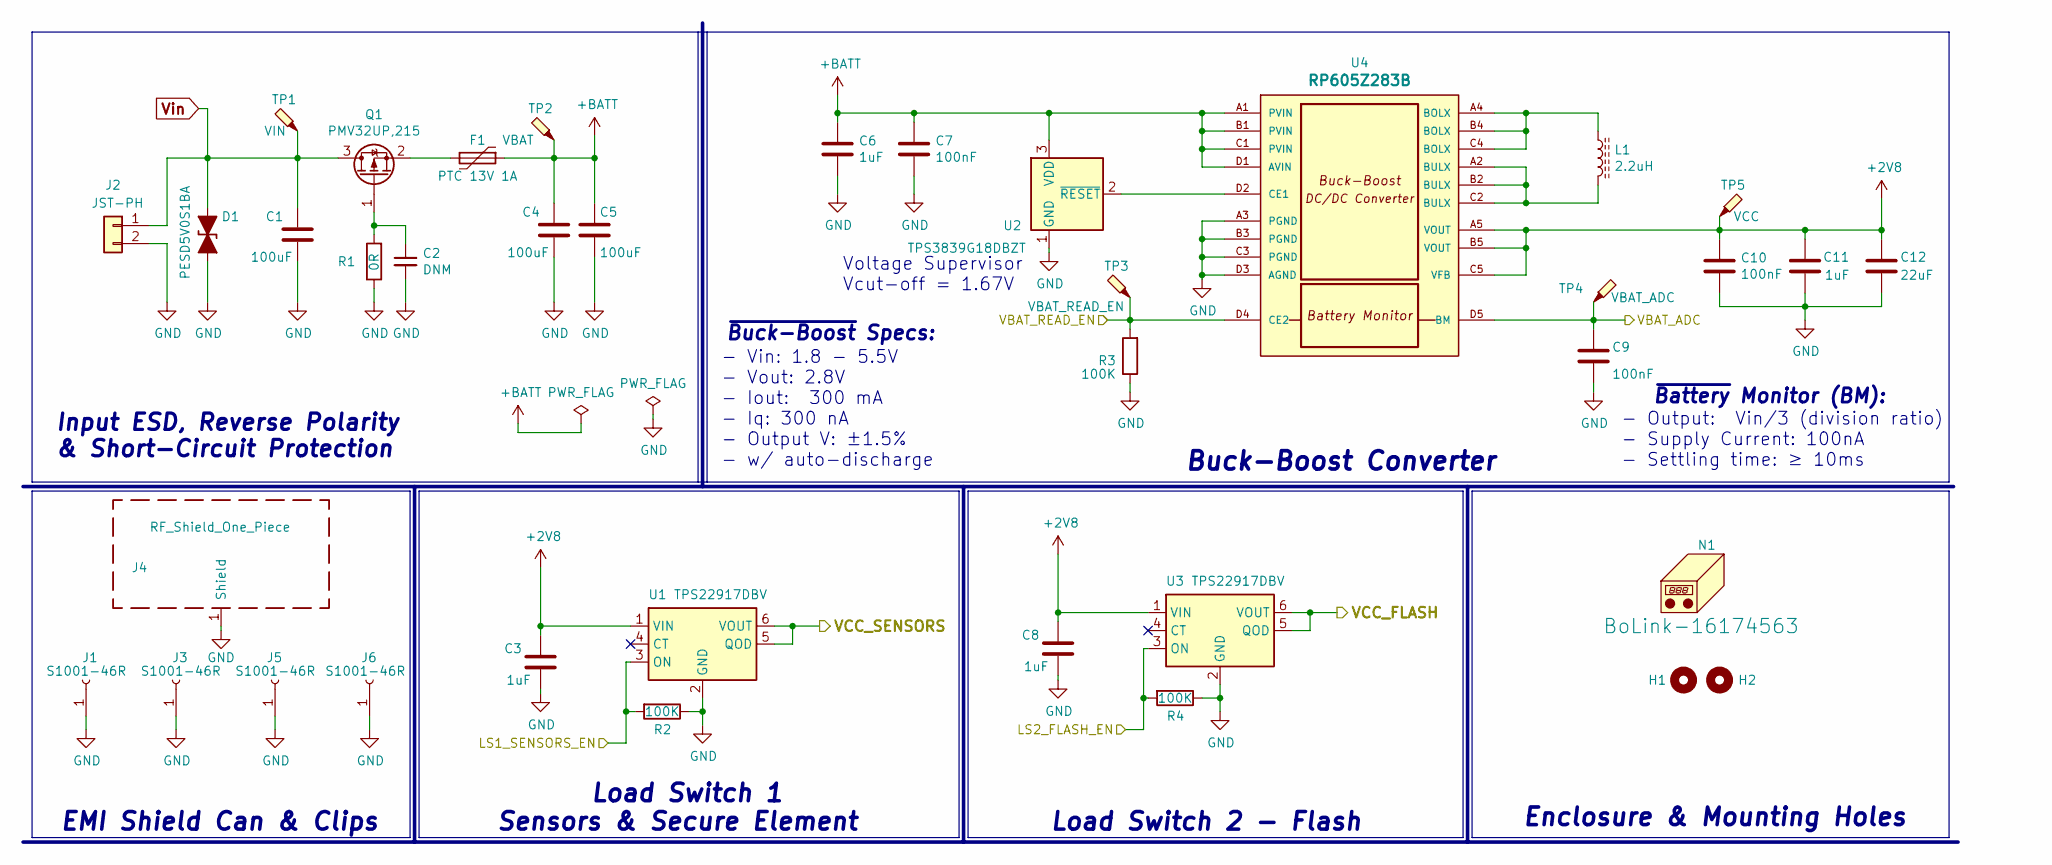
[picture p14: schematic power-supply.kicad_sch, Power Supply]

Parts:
C1, C4, C5: 100uF; C_1206_3216Metric; MPN JMK316ABJ107ML-T
C2: DNM; C_0402_1005Metric; MPN CC0402KRX7R7BB103
C3, C6, C8, C11: 1uF; C_0402_1005Metric; MPN CL05A105KQ5NNNC
C7, C9, C10: 100nF; C_0402_1005Metric; MPN CC0402KRX7R7BB104
C12: 22uF; C_0603_1608Metric; MPN CC0603MRX5R5BB226
D1: PESD5V0S1BA; D_SOD-323; MPN PESD5V0S1BA,115
F1: PTC 13V 1A; Fuse_1210_3225Metric_Castellated; MPN SMD1210-050
H1, H2: MountingHole; MountingHole_2.5mm
J1, J3, J5, J6: S1001-46R; RF_Shield_Clip_S1001-46R; MPN DNM
J2: JST-PH; JST_PH_B2B-PH-SM4-TB_1x02-1MP_P2.00mm_Vertical; MPN B2B-PH-SM4-TB(LF)(SN)
J4: RF_Shield_One_Piece; RF_Shield_SnapOn_30x20mm_w_Cutout_n_GND_Pads; MPN DNM
L1: 2.2uH; L_HPC4012TF-2R2M; MPN HPC4012TF-2R2M
N1: BoLink-16174563; BoLink_704025; MPN DNM
Q1: PMV32UP,215; SOT-23; MPN PMV32UP,215
R1: 0R; R_0402_1005Metric; MPN RC0402FR-070RL
R2, R3, R4: 100K; R_0402_1005Metric; MPN RC0402FR-07100KL
TP1: VIN; TestPoint_Pad_D1.5mm; MPN DNM
TP2: VBAT; TestPoint_Pad_D1.5mm; MPN DNM
TP3: VBAT_READ_EN; TestPoint_Pad_D1.5mm; MPN DNM
TP4: VBAT_ADC; TestPoint_Pad_D1.5mm; MPN DNM
TP5: VCC; TestPoint_Pad_D1.5mm; MPN DNM
U1, U3: TPS22917DBV; SOT-23-6; MPN TPS22917DBVR
U2: TPS3839G18DBZT‎; SOT-23; MPN TPS3839G18DBZT‎
U4: RP605Z283B; WLCSP-20-P3_1.994x1.609mm_Layout5x4_P0.4mm; MPN RP605Z283B-E2-F

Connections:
+BATT: C4.2, C5.2, C6.1, C7.1, F1.1, TP2.1, U2.3 (VDD), U4.A1 (PVIN), U4.B1 (PVIN), U4.C1 (PVIN), U4.D1 (AVIN)
/LoRa MCU/PB2: C9.1, TP4.1, U4.D5 (BM); also elsewhere on the board
/LoRa MCU/PB4: R3.2, TP3.1, U4.D4 (CE2); also elsewhere on the board
/Peripherals/VCC_FLASH: U3.5 (QOD), U3.6 (VOUT); also elsewhere on the board
/Peripherals/VCC_SENSORS: U1.5 (QOD), U1.6 (VOUT); also elsewhere on the board
/Power Supply/LS1_SENSORS_EN: R2.2, U1.3 (ON); also elsewhere on the board
/Power Supply/LS2_FLASH_EN: R4.2, U3.3 (ON); also elsewhere on the board
GND: C1.1, C2.2, C3.2, C4.1, C5.1, C6.2, C7.2, C8.2, C9.2, C10.1, C11.2, C12.1, D1.2 (A2), J1.1, J2.2, J3.1, J4.1, J5.1, J6.1, R1.1, R2.1, R3.1, R4.1, U1.2 (GND), U2.1 (GND), U3.2 (GND), U4.A3 (PGND), U4.B3 (PGND), U4.C3 (PGND), U4.D3 (AGND); also elsewhere on the board
unnamed: C2.1, Q1.1 (G), R1.2
unnamed: F1.2, Q1.2 (S)
unnamed: L1.1, U4.A4 (BOLX), U4.B4 (BOLX), U4.C4 (BOLX)
unnamed: L1.2, U4.A2 (BULX), U4.B2 (BULX), U4.C2 (BULX)
unnamed: U2.2 (~RESET), U4.D2 (CE1)
VDDRF: C3.1, C8.1, C10.2, C11.1, C12.2, TP5.1, U1.1 (VIN), U3.1 (VIN), U4.A5 (VOUT), U4.B5 (VOUT), U4.C5 (VFB); also elsewhere on the board
Vin: C1.2, D1.1 (A1), J2.1, Q1.3 (D), TP1.1; also elsewhere on the board

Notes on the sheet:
- Output: Vin/3 (division ratio) - Supply Current: 100nA - Settling time: ≥ 10ms
Buck-Boost Converter
EMI Shield Can & Clips
~{Buck-Boost} Specs:
- Vin: 1.8 - 5.5V - Vout: 2.8V - Iout: 300 mA - Iq: 300 nA - Output V: ±1.5% - w/ auto-discharge
Load Switch 1 Sensors & Secure Element
Load Switch 2 - Flash
Enclosure & Mounting Holes
Voltage Supervisor Vcut-off = 1.67V
~{Battery} Monitor (BM):
Input ESD, Reverse Polarity & Short-Circuit Protection

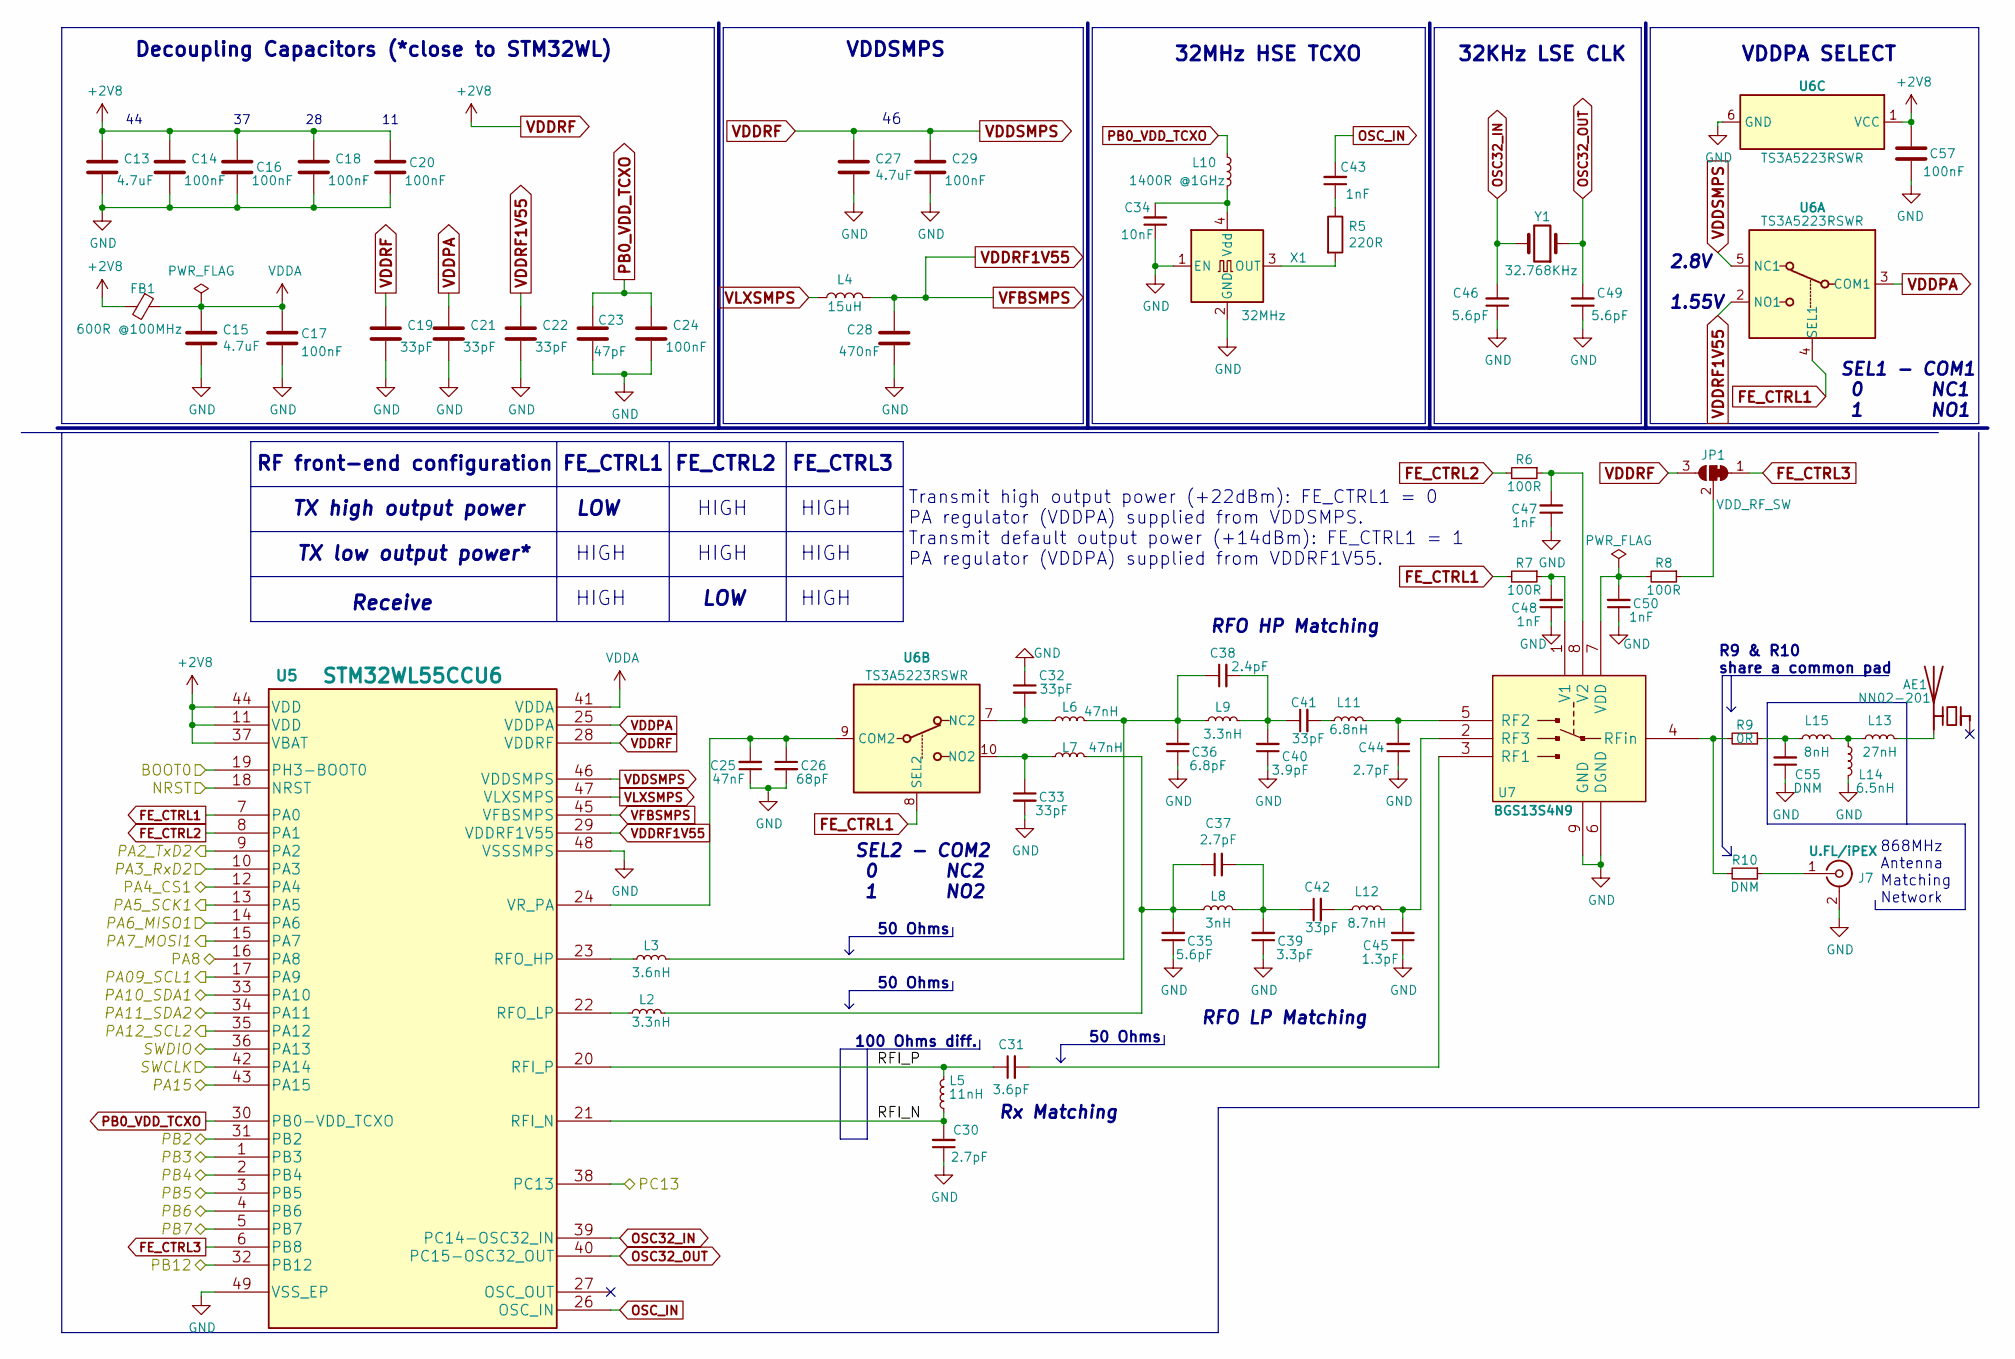
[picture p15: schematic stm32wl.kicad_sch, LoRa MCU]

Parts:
AE1: NN02-201; Antenna_Fractus_NN02-201; MPN NN02-201
C13, C15, C27: 4.7uF; C_0603_1608Metric; MPN CL10A475KO8NNNC
C14, C16, C17, C18, C20, C24, C29, C57: 100nF; C_0402_1005Metric; MPN CC0402KRX7R7BB104
C19, C21, C22: 33pF; C_0402_1005Metric; MPN CC0402FRNPO9BN330
C23: 47pF; C_0402_1005Metric; MPN CC0402JRNPO9BN470
C25: 47nF; C_0402_1005Metric; MPN CC0402KRX7R8BB473
C26: 68pF; C_0402_1005Metric; MPN CC0402JRNPO9BN680
C28: 470nF; C_0603_1608Metric; MPN CC0603KRX7R7BB474
C30, C37, C44: 2.7pF; C_0402_1005Metric; MPN CC0402BRNPO9BN2R7
C31: 3.6pF; C_0402_1005Metric; MPN 0402N3R6B500
C32, C33, C41, C42: 33pF; C_0402_1005Metric; MPN CC0402GRNPO9BN330
C34: 10nF; C_0402_1005Metric; MPN CC0402KRX7R7BB103
C35, C46, C49: 5.6pF; C_0402_1005Metric; MPN CC0402BRNPO9BN5R6
C36: 6.8pF; C_0402_1005Metric; MPN CC0402BRNPO9BN6R8
C38: 2.4pF; C_0402_1005Metric; MPN CC0402BRNPO9BN2R4
C39: 3.3pF; C_0402_1005Metric; MPN CC0402BRNPO9BN3R3
C40: 3.9pF; C_0402_1005Metric; MPN CC0402BRNPO9BN3R9
C43, C47, C48, C50: 1nF; C_0402_1005Metric; MPN CC0402KRX7R7BB102
C45: 1.3pF; C_0402_1005Metric; MPN CC0402BRNPO9BN1R3
C55: DNM; C_0402_1005Metric; MPN DNM
FB1: 600R @100MHz; L_0603_1608Metric; MPN BLM18AG601SN1D
J7: U.FL/iPEX; U.FL_Hirose_U.FL-R-SMT-1_Vertical; MPN U.FL-R-SMT-1(10)
JP1: VDD_RF_SW; SolderJumper-3_P1.3mm_Bridged12_RoundedPad1.0x1.5mm_NumberL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
L2, L9: 3.3nH; L_0402_1005Metric; MPN LQW15AN3N3C80D
L3: 3.6nH; L_0402_1005Metric; MPN LQW15AN3N6C10D
L4: 15uH; L_0805_2012Metric_custom; MPN MLZ2012M150W
L5: 11nH; L_0402_1005Metric; MPN LQW15AN11NG00
L6, L7: 47nH; L_0402_1005Metric; MPN LQW15AN47NJ00#
L8: 3nH; L_0402_1005Metric; MPN LQW15AN3N0B00
L10: 1400R @1GHz; L_0402_1005Metric; MPN BLM15HG102SN1D
L11: 6.8nH; L_0402_1005Metric; MPN LQW15AN6N8H00
L12: 8.7nH; L_0402_1005Metric; MPN LQW15AN8N7H00
L13: 27nH; L_0402_1005Metric; MPN LQW15AN27NG00
L14: 6.5nH; L_0402_1005Metric; MPN LQW15AN6N5G80
L15: 8nH; L_0402_1005Metric; MPN LQW15AN8N0G80
R5: 220R; L_0402_1005Metric; MPN RC0402FR-07220RL
R6, R7, R8: 100R; R_0402_1005Metric; MPN RC0402FR-07100RL
R9: 0R; R_0402_1005Metric; MPN RC0402FR-070RL
R10: DNM; R_0402_1005Metric; MPN DNM
U5: STM32WL55CCU6; QFN-48-1EP_7x7mm_P0.5mm_EP5.45x5.45mm; MPN STM32WL55CCU6
U6: TS3A5223RSWR; UQFN-10_1.4x1.8mm_P0.4mm; MPN TS3A5223RSWR
U7: BGS13S4N9; RFSW_BGS13S4N9E6327XTSA1; MPN BGS13S4N9E6327XTSA1
X1: 32MHz; Crystal_SMD_Abracon_ABM10-4Pin_2.5x2.0mm; MPN ‎TG2520SMN 32.0000M-MCGNNM3‎
Y1: 32.768KHz; Crystal_SMD_NX2012SA_32.768KHz; MPN X1A000061002100

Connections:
/LoRa MCU/BOOT0: U5.19 (PH3-BOOT0); also elsewhere on the board
/LoRa MCU/NRST: U5.18 (NRST); also elsewhere on the board
/LoRa MCU/PA2_TxD2: U5.9 (PA2); also elsewhere on the board
/LoRa MCU/PA3_RxD2: U5.10 (PA3); also elsewhere on the board
/LoRa MCU/PA5_SCK1: U5.13 (PA5); also elsewhere on the board
/LoRa MCU/PA8: U5.16 (PA8); also elsewhere on the board
/LoRa MCU/PA09_SCL1: U5.17 (PA9); also elsewhere on the board
/LoRa MCU/PA10_SDA1: U5.33 (PA10); also elsewhere on the board
/LoRa MCU/PA11_SDA2: U5.34 (PA11); also elsewhere on the board
/LoRa MCU/PA12_SCL2: U5.35 (PA12); also elsewhere on the board
/LoRa MCU/PA15: U5.43 (PA15); also elsewhere on the board
/LoRa MCU/PB2: U5.31 (PB2); also elsewhere on the board
/LoRa MCU/PB3: U5.1 (PB3); also elsewhere on the board
/LoRa MCU/PB4: U5.2 (PB4); also elsewhere on the board
/LoRa MCU/PB5: U5.3 (PB5); also elsewhere on the board
/LoRa MCU/PB6: U5.4 (PB6); also elsewhere on the board
/LoRa MCU/PB7: U5.5 (PB7); also elsewhere on the board
/LoRa MCU/RFI_N: C30.2, L5.1, U5.21 (RFI_N)
/LoRa MCU/RFI_P: C31.1, L5.2, U5.20 (RFI_P)
/LoRa MCU/SWCLK: U5.42 (PA14); also elsewhere on the board
/LoRa MCU/SWDIO: U5.36 (PA13); also elsewhere on the board
/Peripherals/FlashCS: U5.12 (PA4); also elsewhere on the board
/Peripherals/MISO: U5.14 (PA6); also elsewhere on the board
/Peripherals/MOSI: U5.15 (PA7); also elsewhere on the board
/Power Supply/LS1_SENSORS_EN: U5.32 (PB12); also elsewhere on the board
/Power Supply/LS2_FLASH_EN: U5.38 (PC13); also elsewhere on the board
FE_CTRL1: R7.2, U5.7 (PA0), U6.4 (SEL1), U6.8 (SEL2)
FE_CTRL2: R6.2, U5.8 (PA1)
FE_CTRL3: JP1.1 (A), U5.6 (PB8)
GND: C13.2, C14.2, C15.2, C16.2, C17.2, C18.2, C19.2, C20.2, C21.2, C22.2, C23.2, C24.2, C25.1, C26.2, C27.2, C28.2, C29.2, C30.1, C32.1, C33.2, C34.1, C35.1, C36.1, C39.1, C40.1, C44.1, C45.1, C46.1, C47.1, C48.1, C49.1, C50.1, C55.1, C57.2, J7.2 (Ext), L14.1, U5.48 (VSSSMPS), U5.49 (VSS_EP), U6.6 (GND), U7.6 (DGND), U7.9 (GND), X1.1 (EN), X1.2 (GND); also elsewhere on the board
unnamed: AE1.2 (PCB_Trace), L13.2
unnamed: C25.2, C26.1, U5.24 (VR_PA), U6.9 (COM2)
unnamed: C31.2, U7.3 (RF1)
unnamed: C32.2, L6.1, U6.7 (NC2)
unnamed: C33.1, L7.1, U6.10 (NO2)
unnamed: C34.2, L10.2, X1.4 (Vdd)
unnamed: C35.2, C37.1, L2.2, L7.2, L8.1
unnamed: C36.2, C38.1, L3.2, L6.2, L9.1
unnamed: C37.2, C39.2, C42.1, L8.2
unnamed: C38.2, C40.2, C41.1, L9.2
unnamed: C41.2, L11.1
unnamed: C42.2, L12.1
unnamed: C43.1, R5.1
unnamed: C44.2, L11.2, U7.5 (RF2)
unnamed: C45.2, L12.2, U7.2 (RF3)
unnamed: C47.2, R6.1, U7.8 (V2)
unnamed: C48.2, R7.1, U7.1 (V1)
unnamed: C50.2, R8.2, U7.7 (VDD)
unnamed: C55.2, L15.1, R9.1
unnamed: J7.1 (In), R10.1
unnamed: JP1.2 (C), R8.1
unnamed: L2.1, U5.22 (RFO_LP)
unnamed: L3.1, U5.23 (RFO_HP)
unnamed: L13.1, L14.2, L15.2
unnamed: R5.2, X1.3 (OUT)
unnamed: R9.2, R10.2, U7.4 (RFin)
OSC32_IN: C46.2, U5.39 (PC14-OSC32_IN), Y1.2
OSC32_OUT: C49.2, U5.40 (PC15-OSC32_OUT), Y1.1
OSC_IN: C43.2, U5.26 (OSC_IN)
PB0_VDD_TCXO: C23.1, C24.1, L10.1, U5.30 (PB0-VDD_TCXO)
VDDA: C15.1, C17.1, FB1.1, U5.41 (VDDA)
VDDPA: C21.1, U5.25 (VDDPA), U6.3 (COM1)
VDDRF: C13.1, C14.1, C16.1, C18.1, C19.1, C20.1, C27.1, C29.1, C57.1, FB1.2, JP1.3 (B), U5.11 (VDD), U5.28 (VDDRF), U5.37 (VBAT), U5.44 (VDD), U5.46 (VDDSMPS), U6.1 (VCC), U6.5 (NC1); also elsewhere on the board
VDDRF1V55: C22.1, C28.1, L4.2, U5.29 (VDDRF1V55), U5.45 (VFBSMPS), U6.2 (NO1)
VLXSMPS: L4.1, U5.47 (VLXSMPS)

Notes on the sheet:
HIGH
Decoupling Capacitors (*close to STM32WL)
LOW
Receive
TX low output power*
100 Ohms diff.
SEL2 - COM2 0 NC2 1 NO2
FE_CTRL3
50 Ohms
FE_CTRL1
TX high output power
32MHz HSE TCXO
SEL1 - COM1 0 NC1 1 NO1
RFO LP Matching
Rx Matching
VDDSMPS
Transmit high output power (+22dBm): FE_CTRL1 = 0 PA regulator (VDDPA) supplied from VDDSMPS. Transmit default output power (+14dBm): FE_CTRL1 = 1 PA regulator (VDDPA) supplied from VDDRF1V55.
FE_CTRL2
2.8V
32KHz LSE CLK
RF front-end configuration
RFO HP Matching
R9 & R10 share a common pad
868MHz Antenna Matching Network
VDDPA SELECT
1.55V

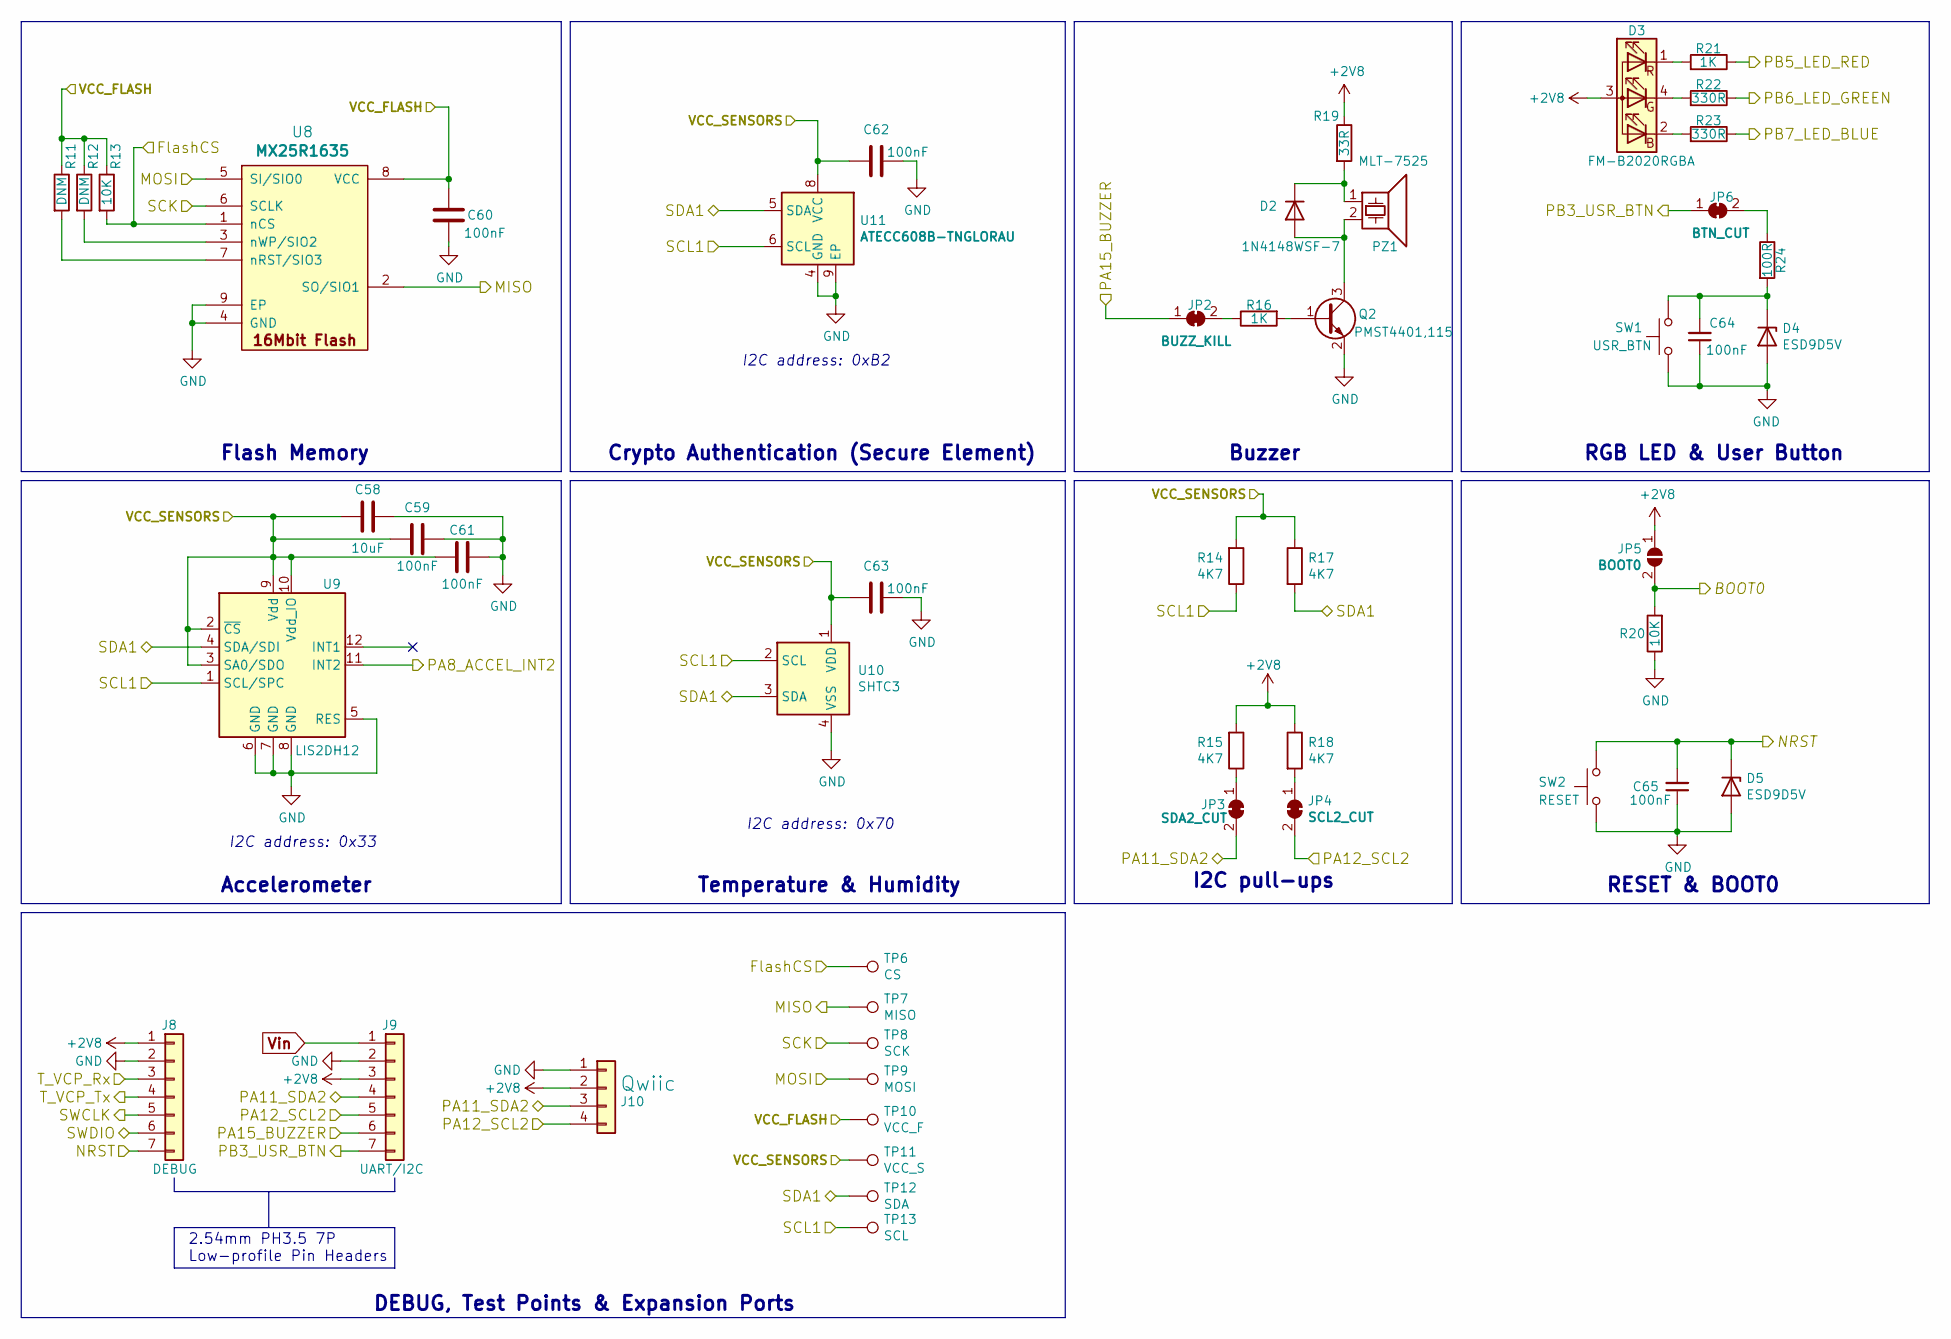
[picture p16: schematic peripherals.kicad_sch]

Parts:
C58: 10uF; C_0603_1608Metric; MPN JMK107ABJ106KA-T
C59, C60, C61, C62, C63, C64, C65: 100nF; C_0402_1005Metric; MPN CC0402KRX7R7BB104
D2: 1N4148WSF-7; D_SOD-323F_custom; MPN 1N4148WSF-7
D3: FM-B2020RGBA; LED_Cree-PLCC4_2x2mm_CW; MPN FM-B2020RGBA-HG
D4, D5: ESD9D5V; D_SOD-923; MPN Diode_SMD:D_SOD-923
J8: DEBUG; PinSocket_1x07_P2.54mm_Vertical
J9: UART/I2C; PinSocket_1x07_P2.54mm_Vertical
J10: Qwiic; JST_SH_BM04B-SRSS-TB_1x04-1MP_P1.00mm_Vertical; MPN BM04B-SRSS-TB(LF)(SN)
JP2: BUZZ_KILL; SolderJumper-2_P1.3mm_Bridged2Bar_RoundedPad1.0x1.5mm
JP3: SDA2_CUT; SolderJumper-2_P1.3mm_Bridged2Bar_RoundedPad1.0x1.5mm
JP4: SCL2_CUT; SolderJumper-2_P1.3mm_Bridged2Bar_RoundedPad1.0x1.5mm
JP5: BOOT0; PinHeader_1x02_P1.27mm_Vertical
JP6: BTN_CUT; SolderJumper-2_P1.3mm_Bridged2Bar_RoundedPad1.0x1.5mm
PZ1: MLT-7525; Buzzer_MLT-7525; MPN MLT-7525
Q2: PMST4401,115; SOT-323_SC-70; MPN PMST4401,115
R11, R12: DNM; R_0402_1005Metric; MPN DNM
R13: 10K; R_0402_1005Metric; MPN AC0402JR-0710KL
R14, R15, R17, R18: 4K7; R_0402_1005Metric; MPN AC0402FR-074K7L
R16, R21: 1K; R_0402_1005Metric; MPN RC0402FR-071KL
R19: 33R; R_0402_1005Metric; MPN AC0402JR-0733RL
R20: 10K; L_0402_1005Metric; MPN AC0402JR-0710KL
R22, R23: 330R; R_0402_1005Metric; MPN AC0402FR-07330RL
R24: 100R; R_0402_1005Metric; MPN RC0402FR-07100RL
SW1: USR_BTN; PushButton_KSC721GLFS; MPN KSC721GLFS
SW2: RESET; SW_SPST_SKSHABE010; MPN SKSHABE010
TP6: CS; TestPoint_Pad_D1.5mm; MPN DNM
TP7: MISO; TestPoint_Pad_D1.5mm; MPN DNM
TP8: SCK; TestPoint_Pad_D1.5mm; MPN DNM
TP9: MOSI; TestPoint_Pad_D1.5mm; MPN DNM
TP10: VCC_F; TestPoint_Pad_D1.5mm; MPN DNM
TP11: VCC_S; TestPoint_Pad_D1.5mm; MPN DNM
TP12: SDA; TestPoint_Pad_D1.5mm; MPN DNM
TP13: SCL; TestPoint_Pad_D1.5mm; MPN DNM
U8: MX25R1635; FLASH_UFDFN-8-MX25R1635F; MPN MX25R1635FZUIL0
U9: LIS2DH12; LGA-12_2x2mm_P0.5mm; MPN LIS2DH12TR
U10: SHTC3; Sensirion_DFN-4-1EP_2x2mm_P1mm_EP0.7x1.6mm; MPN SHTC3
U11: ATECC608B-TNGLORAU; DFN-8-1EP_3x2mm_P0.5mm_EP1.3x1.5mm; MPN ATECC608B-TNGLORAU-C

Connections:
/LoRa MCU/BOOT0: JP5.2 (B), R20.2; also elsewhere on the board
/LoRa MCU/NRST: C65.2, D5.1 (K), J8.7, SW2.2; also elsewhere on the board
/LoRa MCU/PA2_TxD2: J8.4; also elsewhere on the board
/LoRa MCU/PA3_RxD2: J8.3; also elsewhere on the board
/LoRa MCU/PA5_SCK1: TP8.1, U8.6 (SCLK); also elsewhere on the board
/LoRa MCU/PA8: U9.11 (INT2); also elsewhere on the board
/LoRa MCU/PA09_SCL1: R14.1, TP13.1, U9.1 (SCL/SPC), U10.2 (SCL), U11.6 (SCL); also elsewhere on the board
/LoRa MCU/PA10_SDA1: R17.2, TP12.1, U9.4 (SDA/SDI), U10.3 (SDA), U11.5 (SDA); also elsewhere on the board
/LoRa MCU/PA11_SDA2: J9.4, J10.3, JP3.2 (B); also elsewhere on the board
/LoRa MCU/PA12_SCL2: J9.5, J10.4, JP4.2 (B); also elsewhere on the board
/LoRa MCU/PA15: J9.6, JP2.1 (A); also elsewhere on the board
/LoRa MCU/PB3: J9.7, JP6.1 (A); also elsewhere on the board
/LoRa MCU/PB5: R21.1; also elsewhere on the board
/LoRa MCU/PB6: R22.1; also elsewhere on the board
/LoRa MCU/PB7: R23.1; also elsewhere on the board
/LoRa MCU/SWCLK: J8.5; also elsewhere on the board
/LoRa MCU/SWDIO: J8.6; also elsewhere on the board
/Peripherals/FlashCS: R13.2, TP6.1, U8.1 (nCS); also elsewhere on the board
/Peripherals/MISO: TP7.1, U8.2 (SO/SIO1); also elsewhere on the board
/Peripherals/MOSI: TP9.1, U8.5 (SI/SIO0); also elsewhere on the board
/Peripherals/VCC_FLASH: C60.2, R11.1, R12.1, R13.1, TP10.1, U8.8 (VCC); also elsewhere on the board
/Peripherals/VCC_SENSORS: C58.2, C59.2, C61.2, C62.2, C63.2, R14.2, R17.1, TP11.1, U9.2 (~CS), U9.3 (SA0/SDO), U9.9 (Vdd), U9.10 (Vdd_IO), U10.1 (VDD), U11.8 (VCC); also elsewhere on the board
GND: C58.1, C59.1, C60.1, C61.1, C62.1, C63.1, C64.1, C65.1, D4.2 (A), D5.2 (A), J8.2, J9.2, J10.1, Q2.2 (E), R20.1, SW1.2, SW2.1, U8.4 (GND), U8.9 (EP), U9.5 (RES), U9.6 (GND), U9.7 (GND), U9.8 (GND), U10.4 (VSS), U11.4 (GND), U11.9 (EP); also elsewhere on the board
unnamed: C64.2, D4.1 (K), R24.2, SW1.1
unnamed: D2.1 (K), PZ1.1, R19.2
unnamed: D2.2 (A), PZ1.2, Q2.3 (C)
unnamed: D3.1 (RK), R21.2
unnamed: D3.2 (GK), R23.2
unnamed: D3.4 (A), R22.2
unnamed: JP2.2 (B), R16.1
unnamed: JP3.1 (A), R15.1
unnamed: JP4.1 (A), R18.2
unnamed: JP6.2 (B), R24.1
unnamed: Q2.1 (B), R16.2
unnamed: R11.2, U8.7 (nRST/SIO3)
unnamed: R12.2, U8.3 (nWP/SIO2)
VDDRF: D3.3 (BK), J8.1, J9.3, J10.2, JP5.1 (A), R15.2, R18.1, R19.1; also elsewhere on the board
Vin: J9.1; also elsewhere on the board

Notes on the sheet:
I2C pull-ups
Flash Memory
Buzzer
2.54mm PH3.5 7P Low-profile Pin Headers
Temperature & Humidity
Crypto Authentication (Secure Element)
I2C address: 0xB2
I2C address: 0x70
Accelerometer
RESET & BOOT0
DEBUG, Test Points & Expansion Ports
RGB LED & User Button
I2C address: 0x33

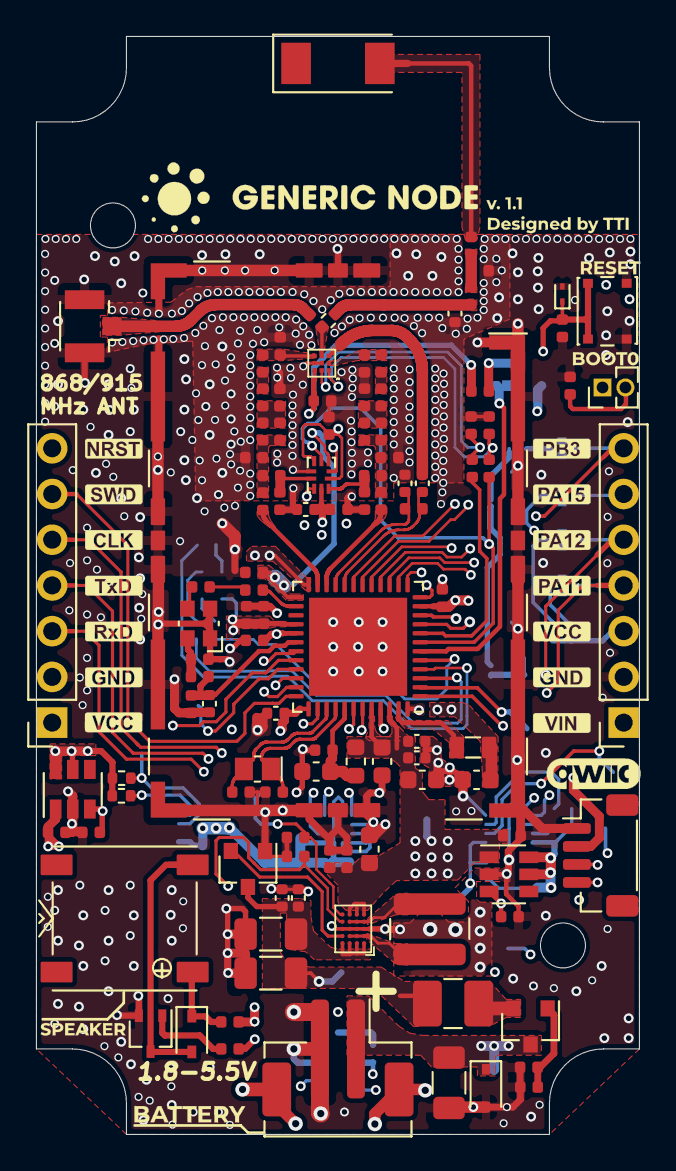
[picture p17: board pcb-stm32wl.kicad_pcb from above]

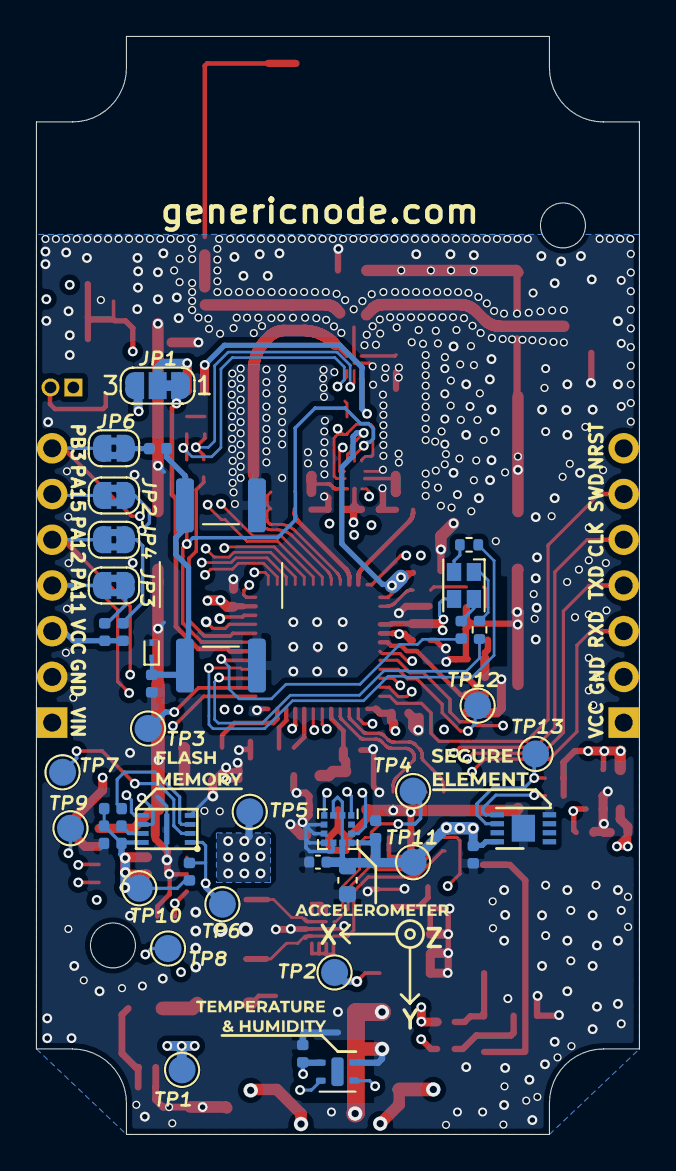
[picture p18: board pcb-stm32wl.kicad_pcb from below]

Board: 4 copper layers, 33.5 x 61.0 mm, 182 parts (45 on the bottom side), 87 nets.

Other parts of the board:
G-ACCELL: LOGO; LAbel_ACCELL_2000px
G-BAT: LOGO; Label_BATTERY_2500px
G-BOOT0: LOGO; Label_BOOT0_4000px
G-CLK: LOGO; PinName_CLK
G-FLASH: LOGO; Label_FLASH_3000px
G-GND, G-GND2: LOGO; PinName_GND
G-GNSE: LOGO; Logo_GN_new_2000px
G-NRST: LOGO; PinName_NRST
G-PA11: LOGO; PinName_PA11
G-PA12: LOGO; PinName_PA12
G-PA15: LOGO; PinName_PA15
G-PB3: LOGO; PinName_PB3
G-QWIIC: LOGO; Logo_qwiic_4000px
G-RST: LOGO; Label_RESET_4000px
G-RXD: LOGO; PinName_RxD
G-SE: LOGO; Label_SE_3000px
G-SPKR: LOGO; Label_Speaker
G-SWD: LOGO; PinName_SWD
G-TH: LOGO; Label_T_H_2000px
G-TXD: LOGO; PinName_TxD
G-VCC, G-VCC2: LOGO; PinName_VCC
G-VIN: LOGO; PinName_VIN
G-version: LOGO; Logo_design_version_2000px

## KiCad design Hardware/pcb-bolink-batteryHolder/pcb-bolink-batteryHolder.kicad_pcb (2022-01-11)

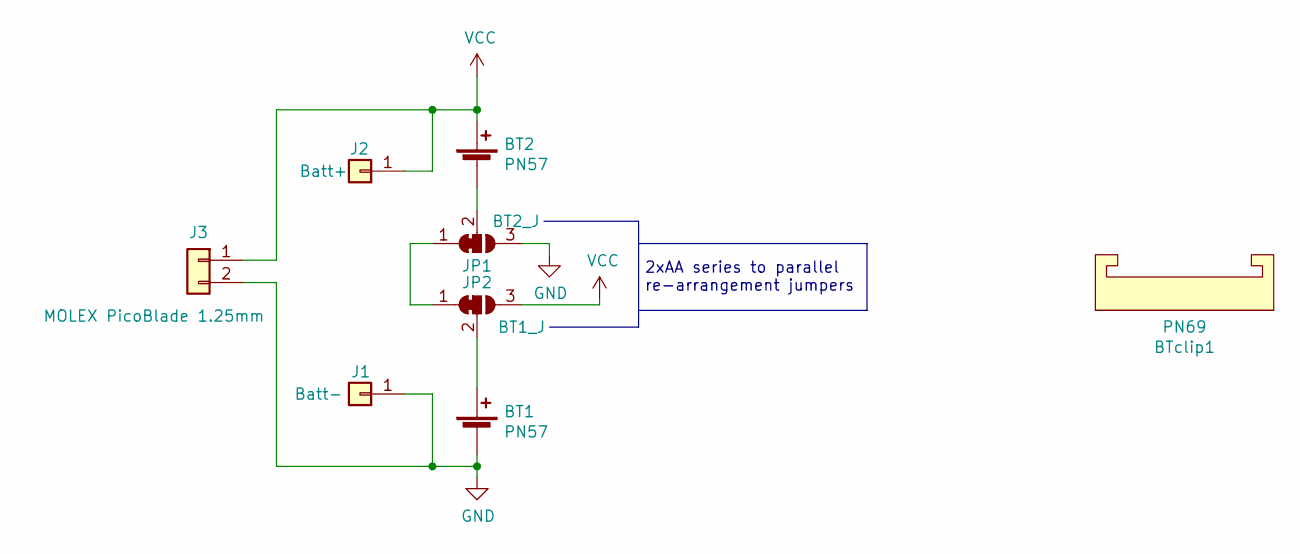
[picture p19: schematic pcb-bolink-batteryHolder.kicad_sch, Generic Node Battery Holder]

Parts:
BT1, BT2: PN57; keystone-PN57; MPN 57
BTclip1: PN69; Keystone_69_clip; MPN 69
J1: Batt-; TestPoint_Keystone_5019_Minature; MPN DNM
J2: Batt+; TestPoint_Keystone_5019_Minature; MPN DNM
J3: MOLEX PicoBlade 1.25mm; Molex_PicoBlade_53398-0271_1x02-1MP_P1.25mm_Vertical; MPN 0533980271
JP1: BT2_J; SolderJumper-3_P1.3mm_Bridged2Bar12_Pad1.0x1.5mm_NumberLabe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
JP2: BT1_J; SolderJumper-3_P1.3mm_Bridged2Bar12_Pad1.0x1.5mm_NumberLabe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

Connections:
GND: BT1.2 (-), J1.1, J3.2, JP1.3 (B)
unnamed: BT1.1 (+), JP2.2 (C)
unnamed: BT2.2 (-), JP1.2 (C)
unnamed: JP1.1 (A), JP2.1 (A)
VCC: BT2.1 (+), J2.1, J3.1, JP2.3 (B)

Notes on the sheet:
2xAA series to parallel re-arrangement jumpers

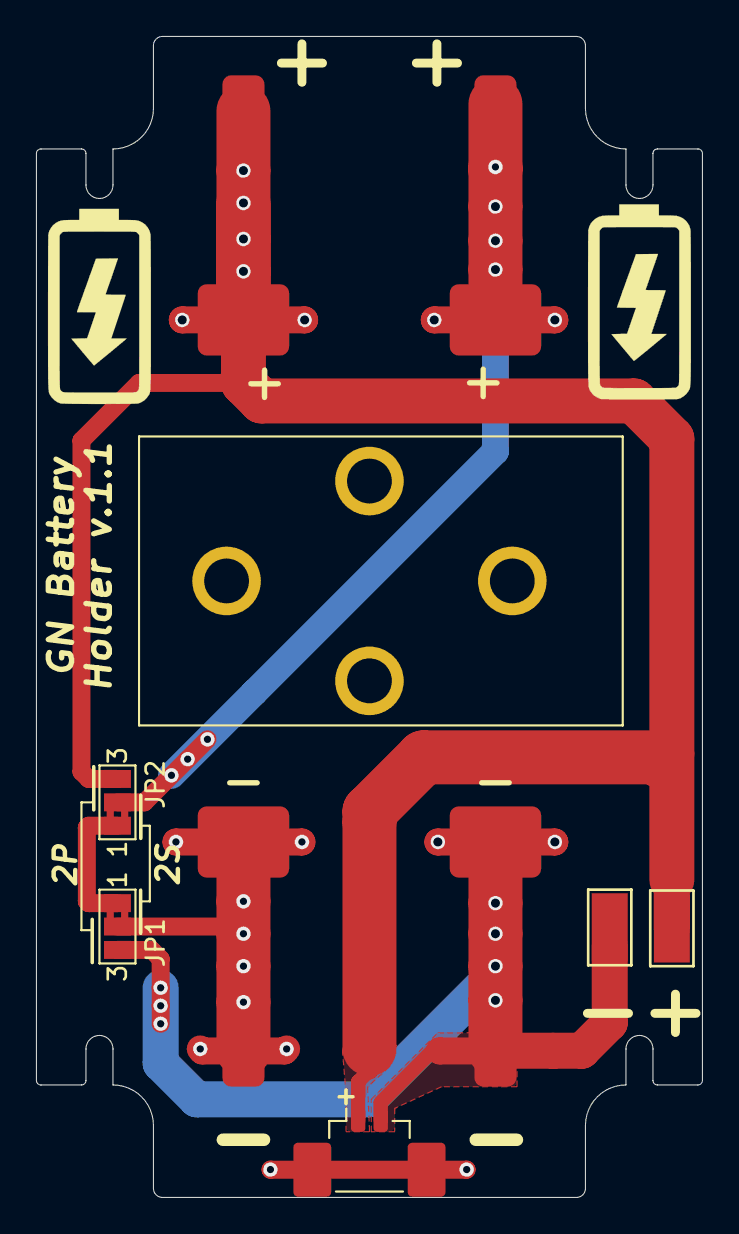
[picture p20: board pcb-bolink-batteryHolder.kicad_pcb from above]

Board: 2 copper layers, 37.0 x 64.5 mm, 10 parts (0 on the bottom side), 5 nets.

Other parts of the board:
G-BT1, G-BT1#2: LOGO; Icon_Battery_1200px

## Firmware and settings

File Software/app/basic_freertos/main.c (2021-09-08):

/** Copyright © 2021 The Things Industries B.V.
 *
 * Licensed under the Apache License, Version 2.0 (the "License");
 * you may not use this file except in compliance with the License.
 * You may obtain a copy of the License at
 *
 *     http://www.apache.org/licenses/LICENSE-2.0
 *
 * Unless required by applicable law or agreed to in writing, software
 * distributed under the License is distributed on an "AS IS" BASIS,
 * WITHOUT WARRANTIES OR CONDITIONS OF ANY KIND, either express or implied.
 * See the License for the specific language governing permissions and
 * limitations under the License.
 */

/**
 * @file main.c
 *
 * @copyright Copyright (c) 2021 The Things Industries B.V.
 *
 */

#include "app.h"
#include "cmsis_os.h"
#include "FreeRTOS_iot_log_task.h"

uint32_t osQueueMsg;
uint32_t Queue_value = 100;

/* Definitions for TxThread */
osThreadId_t TxThreadHandle;
const osThreadAttr_t TxThread_attributes = {
    .name = "TxThread",
    .priority = (osPriority_t)osPriorityBelowNormal,
    .stack_size = 512 * 4};

/* Definitions for RxThread */
osThreadId_t RxThreadHandle;
const osThreadAttr_t RxThread_attributes = {
    .name = "RxThread",
    .priority = (osPriority_t)osPriorityNormal,
    .stack_size = 512 * 4};

/* Definitions for osqueue */
osMessageQueueId_t osqueueHandle;
const osMessageQueueAttr_t osqueue_attributes = {
    .name = "osqueue"};

static void SystemClock_Config(void);
static void Error_Handler(void);

void QueueSendThread(void *argument);
void QueueReceiveThread(void *argument);

static void MX_GPIO_Init(void);

/**
  * @brief  Function implementing the TxThread thread.
  * @param  argument: Not used
  * @retval None
  */
void QueueSendThread(void *argument)
{
  for (;;)
  {
#if (GNSE_TINY_TRACER_ENABLE)
    configPRINTF(("\r\n Send a Tx msg \r\n"));
#endif
    /* Place this thread into the blocked state until it is time to run again.
       The kernel will place the MCU into the Retention low power sleep state
       when the idle thread next runs. */
    osDelay(TX_DELAY);

    /* Send to the queue - causing the queue receive thread to flash its LED.
       It should not be necessary to block on the queue send because the Rx
       thread will already have removed the last queued item. */
    osMessageQueuePut(osqueueHandle, &Queue_value, 100, 0U);
  }
}

/**
* @brief Function implementing the RxThread thread.
* @param argument: Not used
* @retval None
*/
void QueueReceiveThread(void *argument)
{
  osStatus_t status;

  for (;;)
  {
    status = osMessageQueueGet(osqueueHandle, &osQueueMsg, NULL, 100);

    if (status == osOK)
    {
#if (GNSE_TINY_TRACER_ENABLE)
      configPRINTF(("\r\n Received Rx msg \r\n"));
#endif
      if (osQueueMsg == Queue_value)
      {
        GNSE_BSP_LED_On(LED_BLUE);
        osDelay(LED_TOGGLE_DELAY);
        GNSE_BSP_LED_Off(LED_BLUE);
      }
    }
  }
}

int main(void)
{
  /* Reset of all peripherals, Initializes the Flash interface and the Systick. */
  HAL_Init();

  /* Configure the system clock */
  SystemClock_Config();

  MX_GPIO_Init();

  /* Initialize LED */
  GNSE_BSP_LED_Init(LED_BLUE);
  GNSE_BSP_LED_Init(LED_RED);

  /* Init scheduler */
  osKernelInitialize();

#if (GNSE_TINY_TRACER_ENABLE)
  /* Initialize Tracer/Logger */
  GNSE_TRACER_INIT();
  GNSE_app_printAppInfo();

  xLoggingTaskInitialize(mainLOGGING_TASK_STACK_SIZE,
                         mainLOGGING_TASK_PRIORITY,
                         mainLOGGING_MESSAGE_QUEUE_LENGTH);
#endif
  /* Create the queue(s) */
  /* creation of osqueue */
  osqueueHandle = osMessageQueueNew(1, sizeof(uint16_t), &osqueue_attributes);

  /* Create the thread(s) */
  /* creation of TxThread */
  TxThreadHandle = osThreadNew(QueueSendThread, NULL, &TxThread_attributes);

  /* creation of RxThread */
  RxThreadHandle = osThreadNew(QueueReceiveThread, NULL, &RxThread_attributes);

  /* Start scheduler */
  osKernelStart();

  while (1)
  {
    //Should never reach here
  }
}

/**
  * @brief GPIO Initialization Function
  * @param None
  * @retval None
  */
static void MX_GPIO_Init(void)
{
  GPIO_InitTypeDef GPIO_InitStruct = {0};

  /* GPIO Ports Clock Enable */
  __HAL_RCC_GPIOA_CLK_ENABLE();
  __HAL_RCC_GPIOB_CLK_ENABLE();
  __HAL_RCC_GPIOC_CLK_ENABLE();
  __HAL_RCC_GPIOH_CLK_ENABLE();

  /*Configure GPIO pins : PA14 PA12 PA15 PA13
                           PA11 PA10 PA0 PA9
                           PA6 PA1 PA3 PA2
                           PA7 PA4 PA5 PA8 */
  GPIO_InitStruct.Pin = GPIO_PIN_14|GPIO_PIN_12|GPIO_PIN_15|GPIO_PIN_13
                          |GPIO_PIN_11|GPIO_PIN_10|GPIO_PIN_0|GPIO_PIN_9
                          |GPIO_PIN_6|GPIO_PIN_1|GPIO_PIN_3|GPIO_PIN_2
                          |GPIO_PIN_7|GPIO_PIN_4|GPIO_PIN_5|GPIO_PIN_8;
  GPIO_InitStruct.Mode = GPIO_MODE_ANALOG;
  GPIO_InitStruct.Pull = GPIO_NOPULL;
  HAL_GPIO_Init(GPIOA, &GPIO_InitStruct);

  /*Configure GPIO pins : PB15 PB3 PB4 PB7
                           PB9 PB14 PB5 PB8
                           PB13 PB2 PB6 PB12
                           PB1 PB0 PB11 PB10 */
  GPIO_InitStruct.Pin = GPIO_PIN_15|GPIO_PIN_3|GPIO_PIN_4|GPIO_PIN_7
                          |GPIO_PIN_9|GPIO_PIN_14|GPIO_PIN_5|GPIO_PIN_8
                          |GPIO_PIN_13|GPIO_PIN_2|GPIO_PIN_6|GPIO_PIN_12
                          |GPIO_PIN_1|GPIO_PIN_0|GPIO_PIN_11|GPIO_PIN_10;
  GPIO_InitStruct.Mode = GPIO_MODE_ANALOG;
  GPIO_InitStruct.Pull = GPIO_NOPULL;
  HAL_GPIO_Init(GPIOB, &GPIO_InitStruct);

  /*Configure GPIO pins : PC14 PC15 PC13 PC2
                           PC3 PC5 PC1 PC0
                           PC4 PC6 */
  GPIO_InitStruct.Pin = GPIO_PIN_14|GPIO_PIN_15|GPIO_PIN_13|GPIO_PIN_2
                          |GPIO_PIN_3|GPIO_PIN_5|GPIO_PIN_1|GPIO_PIN_0
                          |GPIO_PIN_4|GPIO_PIN_6;
  GPIO_InitStruct.Mode = GPIO_MODE_ANALOG;
  GPIO_InitStruct.Pull = GPIO_NOPULL;
  HAL_GPIO_Init(GPIOC, &GPIO_InitStruct);

  /*Configure GPIO pin : PH3 */
  GPIO_InitStruct.Pin = GPIO_PIN_3;
  GPIO_InitStruct.Mode = GPIO_MODE_ANALOG;
  GPIO_InitStruct.Pull = GPIO_NOPULL;
  HAL_GPIO_Init(GPIOH, &GPIO_InitStruct);

}

/**
  * @brief System Clock Configuration
  * @retval None
  */
void SystemClock_Config(void)
{
  RCC_OscInitTypeDef RCC_OscInitStruct = {0};
  RCC_ClkInitTypeDef RCC_ClkInitStruct = {0};

  /** Configure the main internal regulator output voltage
  */
  __HAL_PWR_VOLTAGESCALING_CONFIG(PWR_REGULATOR_VOLTAGE_SCALE1);
  /** Initializes the CPU, AHB and APB busses clocks
  */
  RCC_OscInitStruct.OscillatorType = RCC_OSCILLATORTYPE_MSI;
  RCC_OscInitStruct.MSIState = RCC_MSI_ON;
  RCC_OscInitStruct.MSICalibrationValue = RCC_MSICALIBRATION_DEFAULT;
  RCC_OscInitStruct.MSIClockRange = RCC_MSIRANGE_11;
  RCC_OscInitStruct.PLL.PLLState = RCC_PLL_NONE;
  if (HAL_RCC_OscConfig(&RCC_OscInitStruct) != HAL_OK)
  {
    Error_Handler();
  }
  /** Configure the SYSCLKSource, HCLK, PCLK1 and PCLK2 clocks dividers
  */
  RCC_ClkInitStruct.ClockType = RCC_CLOCKTYPE_HCLK3 | RCC_CLOCKTYPE_HCLK | RCC_CLOCKTYPE_SYSCLK | RCC_CLOCKTYPE_PCLK1 | RCC_CLOCKTYPE_PCLK2;
  RCC_ClkInitStruct.SYSCLKSource = RCC_SYSCLKSOURCE_MSI;
  RCC_ClkInitStruct.AHBCLKDivider = RCC_SYSCLK_DIV1;
  RCC_ClkInitStruct.APB1CLKDivider = RCC_HCLK_DIV1;
  RCC_ClkInitStruct.APB2CLKDivider = RCC_HCLK_DIV1;
  RCC_ClkInitStruct.AHBCLK3Divider = RCC_SYSCLK_DIV1;

  if (HAL_RCC_ClockConfig(&RCC_ClkInitStruct, FLASH_LATENCY_2) != HAL_OK)
  {
    Error_Handler();
  }
}

/**
  * @brief  This function is executed in case of error occurrence.
  * @return None
  */
static void Error_Handler(void)
{
  while (1)
  {
  }
}

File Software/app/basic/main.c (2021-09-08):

/** Copyright © 2021 The Things Industries B.V.
 *
 * Licensed under the Apache License, Version 2.0 (the "License");
 * you may not use this file except in compliance with the License.
 * You may obtain a copy of the License at
 *
 *     http://www.apache.org/licenses/LICENSE-2.0
 *
 * Unless required by applicable law or agreed to in writing, software
 * distributed under the License is distributed on an "AS IS" BASIS,
 * WITHOUT WARRANTIES OR CONDITIONS OF ANY KIND, either express or implied.
 * See the License for the specific language governing permissions and
 * limitations under the License.
 */

/**
 * @file main.c
 *
 * @copyright Copyright (c) 2021 The Things Industries B.V.
 *
 */

#include "app.h"
#include "GNSE_hal.h"

void led_toggle(uint8_t n_toggles, uint32_t toggle_delay);
void buzzer_play(uint8_t n_plays, uint32_t play_delay);
void secure_element_read_info(void);
void temperature_sensor_read_data_polling(uint8_t n_reads, uint32_t read_delay);
void accelerometer_read_data_polling(uint8_t n_reads, uint32_t read_delay);
void flash_read_write(void);
void battery_report(void);

void uart_rxcallback(uint8_t *rxChar, uint16_t size, uint8_t error)
{
  APP_PPRINTF("\r\n DEBUG_USART data received \r\n");
}

int main(void)
{
  /* Reset of all peripherals, Initializes the Flash interface and the Systick. */
  HAL_Init();
  if (GNSE_HAL_SysClk_Init() != GNSE_HAL_OP_SUCCESS)
  {
    GNSE_HAL_Error_Handler();
  }

  /* Initialize Tracer/Logger */
  GNSE_TRACER_INIT();
  GNSE_TRACER_START_RX(uart_rxcallback);

  GNSE_app_printAppInfo();

  APP_PPRINTF("\r\n Testing on-board peripherals \r\n");

  APP_PPRINTF("\r\n Testing battery monitoring functionality \r\n");
  battery_report();

  APP_PPRINTF("\r\n Testing LED functionality \r\n");
  led_toggle(NUMBER_LED_TOGGLE, LED_TOGGLE_INTERVAL);

  APP_PPRINTF("\r\n Testing secure element functionality \r\n");
  APP_PPRINTF("\r\n 1) Enabling LOAD_SWITCH_SENSORS \r\n");
  GNSE_BSP_LS_Init(LOAD_SWITCH_SENSORS);
  GNSE_BSP_LS_On(LOAD_SWITCH_SENSORS);
  HAL_Delay(LOAD_SWITCH_SENSORS_DELAY_MS);
  GNSE_BSP_Sensor_I2C1_Init();
  APP_PPRINTF("\r\n 2) Attempting to read secure element serial number \r\n");
  secure_element_read_info();

  APP_PPRINTF("\r\n Testing on board sensors functionality \r\n");
  APP_PPRINTF("\r\n Attempting to read sensors data \r\n");
  temperature_sensor_read_data_polling(NUMBER_TEMPERATURE_SENSOR_READ, TEMPERATURE_SENSOR_READ_INTERVAL);
  accelerometer_read_data_polling(NUMBER_ACCELEROMETER_READ, ACCELEROMETER_READ_INTERVAL);

  APP_PPRINTF("\r\n Testing on board external flash functionality \r\n");
  APP_PPRINTF("\r\n 1) Enabling LOAD_SWITCH_FLASH \r\n");
  GNSE_BSP_LS_Init(LOAD_SWITCH_FLASH);
  GNSE_BSP_LS_On(LOAD_SWITCH_FLASH);
  HAL_Delay(LOAD_SWITCH_FLASH_DELAY_MS);

  APP_PPRINTF("\r\n 2) Attempting to read & write to external flash \r\n");
  flash_read_write();

  APP_PPRINTF("\r\n Testing Buzzer functionality \r\n");
  buzzer_play(NUMBER_BUZZER_PLAY, BUZZER_PLAY_INTERVAL);

  APP_PPRINTF("\r\n Finished on-board testing, blinking LEDs forever \r\n");
  while (1)
  {
    GNSE_BSP_LED_Toggle(LED_BLUE);
    HAL_Delay(100);
    GNSE_BSP_LED_Toggle(LED_RED);
    HAL_Delay(100);
    GNSE_BSP_LED_Toggle(LED_GREEN);
    HAL_Delay(100);
  }
  return 0;
}

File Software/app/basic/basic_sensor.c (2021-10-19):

/** Copyright © 2021 The Things Industries B.V.
 *
 * Licensed under the Apache License, Version 2.0 (the "License");
 * you may not use this file except in compliance with the License.
 * You may obtain a copy of the License at
 *
 *     http://www.apache.org/licenses/LICENSE-2.0
 *
 * Unless required by applicable law or agreed to in writing, software
 * distributed under the License is distributed on an "AS IS" BASIS,
 * WITHOUT WARRANTIES OR CONDITIONS OF ANY KIND, either express or implied.
 * See the License for the specific language governing permissions and
 * limitations under the License.
 */

/**
 * @file basic_sensor.c
 *
 * @copyright Copyright (c) 2021 The Things Industries B.V.
 *
 */

#include "app.h"

typedef union
{
    int16_t i16bit[3];
    uint8_t u8bit[6];
} axis3bit16_t;

typedef union
{
    int16_t i16bit;
    uint8_t u8bit[2];
} axis1bit16_t;

void temperature_sensor_read_data_polling(uint8_t n_reads, uint32_t read_delay)
{
    int32_t temperature = 0;
    int32_t humidity = 0;
    int16_t status = 0;
    uint8_t read_counter = 0;
    sensirion_i2c_init();
    if (SHTC3_probe() != SHTC3_STATUS_OK)
    {
        APP_PPRINTF("\r\n Failed to initialize SHTC3 Temperature Sensor\r\n");
    }
    for (read_counter = 0; read_counter < n_reads; read_counter++)
    {

        status = SHTC3_measure_blocking_read(&temperature, &humidity);
        if (status == SHTC3_STATUS_OK)
        {
            //Remove the division by 1000 to observe the higher resolution
            APP_PPRINTF("\r\n Measured Temperature: %d'C & Relative Humidity: %d \r\n", temperature / 1000, humidity / 1000);
        }
        else
        {
            APP_PPRINTF("\r\n Failed to read data from SHTC3 sensor \r\n");
        }
        HAL_Delay(read_delay);
    }
}

void accelerometer_read_data_polling(uint8_t n_reads, uint32_t read_delay)
{
    axis3bit16_t data_raw_acceleration;
    axis1bit16_t data_raw_temperature;
    float acceleration_mg[3];
    float temperature_degC;
    uint8_t whoamI;
    stmdev_ctx_t dev_ctx;
    uint8_t read_counter = 0;
    LIS2DH12_init(&dev_ctx);

    /* Check device ID */
    lis2dh12_device_id_get(&dev_ctx, &whoamI);
    if (whoamI != LIS2DH12_ID)
    {
        APP_PPRINTF("\r\n Failed to initialize LIS2DH12 Accelerometer\r\n");
        return;
    }

    /* Enable Block Data Update. */
    lis2dh12_block_data_update_set(&dev_ctx, PROPERTY_ENABLE);

    /* Set Output Data Rate to 1Hz. */
    lis2dh12_data_rate_set(&dev_ctx, LIS2DH12_ODR_1Hz);

    /* Set full scale to 2g. */
    lis2dh12_full_scale_set(&dev_ctx, LIS2DH12_2g);

    /* Enable temperature sensor. */
    lis2dh12_temperature_meas_set(&dev_ctx, LIS2DH12_TEMP_ENABLE);

    /* Set device in continuous mode with 12 bit resol. */
    lis2dh12_operating_mode_set(&dev_ctx, LIS2DH12_HR_12bit);

    HAL_Delay(read_delay);

    /* Read samples in polling mode (no int) */
    for (read_counter = 0; read_counter < n_reads; read_counter++)
    {
        lis2dh12_reg_t reg;

        /* Read output only if new value available */
        lis2dh12_xl_data_ready_get(&dev_ctx, &reg.byte);
        if (reg.byte)
        {
            /* Read accelerometer data */
            memset(data_raw_acceleration.u8bit, 0x00, 3 * sizeof(int16_t));
            lis2dh12_acceleration_raw_get(&dev_ctx, data_raw_acceleration.u8bit);
            acceleration_mg[0] =
                lis2dh12_from_fs2_hr_to_mg(data_raw_acceleration.i16bit[0]);
            acceleration_mg[1] =
                lis2dh12_from_fs2_hr_to_mg(data_raw_acceleration.i16bit[1]);
            acceleration_mg[2] =
                lis2dh12_from_fs2_hr_to_mg(data_raw_acceleration.i16bit[2]);

            APP_PPRINTF("\r\n Accelerometer acceleration [mg]: X: %4.2f\t Y: %4.2f\t Z: %4.2f\r\n",
                        acceleration_mg[0], acceleration_mg[1], acceleration_mg[2]);
        }

        lis2dh12_temp_data_ready_get(&dev_ctx, &reg.byte);
        if (reg.byte)
        {
            /* Read temperature data */
            memset(data_raw_temperature.u8bit, 0x00, sizeof(int16_t));
            lis2dh12_temperature_raw_get(&dev_ctx, data_raw_temperature.u8bit);
            temperature_degC =
                lis2dh12_from_lsb_hr_to_celsius(data_raw_temperature.i16bit);

            APP_PPRINTF("\r\n Accelerometer Temperature sensor [degC]: %6.2f\r\n",
                        temperature_degC);
        }
        HAL_Delay(read_delay);
    }
}

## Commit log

2020-06-10 Initial schematics added
    added KiCAD v5 design files and PDF export of schematics
    [LoRa-MCU.sch, ST-Node-V0.1.kicad_pcb, ST-Node-V0.1.ods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]
2020-06-18 dev, doc,: Add HW schematics path & ignore bak files
2020-06-18 sch: Swap couple of pins and fix a HW bug
    [LoRa-MCU.sch, ST-Node-V0.1.kicad_pcb, ST-Node-V0.1.sch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]
2020-06-18 doc: Fix README.MD Schematics URL
2020-06-18 sch, pcb: Improve pcb layout, swap sch pins
    [LoRa-MCU.sch, ST-Node-V0.1-BOM.ods, ST-Node-V0.1.kicad_pcb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]
2020-07-02 pcb, doc: Add final production files, add interaction PnP iBOM
    dev: Add gitignore for KiCAD files
    all: Delete unused media files
    [LoRa-MCU.sch, ST-Node-V0.1-BOM.ods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]
2020-07-06 lib: Add initial board support package module
2020-07-06 lib: Add LED control functions
2020-07-06 lib: Add push button control APIs
2020-07-06 lib: Add load switches APIs
2020-07-06 lib: Add initial battery monitoring APIs
2020-07-08 all: Add STM32WL HAL files and templates
2020-07-08 app, dev: Add a basic led toggling app with normal clock
2020-07-20 app: Clean-up basic LED toggle app
2020-07-20 Squashed 'Software/target/STM32WLxx_HAL_Driver/' content from commit aaf161f
    git-subtree-dir: Software/target/STM32WLxx_HAL_Driver
    git-subtree-split: aaf161f411eab041aeb2b4d424dc17327c02dacf
2020-07-21 dev, app: Add minor path fixes to CMAKE and remove unused headers
    dev: Remove personal paths
    dev: Remove untracked launcher
    [main.c, stm32wlxx_it.c]
2020-07-28 all: Add UART RX and TX support with ST advanced trace lib
2020-07-31 lib, app: Add BSP sensor I2C bus support and SHTC3 driver
2020-08-07 lib: Add MX25R16F external SPI flash support with ST HAL bridge
2020-08-07 app: Add external SPI flash basic init and basic test
2020-08-12 Squashed 'Software/target/STM32WLxx_HAL_Driver/' changes from aaf161f..504f73e
    504f73e lib: Update from CMSIS V5.0.4 to CMSIS V5.1.0
    e172617 lib: Update with STM32WL 0.7 HAL driver
    git-subtree-split: 504f73e49b6d7abb054c5a5cb25cbf1b97dff7e9
    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
2020-08-13 lib: Add accelerometer lib with ST hal bridge
    doc: Add lib docs about the accelerometer
2020-08-13 lib: Add float printing capability for application layer debug prints
2020-08-13 app: Add accelerometer basic read and restructured function calls
    all: Update with minor astyle fixes
    [basic_sensor.c, main.c]
2020-08-17 lib: Add TIM2 and PWM support for Buzzer
2020-08-17 app: Add Buzzer basic init and basic test
    [main.c, stm32wlxx_it.c]
2020-08-21 lib: Support Buzzer pin reset in OFF state to reduce power consumption
2020-08-30 Squashed 'Software/lib/STM32WLxx_LoRaWAN/' content from commit 3e4794b
    git-subtree-dir: Software/lib/STM32WLxx_LoRaWAN
    git-subtree-split: 3e4794b4b2bd78c60c97202f31f7dff4e8834c38
2020-08-30 lib: Update to preserve compatibility with STM32WL V0.7 FW
2020-08-30 lib: Add BSP radio support and pin mapping
2020-08-30 lib: Support global object access (subGHz and USART TX DMA)
2020-09-15 lib: Add BSP support for SE I2C2
2020-10-07 lib: Improve debug uart init
    lib: fix incorrect I2C clock assignment
    lib: Add I2C fastmode pulse
2020-10-07 app: Add minor UART and app fixes
    [basic_se_flash.c, main.c, stm32wlxx_it.c]
2020-11-16 hw: Restructure maintained files to allow for versioning
    pcb: Remove freecad files
    doc: Update readme with new HW folder structure
    [LoRa-MCU.sch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]
2020-11-24 app: Add a basic FreeRTOS blinking LED app
2020-11-27 doc: Update issue links and guides with new repo name
    [main.c, sys_app.c]
2020-12-09 pcb,sch: Add V0.2 HW design with external battery holder
    [LoRa-MCU.sch, pcb-bolink-batteryHolder.kicad_pcb, pcb-bolink-batteryHolder.sch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]
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2021-01-07 dev: Add STM32CubeIDE debug build ignores
    dev: Prepend root to ignores
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2021-01-26 lib: Add application layer notification to Radio driver
2021-01-26 dev: Update app STM32CubeIDE with new util structure
2021-01-28 dev: Corrected GNSE_bsp capitalisation to match library files
    [stm32wlxx_it.c]
2021-02-10 Squashed 'Software/target/stm32wlxx_hal_driver/' content from commit 5dc2a4b
    git-subtree-dir: Software/target/stm32wlxx_hal_driver
    git-subtree-split: 5dc2a4bc1a9506b7100a1a5cccf8ba411f5d9606
2021-02-16 lib, app: Fix Linux compilation and minor typos
    [app_conf.h, basic_sensor.c, main.c]
2021-02-17 app: Fix minor typos
    [app_conf.h, bootloader.h, lora_app.c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]
2021-02-22 lib: Update subghz (radio driver) from v0.7 to ST official v1.0
2021-02-23 dev: Fix typos in STM32CubeIDE files
2021-02-23 dev: Update STM32CubeIDE support to reflect ST v1.0 changes
    dev: Fix Linux compilation issue
    dev: Fix linux compilation
    dev: Fix Linux compilation
2021-03-03 app,lib: Add accelerometer interrupt configuration
    app: Added exti9-5 interrupt handler
    app: Added accelerometer interrupt pin definitions
    app: Set Tx interval to accelerometer interrupt event
    app: Error handling made more consistent
    [lora_app.c, stm32wlxx_it.c]
2021-03-03 app,lib: Fix function placement and comments
    app: Moved accelerometer GPIO init to the GNSE BSP files
    app: Moved port configuration to app_conf
    app: Changed payload to logging counter
    app: New message timer set after failed attempt
    app: Fixed some comments
    app: Added comments for the register initialisation
    app: Edited comments for the Freefall defines
    app: Set threshold based on ST recommendations
    app: Removed extra space in GNSE_bsp_gpio comments
    [app_conf.h, lora_app.c]
2021-03-03 app,lib: Remove unused variables and functions
    app: Removed Tx on button press
    app: Removed unused variable
    app: Global dev_ctx made local var
    app: Removed Tx on timer/button functions
    app: Defined interrupt priority for accelerometer
    app: Removed unused dutycycle time
    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
2021-03-03 app: Fix accelerometer function placements and naming conventions
    app: Added ACC prefix to freefall defines
    app: Defined accelerometer return types
    app: Moved accelerometer functions to sys_app
    app: Set accelerometer function to result_t type
    [app_conf.h, lora_app.c, sys_app.c]
2021-03-03 app,lib: Fix minor typos and issues
    app: Added free-fall disable function
    app: Fixed minor typos
    app: Fixed typo for STM32CubeIDE
    app: Removed unused led/Rx functions
    lib,app: Moved functions to more appropriate places
    lib: Set accelerometer priority to lowest value
    app: Moved ACC handler to own function
    app,lib: Fixed confusing comments
    app: Readded RX function
    [app_conf.h, lora_app.c, sys_app.c]
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2021-03-18 doc: Add claiming tutorial link and minor spelling fixes
    [sys_app.c]
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2021-03-25 lib: Adapt all libs to use GNSE Tracer (TINY and ADVANCED))
2021-03-25 app,dev: Update apps to use GNSE advanced tracer
2021-03-25 app,dev: Update freertos apps and bootloader to use GNSE tiny tracer
2021-03-25 dev: Add GNSE TRACER app support to STM32CubeIDE
2021-03-25 doc: Fix minor spelling issues found with system tracer PR
    [app_conf.h, lora_app.c, main.c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]
2021-04-19 lib,app: Add downlink handler with buzzer tunes
    [app_conf.h, lora_app.c, stm32wlxx_it.c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]
2021-04-19 dev: Add SPIFFS lib support to apps CMAKE and STM32CubeIDE
2021-04-20 sch, doc: Adding updated BOM files
    [pcb-bolink-batteryHolder.xlsx, pcb-stm32wl.ods, pcb-stm32wl.xlsx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]
2021-04-23 compiler: Add startup and linker support for threadx (AzureRTOS)
2021-04-23 lib, doc: Add threadx (AzureRTOS) kernel and support utilities
    lib: Adjust system clock t0 48Mhz
    doc: Fix some spelling mistakes in lib description
2021-04-23 app, doc, dev: Add basic_azurertos app
    app: Improve basic_azurertos app comments
    doc: Add basic_azurertos config link
    dev: Add basic_azurertos STM32CubeIDE support
2021-06-09 app,doc : Add sensors_lorawan application and an example payload decoder
2021-06-29 app,dev: Add basic_fuota app
    dev: Fix linux compilation of packages
    [app_conf.h, lora_app.c, lorawan_conf.h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]
2021-07-19 app: Improve free fall low power current to ~44uA
2021-09-08 dev: Add STM32CubeIDE support for common app APIs and app name
2021-10-11 app: Add accelerometer reading delay to basic app
2022-01-06 hw: Migrate sch and pcb files to KiCad v6
    [pcb-bolink-batteryHolder.kicad_pcb, pcb-bolink-batteryHolder.kicad_sch, pcb-bolink-batteryHolder.sch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]
2022-01-06 doc: Update BOM files
    [pcb-bolink-batteryHolder.xlsx, pcb-stm32wl.xlsx]
2022-01-07 sch, doc: Eev update
    [pcb-bolink-batteryHolder.kicad_pcb, pcb-bolink-batteryHolder.kicad_sch, pcb-stm32wl.kicad_pcb]
2022-02-23 app: Improve sensors app, fix temperature offset
    [app_conf.h, lora_app.c, lorawan_conf.h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]
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2022-04-04 app: Add sensor sample error handling to avoid NULL values in uplinks
    [lora_app.c]
2022-04-21 app: Change sensor uplink interval to minutes
    app: Disable Debug flags
2022-08-04 fix: TCXO control voltage setting bug
    [app_conf.h]
2022-09-19 fix: LoRaWAN sensors SE app
    Fix: App conf file
    fix: LoRaWAN sensors SE app
    [app_conf.h]
2022-09-20 hw: Adding updated BOM files by Arrow
    [pcb-bolink-batteryHolder_Arrow.xlsx, pcb-stm32wl_Arrow.xlsx]
2023-04-17 fix: Battery Monitor enable/disable sequence
    [pcb-stm32wl.kicad_pcb, stm32wl.kicad_sch]
